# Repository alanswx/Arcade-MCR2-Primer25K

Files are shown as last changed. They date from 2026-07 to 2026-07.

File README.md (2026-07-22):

# Bally Midway MCR2 Arcade Core for Gowin Tang FPGAs

Standalone port of the Bally Midway MCR-2 arcade hardware (Tron, Domino
Man, Satan's Hollow, Wacko, Kozmik Kroozr, Two Tigers) for Sipeed Tang
FPGA boards — no MiSTer/HPS required. The flagship target is the **Tang
Console 60K**: all six games in one bitstream, selected at runtime from an
on-screen menu, with ROMs loaded from a microSD card.

| Board | Status |
|---|---|
| **Tang Console 60K** (GW5AT-60) | All six games + OSD menu; 720p HDMI with audio (DDR3 framebuffer); analog RGB at 31/15 kHz for real cabinets; USB gamepad; SD ROM loading |
| Tang Primer 25K (GW5A-25) | Domino Man over HDMI (single game per build, BSRAM-limited) |
| Tang Console 138K (GW5AST-138) | Stale — needs the 60K backport |

New here? Read [handoff_v4_60k_multicore.md](handoff_v4_60k_multicore.md)
for the current platform state and family runway.

Deeper docs: build gotchas and architecture notes in [CLAUDE.md](CLAUDE.md),
open issues in [TODO.md](TODO.md), bench hookup in
[docs/bench_wiring.md](docs/bench_wiring.md), cabinet shield spec in
[docs/universal_mcr_shield_spec.md](docs/universal_mcr_shield_spec.md),
porting plan for the other MCR generations in
[docs/mcr_core_roadmap.md](docs/mcr_core_roadmap.md).

---

## 1. Generate the ROM hex tables

ROM zips (MAME sets) go in `roms/` — they are **not** in the repo. Then,
from the repo root:

```sh
python3 tools/merge_roms.py tron     # or domino / shollow / wacko / kroozr / twotiger
```

This writes the `rom_*.hex` tables the build bakes into BSRAM and sets the
board's `game_config.vh`. On the 60K the baked game only decides **what
boots with no SD card** — every game is reachable at runtime from the OSD.

## 2. Build

Headless (recommended; macOS paths shown — see CLAUDE.md for why the IDE
flow needs extra care):

```sh
GWLIB=/Applications/GowinIDE.app/Contents/Resources/Gowin_EDA/IDE/lib
GW=/Applications/GowinIDE.app/Contents/Resources/Gowin_EDA/IDE/bin/gw_sh
cd mcr2_console60k
DYLD_LIBRARY_PATH="$GWLIB" DYLD_FRAMEWORK_PATH="$GWLIB" "$GW" build.tcl
```

The bitstream lands at `mcr2_console60k/impl/pnr/mcr2_console60k.fs`.
Prebuilt images for all six games are kept in `bitstreams/`.

IDE builds work too (open `mcr2_console60k/mcr2_console60k.gprj`, Run All)
but several project settings must be exactly right — read the Gotchas
table in CLAUDE.md first; in particular **Place & Route → Place Option
must be 2** or HDMI silently dies.

## 3. Flash the board

With [openFPGALoader](https://github.com/trabucayre/openFPGALoader)
(`brew install openfpgaloader`), board connected over USB-C:

```sh
# quick test - loads SRAM, lost at power-off
openFPGALoader -b tangconsole bitstreams/console60k_tron.fs

# make it the POWER-ON default - writes the SPI flash
openFPGALoader -b tangconsole -f bitstreams/console60k_tron.fs
```

The `-f` form replaces whatever was in flash (e.g. NESTang) — reflash that
the same way if you want it back. The Gowin Programmer GUI works as well
(External Flash Mode → exFlash Erase, Program).

## 4. Make the SD card (all six games, switchable from the menu)

The ROM pack lives in **raw sectors starting at sector 2048** (1 MiB in) —
no filesystem involved, and it coexists with a normally-formatted card
(standard SD formatting starts the first partition at 4 MiB+; existing
files are untouched).

```sh
python3 tools/make_rompack.py                 # builds mcr_rompack.img from roms/
sudo python3 tools/write_rompack.py           # lists candidate cards
sudo python3 tools/write_rompack.py disk4     # writes + verifies (macOS)
```

`write_rompack.py` refuses to touch anything that is not a removable disk,
refuses cards whose partitions would overlap the pack, and verifies the
header after writing. On Linux/Windows use the `dd`/Win32DiskImager recipe
that `make_rompack.py` prints.

Put the card in the **console's** microSD slot. Every game you select in
the OSD is saved to the card (a reserved sector below the pack), and the
next power-on boots straight back into it - so a cabinet owner picks a
game once and it sticks. With no card (or a blank prefs sector) the
baked-in game boots.

## 5. Play

- **USB gamepad** in the left USB-A port: D-pad = joystick, A = Button 1,
  Start = Start 1, Select = Coin 1 (B/X/Y vary per game — see the input
  maps in `mcr2_console60k_top.sv`).
- **Select+Start opens the game-select menu** on every video output:
  Up/Down move, A loads the highlighted game from the SD card, B exits.
  The screen freezing (HDMI) or dropping sync (analog) for ~1 s after
  pressing A is the ROM reload, not a crash.
- Board keys: AA13 = reset, AB13 = Coin 1.
- HDMI is always live at 720p. Analog RGB comes out of the J10 header
  (31 kHz VGA, or jumper J10-37 to GND for native 15 kHz arcade timing) —
  wiring recipes in [docs/bench_wiring.md](docs/bench_wiring.md).
- A UART status beacon prints on the USB-C serial port (115200 8N1) for
  case-closed debugging — field decoding in docs/bench_wiring.md.

## 6. Cabinet integration

The goal is a drop-in board for real MCR cabinets: analog 15 kHz RGB,
original harness connectors, physical DIPs for game options. For anyone
building the PCB: the **frozen 40-pin header sheet is
[docs/shield_j10_pinout.md](docs/shield_j10_pinout.md)** — one header
carries video, audio and all controls (inputs via a 74HC165 chain that
covers every game, outputs via 74HC595). The consolidated electrical spec
is [docs/universal_mcr_shield_spec.md](docs/universal_mcr_shield_spec.md);
per-game harness pinouts are in
[docs/mcr_game_input_matrix.md](docs/mcr_game_input_matrix.md).

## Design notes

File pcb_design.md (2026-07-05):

# Universal MCR Daughterboard PCB Design Specification

This document details the physical layout, component placement, and schematic netlist for the **Universal Bally Midway MCR Cabinet Interface Shield** designed to host the **Tang Console 60K/138K**. It includes an ASCII floorplan and a **KiCad Python Script** to programmatically generate the board layout.

---

## 1. PCB Floorplan (ASCII Layout Sketch)

The PCB is designed as a roomy carrier shield (approx. **135mm x 95mm**) that sits directly underneath the Tang Console board, exposing the original cabinet connectors along the top and bottom edges.

KiCad Layout Render

```text
+-----------------------------------------------------------------------------------+
|  [J2: P1 Ctrl]     [J3: Coin/Start]      [Video Output]       [Power Input +12V]  |
|  (Molex 15-pin)      (Molex 5-pin)        (Molex 9-pin)         (Screw Terminal)  |
|                                                                                   |
|    +---------------------------------------------------------+   +------------+   |
|    |               Tang Console 60K/138K Socket              |   | 5V Buck    |   |
|    |               (Exposes 2x20 Pin Header 1)               |   | Regulator  |   |
|    +---------------------------------------------------------+   +------------+   |
|                                                                                   |
|  [Optocouplers]                                                  [Audio Amp]      |
|  (TLP281-4)                                                      (LM386 + Caps)   |
|                                                                                   |
|    +---------------------------------------------------------+   [Audio Out]      |
|    |               Tang Console 60K/138K Socket              |   (Screw Term)     |
|    |               (Exposes 2x20 Pin Header 2)               |                    |
|    +---------------------------------------------------------+                    |
|                                                                  [DAC Resistors]  |
|                                                                  (R2R Networks)   |
|  [J5: P2 / Trackball]                 [J4: Opt X / Spinner]                       |
|  (Molex 19-pin)                         (Molex 10-pin)                            |
|                                                                                   |
|                     [SW1: Game Sel]      [SW2: Options]                           |
|                     (8-Position DIP)     (8-Position DIP)                         |
+-----------------------------------------------------------------------------------+
```

---

## 2. Schematic Netlist Configuration

The daughterboard connects the Tang Console 2x20 headers directly to the cabinet connectors and onboard modules:

### Power Distribution Nets
*   `+12V_CAB` $\rightarrow$ Screw Terminal Pin 1 $\rightarrow$ Audio Amp VCC, Buck Regulator Input.
*   `GND` $\rightarrow$ Common ground across all connectors, switches, and regulators.
*   `+5V_REG` $\rightarrow$ Buck Regulator Output $\rightarrow$ Tang Console 5V input pins (Header 1).
*   `+3.3V_FPGA` $\rightarrow$ Tang Console 3.3V output pins (Header 2) $\rightarrow$ DIP Switch pull-ups, optocoupler output pull-ups.

### Video DAC Nets
*   `cab_r[2:0]` $\rightarrow$ R2R Resistor Network $\rightarrow$ `MCR_RED` $\rightarrow$ `Video-1`
*   `cab_g[2:0]` $\rightarrow$ R2R Resistor Network $\rightarrow$ `MCR_GREEN` $\rightarrow$ `Video-3`
*   `cab_b[2:0]` $\rightarrow$ R2R Resistor Network $\rightarrow$ `MCR_BLUE` $\rightarrow$ `Video-5`
*   `cab_hs` $\rightarrow$ NPN Transistor Buffer $\rightarrow$ `MCR_HSYNC` $\rightarrow$ `Video-8`
*   `cab_vs` $\rightarrow$ NPN Transistor Buffer $\rightarrow$ `MCR_VSYNC` $\rightarrow$ `Video-9`
*   `Video GND` $\rightarrow$ Connected directly to `GND` $\rightarrow$ `Video-2, Video-4, Video-6`

---

## 3. KiCad PCB Python Generation Script

To prevent code desynchronization, the Python generator script is maintained separately at [`tools/generate_pcb.py`](file:///Users/alans/Documents/development/Arcade-MCR2-TangFPGA/tools/generate_pcb.py).

### How to Run the Generator:
To programmatically generate the layout or apply changes to coordinates, execute the script from your terminal using KiCad's bundled Python interpreter:

```bash
# Run the script to generate or update 'mcr_shield.kicad_pcb'
/Applications/KiCad/KiCad.app/Contents/Frameworks/Python.framework/Versions/3.9/bin/python3 tools/generate_pcb.py
```

After running the script, the updated board database is saved directly to [`mcr_shield.kicad_pcb`](file:///Users/alans/Documents/development/Arcade-MCR2-TangFPGA/mcr_shield.kicad_pcb). You can open this file in KiCad PCB Editor to view and route the traces.

---

## 4. Power Supply & Level-Shifting Specification

Arcade cabinets are electrically noisy environments. Proper power isolation and input level-shifting are critical to ensure that the delicate FPGA logic is not damaged and does not suffer from glitches.

### A. Power Supplies Required
Original MCR cabinets deliver:
1.  **+5V DC (Logic):** Used to power TTL ICs on the original boards.
2.  **+12V DC (Audio):** Used to run the audio power amplifiers.
3.  **-5V DC (Bias):** Used only by legacy dynamic RAMs (4116 DRAM). 
    *   *Our core runs 100% on-chip static BRAM, so **we do not need the -5V rail at all**.*

**How we power the FPGA:**
*   We route the cabinet's **+12V DC rail** to an onboard **step-down Buck Regulator module** (e.g. LM2596 or similar buck converter) on our shield. The regulator outputs a rock-solid, filtered **+5.0V DC** (1.5A rating) which is routed directly to the Tang Console's 5V input pin.
*   This isolates the FPGA from noise on the cabinet's main +5V logic lines and prevents brownouts when solenoids or coin door lights trigger.

### B. Input Level-Shifting (Cabinet Controls)
*   **The Hazard:** Standard arcade cabinet switches can pick up high-voltage static shocks (ESD) or line noise from the CRT monitor. Since the Gowin FPGA GPIOs are **strictly 3.3V tolerant**, connecting long wire loops directly to the pins will eventually destroy the FPGA.
*   **The Solution (Optocouplers):** We place **TLP281-4 (or EL817-4) quad optocouplers** on all cabinet input lines (joysticks, buttons, coins).
    *   The cabinet loop runs at +5V/12V through the optocoupler's input LED.
    *   When a switch is closed, it triggers the internal LED.
    *   The output photo-transistor bridges the FPGA GPIO directly to `GND` (pulled up to `+3.3V` internally).
    *   This provides **100% electrical isolation** between the cabinet and the FPGA.

### C. Output Level-Shifting (Video Sync)
*   **Sync Signals:** Arcade CRT monitors expect **5V TTL composite sync** signals. The FPGA outputs 3.3V. While some monitors may work, it is best practice to place a buffer IC (like a **74LVC244** or **74HCT244**) powered by +5V to step up the 3.3V HSync, VSync, and CSync signals to solid 5V TTL levels before routing them to the video connector.
*   **RGB Colors:** The R2R resistor network naturally performs the level-shifting from 3.3V digital logic to the analog 0.7V peak-to-peak expected by the CRT monitor. **No active buffer or level shifter is needed for RGB signals.**

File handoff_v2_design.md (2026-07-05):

# MCR2 Port V2 Handoff & PCB Design Specification

This document details the architectural path to upgrade the core to **Version 2 (SDRAM support)** and outlines the electrical/physical requirements to design a custom **Universal Bally Midway MCR Cabinet Interface Shield (Option A)** that plugs into the Tang Primer 25K Dock.

---

## 1. SDRAM Integration & Core Changes (V2)

In Version 1, the playfield background tile ROMs were disabled to free up Block RAM (BSRAM) blocks for the active RAM caches and line buffers. In Version 2, we will add the external SDRAM controller to store all ROM assets, freeing up internal BSRAM and enabling playfield graphics and cabinet artwork overlays.

```mermaid
graph TD
    Flash[SPI Flash / SD Card] -->|Boot Loader| SDRAM_Ctrl[SDRAM Controller]
    SDRAM_Ctrl <--> SDRAM[External SDRAM Module]
    Z80_Main[Z80 CPU Main] -->|Instruction Fetch| SDRAM_Ctrl
    Z80_Snd[Z80 CPU Sound] -->|Instruction Fetch| SDRAM_Ctrl
    Gfx_Gen[Graphics Generator] -->|Tile Read| SDRAM_Ctrl
```

### Key Changes Required in RTL
1. **Porting the SDRAM Controller:**
   * Copy the SDRAM controller from the Nestang project ([sdram.sv](file:///Users/alans/Documents/development/TangPrimer-25K-example/nestang_primer-25K/src/rtl/sdram.sv)). The Primer 25K SDRAM module is a standard SDR-SDRAM (typically 64Mbit or 128Mbit with a 16-bit wide data bus).
2. **Boot ROM Loader:**
   * Implement a boot loader state machine in the top wrapper (`mcr2_primer25k_top.sv`). 
   * On reset, this loader reads the game ROM binaries from the SPI Flash (at a offset like `0x100000`) or from a MicroSD card via SPI, and streams them into the SDRAM.
   * Once loading is done, the Z80 reset line is released and the game runs.
3. **Memory Bus Arbitration:**
   * Since the main CPU, sound CPU, sprite generator, and background generator all need to read from SDRAM, you must implement a simple round-robin arbiter inside the controller. The controller runs at **100MHz+**, giving enough bandwidth to multiplex requests from all four subsystems.
4. **Restoring Graphics in `mcr2.vhd`:**
   * Re-enable the instantiations of `bg_graphics_1` and `bg_graphics_2` and change their generic memory type to point to SDRAM read requests instead of internal `dpram` instances.

---

## 2. Universal MCR Cabinet Interface Shield PCB Design

Rather than translating signals to a modern standard like JAMMA, the shield can expose the **original Bally Midway MCR header connectors (J2, J3, J4, J5, and Video)**. 

This creates a **direct drop-in replacement** for the original bulky Bally Midway CPU board. You can unplug the original board from the cabinet, and plug the Tang Primer 25K + Dock + Shield assembly directly into the cabinet's original wire harness.

### Why No DIP Switches Are Needed:
As documented in the `Ultimate MCR Master Pinout Matrix`, the physical connectors and pinout routing are standard across all MCR-1, MCR-2, and MCR-3 games. 
* A physical pin like **J2-1** is routed to standard player controls in all cabinets, but its function changes depending on the game (e.g. Up in *Tron*, Left in *Satan's Hollow*, Machine Gun in *Spy Hunter*).
* Because all J2/J3/J4/J5 pins are routed to static, dedicated FPGA GPIO inputs, **no physical DIP switches or rewiring is needed on the PCB**. The mapping of inputs to gameplay functions is handled **entirely in the SystemVerilog wrapper** of each specific game core!

```
                    +------------------------------------+
                    |        Tang Primer 25K Dock        |
                    +---[PMOD 1]------------[40-Pin]-----+
                              |                |
                       Parallel GPIOs     Parallel GPIOs
                              |                |
                    +------------------------------------+
                    |       Universal MCR Shield PCB     |
                    +--[J2]----[J3]----[J4]----[J5]--[V]-+
```

### A. Power Delivery
The original MCR cabinet harness provides **+12V** (for audio amps) and **+5V** (for logic).
* Place a **5V step-down buck converter** on the shield to feed clean +5V into the Dock's power inputs.
* Route the +12V rail directly to the onboard audio amplifier.

### B. Input Protection & Level Shifting
Arcade cabinet buttons are connected to long wire harnesses that act as antennas for ESD and electromagnetic noise.
* Use **opto-isolators** (e.g., TLP281-4) or logic buffers (e.g., 74LVC244) to isolate cabinet inputs from the FPGA.
* Use external 4.7kΩ pull-up resistors to 5V on the cabinet side of the buffers to keep inputs stable.

```
 Cabinet Switch (GND) ---> [ 4.7k Pull-up to 5V ] ---> [ Optocoupler / Buffer ] ---> FPGA Pin (3.3V)
```

### C. Analog Video DAC (RGB + Sync)
Midway MCR games output video at a 15kHz horizontal sync rate. The daughterboard must convert the 3-bit digital color lines (`cab_r/g/b`) to standard analog $1\text{V}_{\text{p-p}}$ video.
* **Resistor Ladder DAC (R2R):** Use standard 1% resistors to build an R2R ladder DAC for the red, green, and blue outputs.
* **Sync Buffers:** Convert the digital Sync outputs (`cab_hs` and `cab_vs` or `cab_csync`) from 3.3V to 5V TTL levels using a simple NPN transistor driver (like the BC847) before sending them to the original MCR Video connector.

```
 cab_r[2] (MSB) ---> [ 510 Ohm ] ---+
                                    |---> Analog Red (75 Ohm load on monitor)
 cab_r[1]       ---> [  1k Ohm  ] ---+
 cab_r[0] (LSB) ---> [  2k Ohm  ] ---+
```

### D. Audio Circuit
* Route the `audio_l` and `audio_r` pins through a dual-stage RC low-pass filter (cutoff frequency around 15kHz) to smooth the digital PWM into analog audio.
* Feed the analog audio into an audio amplifier chip (e.g., **LM386** or **TDA2003**) powered by the +12V rail, and connect the output to the mono speaker terminals.

---

## 3. Recommended Pinout Mapping (Dock to MCR Connectors)

Below is the pin mapping showing how the FPGA's expansion ports should route to the standard MCR J2, J3, J4, and J5 headers.

### J2 Connector (Player 1 Controls)
| Pin | Standard MCR Function | Dock Pin |
| :--- | :--- | :--- |
| **J2-1** | P1 Up / P1 Left / Weapon 1 | PMOD 1.4 (L5) |
| **J2-2** | P1 Down / P1 Right / Weapon 2 | PMOD 1.10 (K5) |
| **J2-3** | P1 Left / Utility Button | PMOD 1.3 (K11) |
| **J2-4** | P1 Right / Utility Button | PMOD 1.9 (L11) |
| **J2-5** | P1 Button 1 (Fire / Serve / Kick) | PMOD 1.2 (E11) |
| **J2-6** | P1 Button 2 (Shield / Catch / Deflect) | PMOD 1.1 (A11) |
| **J2-13**| Ground | PMOD 1.5 (GND) |

### J3 Connector (System & Coins)
| Pin | Standard MCR Function | Dock Pin |
| :--- | :--- | :--- |
| **J3-1** | Coin 1 | PMOD 1.9 (L11) *shared/dual-mapped* |
| **J3-2** | Coin 2 | PMOD 1.8 (E10) |
| **J3-3** | Start 1 | PMOD 1.10 (K5) *shared/dual-mapped* |
| **J3-4** | Start 2 | PMOD 1.7 (A10) |
| **J3-5** | Tilt Switch | PMOD 1.7 (A10) *shared/dual-mapped* |

### J4 Connector (Opt X / Spinner / Steering Dial)
These pins handle the 8-bit parallel dial/spinner outputs (like Tron's spinner wheel or Spy Hunter's steering):
| Pin | Standard MCR Function | Dock Pin |
| :--- | :--- | :--- |
| **J4-1** | Data Bit 0 (Opt X) | 40-Pin 5 (H4) |
| **J4-2** | Data Bit 1 (Opt X) | 40-Pin 6 (G4) |
| **J4-3** | Data Bit 2 (Opt X) | 40-Pin 7 (J2) |
| **J4-4** | Data Bit 3 (Opt X) | 40-Pin 8 (J8) |
| **J4-5** | Data Bit 4 (Opt X) | 40-Pin 9 (J1) |
| **J4-6** | Data Bit 5 (Opt X) | 40-Pin 10 (D1) |
| **J4-7** | Data Bit 6 (Opt X) | 40-Pin 11 (L9) |
| **J4-9** | Data Bit 7 (Opt X) | 40-Pin 12 (K8) |
| **J4-10**| Ground | 40-Pin 2 (GND) |

### J5 Connector (Opt Y / Trackball / Player 2 Controls)
| Pin | Standard MCR Function | Dock Pin |
| :--- | :--- | :--- |
| **J5-1** to **J5-6** | Player 2 Mux / Trackball Y (D0 - D5) | 40-Pin 13 to 18 |
| **J5-15** | P2 Up / Trackball Y D6 | 40-Pin 19 |
| **J5-16** | P2 Down / Trackball Y D7 | 40-Pin 20 |
| **J5-17** | P2 Left | 40-Pin 21 |
| **J5-18** | P2 Right | 40-Pin 22 |
| **J5-19** | P2 Button 1 | 40-Pin 23 |

### Video Connector (MCR Standard)
| Pin | MCR Video Function | Dock / DAC Signal |
| :--- | :--- | :--- |
| **Video-1** | Red | Analog Red (from DAC on K2, K1, L1) |
| **Video-2** | Video GND | Video Ground |
| **Video-3** | Green | Analog Green (from DAC on L2, K4, J4) |
| **Video-4** | Video GND | Video Ground |
| **Video-5** | Blue | Analog Blue (from DAC on G1, G2, E1) |
| **Video-6** | Video GND | Video Ground |
| **Video-8** | H-Sync (-) | Sync Buffer (from F1 / A1) |
| **Video-9** | V-Sync (-) | Sync Buffer (from F2) |

---

## 4. Pinout Mapping for Tang Console 60K & 138K (2x20 Header Shield)

Because the **Tang Console 60K & 138K** cores fit entirely inside the FPGA's internal BRAM, you have **92 free GPIO pins** on the board's two 2x20-pin expansion headers. This allows for a completely parallel shield design with zero multiplexing or serial converters.

Below is the pin mapping between the original Bally Midway MCR harness and the 2x20 GPIO Header pins as defined in `mcr2_console60k.cst` and `mcr2_console138k.cst`:

### Cabinet Controls (J2 & J3)
| MCR Pin | Signal | 2x20 Header Pin Name | FPGA Pin |
| :--- | :--- | :--- | :--- |
| **J2-1** | P1 Up / Left | `btn_left` | A10 |
| **J2-2** | P1 Down / Right | `btn_right` | A11 |
| **J2-3** | P1 Left / Utility | `btn_fire` | B10 |
| **J2-4** | P1 Right / Utility | `btn_shield` | B11 |
| **J2-5** | P1 Button 1 (Fire) | `btn_start` | C10 |
| **J2-6** | P1 Button 2 (Shield) | `btn_coin` | C11 |
| **J3-1** | Coin 1 | `btn_service` | D10 |
| **J3-3** | Start 1 | `btn_tilt` | D11 |

### Cabinet Video (RGBS) & Audio Outputs
| MCR Pin | Signal | 2x20 Header Pin Name | FPGA Pin |
| :--- | :--- | :--- | :--- |
| **Video-1** | Analog Red | `cab_r[0]` (LSB) | F10 |
| | | `cab_r[1]` | F11 |
| | | `cab_r[2]` (MSB) | G10 |
| **Video-3** | Analog Green | `cab_g[0]` (LSB) | H10 |
| | | `cab_g[1]` | H11 |
| | | `cab_g[2]` (MSB) | J10 |
| **Video-5** | Analog Blue | `cab_b[0]` (LSB) | K10 |
| | | `cab_b[1]` | K11 |
| | | `cab_b[2]` (MSB) | L10 |
| **Video-8** | H-Sync (-) | `cab_hs` | M10 |
| **Video-9** | V-Sync (-) | `cab_vs` | M11 |
| | CSync (-) | `cab_csync` | N10 |
| | Audio Left PWM | `audio_l` | P10 |
| | Audio Right PWM | `audio_r` | P11 |

### Hardware Configuration DIP Switches (Game & Settings Selector)
These pins map the two 8-position DIP switch blocks on the custom shield to the FPGA:

| DIP Block | Switch | Signal | 2x20 Header Pin Name | FPGA Pin |
| :--- | :--- | :--- | :--- | :--- |
| **Block 1 (Game Selector)** | SW1.1 | Game Selector Bit 0 | `game_sel[0]` | R10 |
| | SW1.2 | Game Selector Bit 1 | `game_sel[1]` | R11 |
| | SW1.3 | Game Selector Bit 2 | `game_sel[2]` | T10 |
| | SW1.4 | Game Selector Bit 3 | `game_sel[3]` | T11 |
| | SW1.5 | Game Selector Bit 4 | `game_sel[4]` | U10 |
| | SW1.6 | Config Mode Bit 0 | `game_sel[5]` | U11 |
| | SW1.7 | Config Mode Bit 1 | `game_sel[6]` | V10 |
| | SW1.8 | Config Mode Bit 2 | `game_sel[7]` | V11 |
| **Block 2 (Game Options)** | SW2.1 | original DIP 1 (Coinage) | `game_opt[0]` | W10 |
| | SW2.2 | original DIP 2 | `game_opt[1]` | W11 |
| | SW2.3 | original DIP 3 (Difficulty) | `game_opt[2]` | Y10 |
| | SW2.4 | original DIP 4 | `game_opt[3]` | Y11 |
| | SW2.5 | original DIP 5 (Lives) | `game_opt[4]` | AA10 |
| | SW2.6 | original DIP 6 | `game_opt[5]` | AA11 |
| | SW2.7 | original DIP 7 (Demo Sound) | `game_opt[6]` | AB10 |
| | SW2.8 | original DIP 8 (Test Mode) | `game_opt[7]` | AB11 |

*Note: You can easily update these constraints in your target project's `.cst` file to match whatever layout you choose for your custom KiCad or Altium PCB Shield.*

---

## 5. DIP-Switch ROM Selection & Game Lists (Multi-Game Cabinet)

Instead of compiling an on-screen game loader, we can place a hardware **DIP Switch Block** on our custom Shield PCB to select which game boots from the MicroSD card. At power-on, the bootloader reads the states of these switches and writes the corresponding ROM assets into BRAM/DRAM, creating an authentic, menu-free arcade experience.

### A. Bally Midway MCR Game Lists

The Bally Midway MCR family is split into five hardware categories:

1. **MCR-1 (3 Games):**
   * *Kick / Kick-Man*
   * *Solar Fox*
2. **MCR-2 (6 Games):**
   * *Satan's Hollow*
   * *Tron*
   * *Kozmik Krooz'r*
   * *Wacko*
   * *Domino Man*
   * *Two Tigers*
3. **MCR-3 (4 Games):**
   * *Tapper*
   * *Discs of Tron*
   * *Journey*
   * *Timber*
4. **MCR-Scroll (3 Games):**
   * *Spy Hunter*
   * *Crater Raider*
   * *Turbo Tag*
5. **MCR-Monoboard (6 Games):**
   * *Demolition Derby*
   * *Rampage*
   * *Sarge*
   * *Power Drive*
   * *Max RPM*
   * *Star Guards*

*   **Total Unified Library:** **22 Games**

---

### B. Bit Requirements for DIP Switch Selection

To select a game from these lists, we need the following number of binary inputs:

*   **MCR-2 Only Multi-Game:** **3 Bits** ($2^3 = 8$ configurations, covers all 6 MCR-2 titles).
*   **MCR-3 Only Multi-Game:** **2 Bits** ($2^2 = 4$ configurations, covers all 4 MCR-3 titles).
*   **Fully Unified MCR Cabinet:** **5 Bits** ($2^5 = 32$ configurations, covers all 22 MCR games in the library).

### C. Recommended Hardware Design

We recommend placing an **8-position DIP Switch Block** on the custom Shield PCB. 
*   **Switch 1–5:** Game Selector (5 bits, representing binary values `0` to `31` for the 22 games).
*   **Switch 6–8:** System Config (e.g. Free Play force, Test Mode force, Cabinet CRT aspect/doubler bypass).

```text
               +5V / +3.3V
                 |
               [ 10k Pull-up Array ]
                 |
  FPGA GPIOs ----+-------+-------+-------+
                 |       |       |       |
               [SW1]   [SW2]   [SW3]   [SW4]  (DIP Switch Block)
                 |       |       |       |
                GND     GND     GND     GND
```
*   **Pins needed:** Since the **Tang Console 60K/138K** has 92 free GPIOs, allocating **8 dedicated pins** directly to these switches is trivial and leaves the board with massive IO capacity.

---

## 6. Physical Game Options DIP Switches (Coinage, Difficulty, Lives)

On the original arcade CPU boards, a physical 8-position DIP switch block allowed operators to set game difficulty, coinage, lives, and test modes. 

*   **Virtual OSD (MiSTer):** In emulation setups, these settings are virtualized and adjusted via the On-Screen Display (OSD) menu, writing to virtual registers (`input_3`/`input_4`).
*   **Physical Shield (Tang Console):** For an authentic cabinet integration, we place a second physical **8-position DIP Switch Block** on the custom Shield PCB. The FPGA routes these switches directly to the core's input registers, allowing you to configure the cabinet settings by flipping hardware switches inside the coin door.

### Unified Pin Budget Math (Tang Console 60K/138K)
Because the Tang Console offers **92 free GPIO pins**, we can route every single arcade subsystem in parallel without any multiplexing:

1.  **Cabinet Controls (J2 & J3):** 8 pins
2.  **Spinner / Steering (J4 - Opt X):** 8 pins
3.  **Player 2 / Trackball (J5 - Opt Y):** 13 pins
4.  **Cabinet Video (RGBS + CSync):** 12 pins
5.  **PWM Audio Outputs:** 2 pins
6.  **ROM Game Selector DIP Switches:** 8 pins (5 for games, 3 for system configuration)
7.  **Original Game Option DIP Switches:** 8 pins (Difficulty, Coinage, Lives)

*   **Total Pins Required:** **59 pins**
*   **Pins Remaining Free:** **33 pins** (Leaves massive expansion capacity on the 92-pin headers)

---

## 7. Multi-Game Implementation: Unified Core vs. Gowin Multi-boot

To support the 22 games in the Bally Midway library, we have two hardware implementation architectures available:

### Option A: The Unified "Super-Core"
We compile a single, parameterizable FPGA bitstream containing the shared Z80 CPUs and a multiplexed video/audio engine. 
*   **Resource Footprint:** Takes approximately **18,000 to 20,000 LUTs** (fits comfortably in 33% of the GW5A-LV60's capacity).
*   **How it works:** The bootloader reads the game selector DIP switches at startup, loads the corresponding ROM assets from the SD card into BRAM/DRAM, and dynamically toggles the video scanlines, palette depth, and sound engine routing (AY-3-8910 vs. Cheap Squeak Deluxe) to match that game.

### Option B: Gowin Multi-Boot (Dynamic Hardware Reconfiguration)
Instead of writing a complex unified Verilog core, we leverage the Gowin FPGA's built-in **Multi-boot (IPREPROGRAM)** feature:
*   **How it works:**
    1.  We compile separate, optimized dedicated bitstreams for each generation: `mcr1.fs`, `mcr2.fs`, `mcr3.fs`, `mcr_scroll.fs`, and `mcr_mono.fs`. These are written to different sectors of the SPI Flash or saved as files on the MicroSD card.
    2.  The FPGA is programmed to load a tiny, lightweight **Bootloader Core** (occupying < 1,000 LUTs) on power-up.
    3.  The bootloader reads the Game Selector DIP switches, selects the target bitstream, and triggers a hardware **reprogram command** inside the FPGA.
    4.  Within **50 milliseconds**, the FPGA physically morphs/reprograms itself to become a dedicated MCR-1, MCR-2, MCR-3, Scroll, or Monoboard chip and boots the game.
*   **Benefit:** This is the most robust and professional approach. It keeps compile times fast and lets us develop and optimize each core independently without logic bloat.

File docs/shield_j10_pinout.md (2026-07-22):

# Shield ↔ Tang Console 60K: the J10 40-pin header (rev A freeze)

**This is the authoritative pin sheet for the shield PCB.** It supersedes
the draft net plan in `universal_mcr_shield_spec.md` §4b (which spread
video onto the PMOD sockets); the shield now connects to **J10 only** —
video, audio and all controls on one 40-pin header, both PMOD sockets left
free. Electrical details (input-conditioning pads, DAC, buck) stay in the
spec §3; the cabinet-side connectors, pitches and chip wiring are in
**`docs/shield_wiring.md`**.

Ground rules:

- **Interface style (settled): the cabinet harness plugs into the shield.**
  The shield presents the original MCR mating connectors; the operator plugs
  the existing harness in and selects the game in the OSD — the FPGA maps
  every pin to its in-game function, so nothing is rewired. This is NOT a
  mechanical board-swap. **Rev A targets the SSIO-family connectors** (most
  games); MCR3Mono is a later variant. Full rationale + the connector
  target in `universal_mcr_shield_spec.md` §0.
- **Every J10 signal is 3.3 V LVCMOS (banks 6/7/8). Nothing is 5 V
  tolerant.** Cabinet-side 5 V never reaches a header pin: inputs land on
  the shield's **74AHC165s** (5.5 V-tolerant inputs — §2), never on the
  FPGA directly; sync/video leave through buffers/ladders.
- Pins marked **live** are driven by the bitstreams shipping today —
  video/audio works on the board the day it is soldered, with no gateware
  change. Pins marked **reserved** are allocated here and safe to route
  now; the expander RTL that drives them is a small, planned change
  (`TODO.md`). Until then they are high-Z from the FPGA.
- J10 is the 2×20, 2.54 mm header **nearest the PMOD sockets** (the other
  2×20, J9, is the SDRAM slot — the shield must leave it unobstructed).
  Odd/even pins face each other; anchor orientation electrically at
  **pin 11 = +5 V / pin 12 = GND**. Header is net-for-net identical on
  dock rev A (32001A) and rev C (32001C); ball map from the rev C SOM
  sheets (spec §4a/§6.2).

## 1. The 40 pins

| Pin | Ball | Net | Dir (FPGA) | Status | Function |
|---:|---|---|---|---|---|
| 1 | R19 | `VID_R0` | out | live | red bit 0 (= copy of bit 3; DAC may ignore) |
| 2 | P19 | `VID_R1` | out | live | red bit 1 → 2 kΩ |
| 3 | U21 | `VID_R2` | out | live | red bit 2 → 1 kΩ |
| 4 | T21 | `VID_R3` | out | live | red bit 3 (MSB) → 510 Ω |
| 5 | R17 | `VID_B0` | out | live | blue bit 0 (copy of bit 3) |
| 6 | P16 | `VID_B1` | out | live | blue bit 1 → 2 kΩ |
| 7 | T18 | `VID_B2` | out | live | blue bit 2 → 1 kΩ |
| 8 | R18 | `VID_B3` | out | live | blue bit 3 (MSB) → 510 Ω |
| 9 | W17 | `SPARE0` | — | spare | |
| 10 | V17 | `SPARE1` | — | spare | CSI_B config pin — needs the `-use_sspi_as_gpio` build option (already set) |
| 11 | — | **+5 V** | — | power | rail **out of** the dock; light loads only; do NOT back-feed (spec §6.1) |
| 12 | — | **GND** | — | power | star ground for the shield |
| 13 | W22 | `VID_G0` | out | live | green bit 0 (copy of bit 3) |
| 14 | W21 | `VID_G1` | out | live | green bit 1 → 2 kΩ |
| 15 | P17 | `VID_G2` | out | live | green bit 2 → 1 kΩ |
| 16 | N17 | `VID_G3` | out | live | green bit 3 (MSB) → 510 Ω |
| 17 | N14 | `VID_HS` | out | live | HSync, negative; carries **CSYNC** when strap pin 39 = GND |
| 18 | N13 | `VID_VS` | out | live | VSync, negative |
| 19 | V20 | `SPARE2` | — | spare | GCLK-capable |
| 20 | U20 | `SPARE3` | — | spare | GCLK-capable |
| 21 | Y22 | `LED_CALIB` | out | live | status LED: DDR3 trained (steady on = good) |
| 22 | Y21 | `LED_PIX` | out | live | status LED: pixel-clock heartbeat ~1 Hz |
| 23 | AB22 | `LED_27M` | out | live | status LED: 27 MHz heartbeat ~0.8 Hz |
| 24 | AB21 | `LED_DDR_RST` | out | live | status LED: DDR reset (steady OFF = good) |
| 25 | AA21 | `IN_CLK` | out | reserved | 74HC165 chain shift clock (≤2 MHz) |
| 26 | AA20 | `IN_LOAD_N` | out | reserved | 74HC165 SH/LD̄ — low pulse snapshots all inputs atomically |
| 27 | AB20 | `IN_DATA` | in | reserved | serial data from U7.QH (CSO_B config pin — option already set) |
| 28 | AA19 | `OUT_CLK` | out | reserved | 74HC595 chain shift clock (RDWR_B config pin — option already set) |
| 29 | AA18 | `SPARE4` | — | spare | EXIO0: 0 Ω-linked to DM0 net on the dock — verify before use |
| 30 | AB18 | `SPARE5` | — | spare | EXIO1: 0 Ω-linked to DM1 — same caveat |
| 31 | Y19 | `OUT_DATA` | out | reserved | serial data to U8.SER |
| 32 | Y18 | `OUT_LATCH` | out | reserved | 74HC595 RCLK — output register update |
| 33 | T20 | `SERVICE_N` | in | reserved | cabinet service button, direct (opens the OSD); shield pull-up to 3V3 |
| 34 | N15 | `OUT_EN_N` | out | reserved | 74HC595 OE̅. **Shield MUST pull up to 3V3** so meters/lamps stay off until the RTL drives it low |
| 35 | U18 | `AUD_PWM_L` | out | live | PWM audio left → RC filter → amp (spec §3) |
| 36 | U17 | `AUD_PWM_R` | out | live | PWM audio right (mono cabinets: use L only) |
| 37 | R16 | `MODE15_N` | in | live | **strap: GND = native 15 kHz** (cabinet), open = 31 kHz. Internal pull-up; solder-jumper on shield, closed by default |
| 38 | P15 | `SPARE6` | — | spare | |
| 39 | R14 | `SYNC_CSYNC_N` | in | live | strap: GND = composite sync on `VID_HS`; open = separate H/V (**default — real MCR monitors take separate H/V on Video-8/9**) |
| 40 | P14 | `SYNC_VSOFF_N` | in | live | strap: GND = hold VS inactive (single-sync RGBS); open = normal |

Sanity check for layout review: 20 live signals + 3 straps + 8 reserved +
7 spare + 2 power = 40 exactly; every ball above matches spec §4a's
schematic-verified table, and every **live** pin matches what the current
bitstreams already drive (`bench_wiring.md`).

## 2. Power domains and level shifting (read this first)

**All logic on the shield runs at 3.3 V — the 74HC165s, the 74HC595s,
everything that touches a J10 pin. There are no level-shifter ICs
anywhere.** The board has exactly three voltage domains, and every
crossing between them is done by a part that is there for another reason
anyway:

| Domain | What lives in it | Crossing to/from |
|---|---|---|
| **3.3 V logic** (shield LDO from the buck's 5 V — J10 has no 3V3 pin) | shift registers, pull-ups, everything wired to J10 | is the FPGA's native level: direct connection |
| **5 V / cabinet harness** | switch loops (pulled to 5 V via 4.7 kΩ, switched to cabinet GND), monitor sync inputs | **inputs: the 74AHC165s themselves.** AHC inputs are rated to 5.5 V *independent of VCC*, so a 3.3 V-powered '165 legally takes the 5 V harness levels straight in — the shift register IS the level shifter. Each line gets a passive conditioning pad (below), nothing active. **sync out:** 74HCT244 powered at 5 V (its TTL thresholds accept 3.3 V swings — that is why HCT here) or a BC847 stage. **RGB out:** passive R2R ladder, no logic. |
| **12 V loads** | coin meters, lamps | ULN2803 Darlington array (3.3 V logic input is sufficient drive; built-in flyback diodes) |

Part-selection rules that follow:
- Input chain: **74AHC165** (TI SN74AHC165 / Nexperia 74AHC165) at
  VCC = 3.3 V. The load-bearing datasheet line is *"recommended input
  voltage up to 5.5 V regardless of VCC"* — verify it in the exact
  vendor/package chosen at order time. Thresholds at 3.3 V: VIH ≈ 2.3 V
  (5 V idle line: fine), VIL ≈ 1.0 V (closed switch: fine).
- **Plain 74HC165 will NOT work here** (inputs limited to VCC + 0.5 V —
  5 V in on a 3.3 V part is out of spec); 74HCT/74LS are 5 V-supply
  parts. The output '595 sees only 3.3 V signals, so 74HC595 or
  74AHC595 both work.
- The one deliberate HCT part is the 5 V sync buffer, chosen *because*
  of its TTL thresholds. The chain runs at 2 MHz — decades below any of
  these parts' limits.

**Why no optocouplers?** The earlier spec draft used TLP281-4s "for
isolation", but the shield's buck is non-isolated — cabinet ground and
logic ground are already common through the power path, so the optos
never provided galvanic isolation, only over-voltage protection. The
conditioning pad below provides that protection passively. (If a truly
isolated build is ever wanted, it needs an isolated supply first; the
opto variant is preserved in the spec's git history.)

## 3. Input chain — every switch in the cabinet on 3 pins

Seven 74HC165s daisy-chained, read through 3 header pins. `IN_LOAD_N`
snapshots **all 56 bits in the same instant**, which is what makes the
8-bit parallel spinner/trackball buses safe to serialize — no tearing, by
construction. A full scan at 2 MHz takes ~30 µs; the games poll their
inputs once per frame (16.7 ms), so the chain is ~500× faster than
anything the software can observe.

### 3a. Chain control lines ↔ J10 (bussed to all seven '165s)

| Signal | 74HC165 pin(s) | J10 pin | FPGA ball | Direction |
|---|---|---|---|---|
| `IN_CLK` | pin 2 (CP) on U1…U7 | 25 | AA21 | FPGA → chain |
| `IN_LOAD_N` | pin 1 (PL̄) on U1…U7 | 26 | AA20 | FPGA → chain |
| `IN_DATA` | pin 9 (QH) of **U7 only** | 27 | AB20 | chain → FPGA |
| cascade | U1.9 → U2.10, U2.9 → U3.10, … U6.9 → U7.10 | — | — | on-shield |
| tie-offs | pin 15 (CE̅) → GND, pin 10 (SER) of **U1** → GND, pin 7 (Q̄H) n/c, pin 16 → 3V3, pin 8 → GND | — | — | all devices |

Serial arrival order (RTL contract, not a PCB concern): after the load
pulse, bits arrive **U7 first, input H first** — U7.H, U7.G … U7.A, U6.H
… down to U1.A last.

### 3b. '165 inputs ↔ conditioning ↔ MCR harness, device by device

> **This section is the MCR-2 wiring example, and the J-labels below use the
> normalized *cabinet-function* numbering** (J2=P1, J3=coins, J4=Opt X,
> J5=Opt Y) from the master matrix — **not** the physical board connectors.
> The real connectors, their **pitch** (only J1 power is .156"; J2–J6 are
> .100" MTA) and the actual board numbering (J4=IP0+IP1, J5=IP2, J6=IP4) are
> in **`docs/shield_wiring.md`** — use that for footprints. For a board meant
> to run the whole family (3-player Rampage, the mono/scroll connector
> remapping), allocate the chain by SSIO input port — see §6(a). The
> electrical pad and control lines below are unchanged either way.

'165 input pins: A=11, B=12, C=13, D=14, E=3, F=4, G=5, H=6. Each
harness line gets the same passive pad — this is the whole input stage:

    harness pin ──┬── 4.7 kΩ pull-up to +5 V (shield rail)
                  └── 1 kΩ series ──┬── 74AHC165 input
                                    ├── 10 nF to GND (RC ≈ 10 µs — the
                                    │   same line filtering the SSIO had)
                                    └── BAT54S clamp to +5 V / GND
                                        (survives a 12 V miswire: the
                                        fault drops across the 1 kΩ)

Idle = 5 V = high, pressed = low — the same polarity the original SSIO
saw, read by a 3.3 V part with 5.5 V-tolerant inputs. All eight bits of a
dial bus share identical pads, so RC skew between bits is nil and the
atomic '165 load strobe samples a coherent word.

**U1 — player 1 + coins**

| '165 input | pin | MCR harness | Function |
|---|---|---|---|
| A | 11 | J2-1 | P1 Up |
| B | 12 | J2-2 | P1 Down |
| C | 13 | J2-3 | P1 Left |
| D | 14 | J2-4 | P1 Right |
| E | 3 | J2-5 | P1 Button 1 |
| F | 4 | J2-6 | P1 Button 2 |
| G | 5 | J3-1 | Coin 1 |
| H | 6 | J3-2 | Coin 2 |

**U2 — system + P2 switches**

| '165 input | pin | MCR harness | Function |
|---|---|---|---|
| A | 11 | J3-3 | Start 1 |
| B | 12 | J3-4 | Start 2 |
| C | 13 | J3-5 | Tilt |
| D | 14 | J5-17 | P2 Left |
| E | 3 | J5-18 | P2 Right |
| F | 4 | J5-19 | P2 Button 1 (Tron cocktail fire — the FPGA also ORs this with SW1-8, spec §7a; no special wiring) |
| G | 5 | spare pad | tie the '165 input high via its pull-up |
| H | 6 | spare pad | " |

**U3 — Opt X: the 8-bit dial/spinner/trackball-X bus**

| '165 input | pin | MCR harness | Function |
|---|---|---|---|
| A | 11 | J4-1 | Opt X D0 |
| B | 12 | J4-2 | Opt X D1 |
| C | 13 | J4-3 | Opt X D2 |
| D | 14 | J4-4 | Opt X D3 |
| E | 3 | J4-5 | Opt X D4 |
| F | 4 | J4-6 | Opt X D5 |
| G | 5 | J4-7 | Opt X D6 |
| H | 6 | J4-9 | Opt X D7 (J4-8 is the connector key, J4-10 is GND) |

Used by: Tron aim dial, Kick spinner, Kroozr dial, Wacko trackball X,
DoT rotary, Spy Hunter steering (roadmap).

**U4 — Opt Y / P2 stick**

| '165 input | pin | MCR harness | Function |
|---|---|---|---|
| A | 11 | J5-1 | Opt Y D0 |
| B | 12 | J5-2 | Opt Y D1 |
| C | 13 | J5-3 | Opt Y D2 |
| D | 14 | J5-4 | Opt Y D3 |
| E | 3 | J5-5 | Opt Y D4 |
| F | 4 | J5-6 | Opt Y D5 |
| G | 5 | J5-15 | Opt Y D6 / P2 Up |
| H | 6 | J5-16 | Opt Y D7 / P2 Down |

Used by: Wacko trackball Y; P2 stick for Tapper/Timber (roadmap) and
cocktail play.

**U5 — J6 / SSIO IP4 aux port** (J6 pin IDs provisional — the matrix PDF
has no J6 sheet, cross-check a cabinet manual before crimping, `TODO.md`)

| '165 input | pin | MCR harness | Function |
|---|---|---|---|
| A…H | 11,12,13,14,3,4,5,6 | J6-1…J6-8 | IP4 D0…D7: Kroozr stick Y (**needed even upright**), Two Tigers P2 dial, Wacko cocktail aim, DoT aux (roadmap) |

**U6 / U7 — the DIP banks** (on-shield switches: no conditioning pads
needed, and their pull-ups go to 3V3, not 5 V — mixed levels are fine on
5.5 V-tolerant inputs)

| Device | '165 input A…H | Connects to | Function |
|---|---|---|---|
| U6 | pins 11,12,13,14,3,4,5,6 | SW1 positions 1…8, switch→GND, 4.7 kΩ pull-up to 3V3 | game option DIPs = the core's IP3 verbatim (spec §7a); closed = 0 |
| U7 | pins 11,12,13,14,3,4,5,6 | SW2 positions 1…8, same wiring | system DIPs: menu enable, video mode, … (spec §7a) |

## 4. Output chain — meters and lamps (2× 74HC595 = 16 bits)

**Populate two 74HC595s (U8, U9) from the start.** The original single '595
was sized for MCR-2 (2 coin meters + 2 start lamps); vendoring the MCR-3
family showed 8 bits is short: the **MCR3Mono board drives two SSIO output
ports, `output_5` and `output_6` (16 bits)**, and Spy Hunter adds a lamp
panel (`show_lamps`). Two '595s cover it on the same 4 pins (they daisy-
chain, `U8.QH' → U9.SER`); add a third later at zero pin cost. Outputs feed
ULN2803s (cabinet 12 V loads, flyback diodes in the ULN):

| Device.bit | Typical load | Notes |
|---|---|---|
| U8.QA/QB | Coin meter 1 / 2 | all games |
| U8.QC/QD | Start 1 / 2 lamp | |
| U8.QE–QH | player-3 start lamp, game lamps | Rampage is **3-player** |
| U9.QA–QH | `output_6` / Spy Hunter lamp panel | mono + scroll games |

The FPGA maps SSIO `output_4/5/6` (per game) onto these bits; wire the
cabinet's real loads to whichever bits a given game drives.

`OUT_EN_N` (pin 34) **must have a pull-up on the shield**: it holds every
output off from power-on until the gateware takes control — no coin-meter
clicks or lamp flashes during the ~1 s of FPGA configuration.

## 5. Video, audio, straps (live today)

- **DAC:** 3-bit R2R per gun — MSB 510 Ω, 1 kΩ, 2 kΩ (bench-proven values,
  `bench_wiring.md`) summed into the monitor's 75 Ω ≈ 1 Vp-p. Bit 0 of
  each gun is just an MSB copy for 4-bit Pmods — leave it unconnected or
  pad for a future 4th resistor.
- **Sync:** `VID_HS`/`VID_VS` are 3.3 V, negative-going. Buffer to 5 V TTL
  for the cabinet (BC847 stage or 74HCT244 at 5 V, spec §3). Real MCR
  monitors want **separate H and V** (Video conn pins 8/9) — leave the
  pin-39/40 straps open; they exist for OSSC/RetroTink-style RGBS gear.
- **15 kHz:** close the pin-37 solder jumper for a cabinet build. Open =
  31 kHz for bench VGA monitors. HDMI works in both modes regardless.
- **Audio:** PWM out; RC low-pass (~15 kHz corner) → LM386 on the 12 V
  rail → speaker (spec §3). Mono cabinets use `AUD_PWM_L`.
- **Status LEDs (pins 21–24):** route to 4 small LEDs via 1 kΩ. They are
  the case-closed diagnostics: calib steady + pix/27M blinking + ddr_rst
  off = video pipeline healthy.

## 6. Coverage across the WHOLE MCR family (reviewed after vendoring)

The header, pin budget, AHC-direct input stage and (now-16-bit) output
chain all hold up for every MCR family. But vendoring MCR-3/Scroll/Mono
surfaced three things the original MCR-2-era allocation missed — none break
the header, all are allocation/labeling fixes:

**(a) Allocate the input chain by SSIO input PORT, not by MCR-2 function.**
The cores read five bytes `input_0..input_4` (IP0–IP4) and each game maps
its own controls into them. Crucially, **different boards route the same IP
port to different cabinet connectors** — the SSIO board puts IP0/IP1 on J4,
IP2 on J5, IP4 on J6; the MCR3Mono board puts IP0/IP1 on J2, IP2 on J3,
IP4 on J4 (verified in MAME `mcr3.cpp`). So a universal shield should give
each IP port its **own '165 with a clean 8 bits**, wired from whatever
control that cabinet uses, and let the FPGA do the per-game mapping:

| '165 | Byte | Wire from the cabinet's… |
|---|---|---|
| U1 | IP0 | coins, starts, tilt, service, P1 button(s) |
| U2 | IP1 | P1 stick **or** the 8-bit dial/spinner (dial games) |
| U3 | IP2 | P2 stick / trackball-Y / gas pedal (per game) |
| U4 | IP4 | aux: **P3 stick (Rampage)**, P2 dial, Kroozr stick-Y, DoT aux |
| U6/U7 | IP3 | SW1 (game DIPs) / SW2 (system DIPs) |

This is simpler than the old 7-device hybrid (which split P1 across U1 and
coins, and left P2 one bit short) and it covers everything below. The §3b
tables above are the **MCR-2 wiring example**; re-label the screw terminals
by IP port for a universal build.

**(b) 3-player and multi-analog games are real.** Concretely:

| Game(s) | The demand | Covered by |
|---|---|---|
| Domino/Tron/Shollow/Wacko/Kroozr/2Tigers (MCR-2) | 1–2 players, dials, cocktail | U1–U4 (shipping) |
| Kick / Solar Fox (MCR-1) | spinner / stick | U2 |
| Tapper, Timber (MCR-3) | 2 players, 2-way sticks + buttons | U1–U3 |
| **Rampage (Mono)** | **3 players** (3× 8-way + 2 buttons) | IP1/IP2/IP4 = U2/U3/U4 |
| **Spy Hunter (Scroll)** | steering **+** gas (2 analog axes, muxed by an SSIO output bit) + 5 buttons + gear | both on the IP2 byte, alternated by `output_4`; buttons on IP0/IP1; lamps on the '595 chain |
| **Max RPM (Mono)** | **2 wheels + 2 pedals** (4 axes, muxed) | the IP1 byte, alternated by output bits |

The analog axes arrive as **8-bit digital** on their IP byte (the original
MCR control PCB does the pot→ADC conversion; the game time-multiplexes
several axes onto one byte using an SSIO *output* select bit). So the
shield's digital '165 reads them fine **from a cabinet that has that
control PCB**. A bare-potentiometer hookup would need an ADC the shield
does not provide — worth a silkscreen note, but out of scope for a
harness-in build.

**(c) J9 SDRAM is now mandatory, not optional.** Three of the five families
(all of MCR-3/Scroll/Mono) require the Tang SDRAM module in J9 for the
128–256 KB real-time sprite ROM. "Leave J9 clear" (§ ground rules) is a
hard requirement for a board meant to run the whole family, not just
future-proofing.

Bottom line: **the guide still makes sense — the 40-pin header, the
electrical design, and the chain architecture all scale to the full
family.** The updates are: allocate the input chain by IP port (above),
populate 2× '595 (§4), and treat J9 as reserved-mandatory.

## 7. Bring-up order for the board

1. Populate video DAC + sync buffer + audio + straps + LEDs only. Flash
   any current `bitstreams/console60k_*.fs` → full game on the cabinet
   monitor (15 kHz strap closed), sound, LEDs. No new gateware needed.
2. Populate the input-conditioning pads + '165/'595 chains once the
   expander RTL lands (tracked in TODO.md; pins are frozen here, so no
   board spin).
3. USB pad and HDMI work throughout as the reference path.

## 8. Change control

- This table is the contract: `mcr2_console60k.cst`, the expander RTL, and
  `tools/generate_pcb.py` must follow it. If a pin must move, change THIS
  file first, in the same commit.
- Current CST already matches every **live** pin (they are today's bench
  assignments, deliberately). The **reserved** pins appear in the CST only
  when the expander RTL lands.

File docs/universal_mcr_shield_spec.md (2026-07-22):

# Universal MCR Shield — Consolidated Specification

Single source of truth for the cabinet-interface shield that lets a Tang
Console 60K/138K drop into any original Bally Midway MCR-1/2/3 cabinet as a
CPU-board replacement. Consolidates and supersedes the electrical/pinout
content spread across `handoff_v2_design.md` (§2–3, written for the Primer
25K dock) and `pcb_design.md` (floorplan/KiCad, still authoritative for
layout). Game-function reference: `docs/mcr_game_input_matrix.md`.

## 0. Product decisions (2026-07, settled)

- **Interface style: the cabinet harness plugs into the shield** (settled
  2026-07-22). The shield presents the original MCR cabinet connectors as
  headers; the operator plugs the existing harness in and picks the game in
  the OSD — no rewiring, because the FPGA maps every pin to its in-game
  function per the selected game (the '165 chain delivers raw bits; the core
  interprets them). This is explicitly **NOT** a mechanical board-swap
  (the shield does not plug into the cabinet's original PCB-edge socket in
  place of the game board — that would mean replicating each board's edge
  connector and is out of scope). Consequences for the PCB:
  - Route the actual MCR **mating connectors** in the right positions so an
    original harness seats pin-for-pin.
  - **Rev A targets the SSIO-family connectors** (MCR-1/2 + the SSIO MCR-3
    games: Tapper, Timber, Journey, Discs of Tron, Spy Hunter, Crater) —
    the large majority, and the set documented in the master pinout matrix.
  - **MCR3Mono (Rampage, Sarge, Max RPM, Power Drive, Star Guards) is a
    later variant**: those games are absent from the master pinout matrix
    and the mono board routes IP ports to different connectors (IP0/IP1→J2,
    IP2→J3, IP4→J4, 3 players) — verify against the mono board schematic
    before adding its connectors.
  - Special controls (dials/spinners/wheels/pedals) arrive as **8-bit
    digital** on the Opt X/Opt Y connectors; the shield reads them straight
    from a cabinet that still has its MCR control PCB. A bare-pot hookup
    would need an ADC the shield does not provide (silkscreen note).
- **Dual-use, not cabinet-only.** Keep the HDMI path alongside the analog
  cabinet output: it is the primary debug surface, and retrofit-LCD cabinets
  are a real installed base. Consequence: the DDR3 framebuffer stays, so
  **DDR3 is committed to video** and cannot also serve as the ROM store.
- **ROM storage split (as nand2mario/gbatang does on this exact board):**
  DDR3 → framebuffer; **SDRAM module in the J9 slot → game ROMs** for sets
  too big for BRAM; SD card → ROM files and firmware.
- **Configuration by DIP switches, read through a 74HC165 chain** (3 pins
  for 16 switches). Parallel DIPs do not fit: the shield needs 44 of the 54
  I/O available on J10+PMODs, and spending J9 on switches would forfeit the
  SDRAM slot. See §7.
- **Cabinet default is menu-off**: power on straight into the DIP-selected
  game, no OSD reachable by a customer.

## 1. Design principles

1. **Expose the original MCR connectors** so the cabinet harness plugs
   straight in — no JAMMA adaptation. The real board connectors, their
   pin counts and **pitch** (J1 power = .156" MTA; J2 video, J3 audio,
   J4/J5/J6 inputs = .100" MTA) and per-pin functions are in
   **`docs/shield_wiring.md`** / **`docs/MCR Series Pinouts.html`**. (The
   matrix doc uses a normalized *cabinet-function* J-numbering; the
   physical connectors use the real board numbering — see shield_wiring §1.)
2. **No game-specific wiring.** Connector wiring is identical across all
   MCR games; every game-specific *interpretation* lives in the FPGA top.
   One shield serves every core. (DIP switches select which game/core runs
   — they do not rewire anything.)
3. **Serial cabinet I/O — no opto isolation (revised 2026-07).** Cabinet
   inputs run into 74AHC165 shift registers (3 FPGA pins), outputs via a
   74HC595 chain (4 pins); see `shield_wiring.md`. The 74AHC165's 5.5 V-
   tolerant inputs take the 5 V harness directly, so there is no separate
   level shifter. The earlier plan (parallel, opto-isolated) was dropped:
   the shield's buck is non-isolated, so the optos never bought isolation,
   and parallel I/O would forfeit the J9 SDRAM slot (§2).

## 2. FPGA signal budget

**Revised 2026-07-21: the shield connects to J10 ONLY** — one 40-pin
header for video, audio and all controls; both PMOD sockets stay free.
The definitive pin table is **`shield_j10_pinout.md`**; the budget that
makes it fit:

| Group | J10 pins | Direction | Interface |
|---|---:|---|---|
| Video RGB (4:4:4 driven, 3:3:3 significant) | 12 | out | R2R DAC → 1 Vp-p |
| Video sync HS/VS | 2 | out | NPN/74HCT buffer → 5V TTL |
| Audio PWM L/R | 2 | out | RC filter → LM386 |
| Status LEDs | 4 | out | direct |
| Mode/sync straps | 3 | in | solder jumpers |
| **ALL cabinet inputs + both DIP banks** (J2, J3, J4, J5, J6/IP4, SW1, SW2 = 56 bits) | **3** | in | 7× 74AHC165 chain (5 V-tolerant inputs) |
| **All outputs** (coin meters, lamps — mono drives output_5+output_6 = 16 bits) | 4 | out | 2× 74HC595 chain + ULN2803 |
| Service button | 1 | in | direct (opens the OSD) |
| Spares | 7 | — | |
| Power (+5 V out, GND) | 2 | | |
| **Total** | **40** | | |

Serializing the inputs is what makes "every game on one header" possible:
30+ harness lines plus the 8-bit IP4/J6 port plus 16 DIPs would need ~60
parallel pins, forfeiting either video or the J9 SDRAM slot (i.e. the big
MCR-3 titles). The '165 parallel-load strobe snapshots all 56 bits
atomically, so the 8-bit spinner/trackball buses cannot tear, and a full
scan (~30 µs) is ~500× faster than the games' own once-per-frame input
polling. HDMI, USB, SD and DDR3 cost zero shield pins (SOM/dock balls).

## 3. Electrical interface (consolidated)

- **Power:** cabinet +12 V → onboard buck (LM2596/MP1584EN, ≥1.5 A) → 5 V to
  the Console's 5 V input. Do not use the cabinet's +5 V rail (noise/brownout)
  or −5 V rail (not needed — no 4116 DRAMs).
- **Inputs (revised 2026-07-21 — no optos):** harness lines go directly
  into the shield's **74AHC165** shift registers, powered at 3.3 V — AHC
  inputs are rated to 5.5 V independent of VCC, so the '165 itself does
  the 5 V → 3.3 V translation. Per line: 4.7 kΩ pull-up to +5 V, 1 kΩ
  series, 10 nF to GND, BAT54S clamp to +5 V/GND (a 12 V miswire drops
  across the series R). Full pad + rationale in `shield_j10_pinout.md`
  §2/§3b. The earlier TLP281-4 opto plan claimed galvanic isolation the
  non-isolated buck never actually allowed (grounds are common through
  the power path); the pads keep the fault protection at a fraction of
  the parts. Plain 74HC165 is NOT a substitute (inputs limited to
  VCC + 0.5 V).
- **Video RGB:** R2R ladder per gun (510 Ω / 1 kΩ / 2 kΩ for bits 2/1/0)
  into the monitor's 75 Ω load ≈ 1 Vp-p. No active buffer needed.
- **Video sync:** 3.3 V FPGA → BC847 NPN stage (or 74HCT244 powered at 5 V)
  → 5 V TTL negative-going HS/VS on Video-8/9. G07/K4600-style monitors at
  15 kHz; the core must be in `tv15Khz_mode=1` for a real MCR cabinet
  monitor.
- **Audio:** PWM → 2-stage RC low-pass (~15 kHz) → LM386 (12 V rail) → mono
  speaker terminals.

## 4. Dock connector plan (from schematic `Tang_Mega_60K_Console_32001C`, rev 1.3)

The dock's two 2×20 headers are **J9 ("SDRAM0 CONN", near PCIe)** and
**J10 ("SDRAM1 CONN", near the PMODs)** — each carries a full 38-signal
SDRAM-pinout GPIO bus. Architecture decision:

- **J9 — reserved for the Tang SDRAM module** (future frame buffer / ROM
  store; nand2mario cores use these exact pins, `cs_n = F21` on this rev).
- **J10 + PMOD0 + PMOD1 — the shield** (38 + 16 = 54 IOs for ~44 nets).
- USB-A ports remain the controller path; HDMI remains for modern displays.

### 4a. J10 header ↔ FPGA ball map (verified: sheets 4, 6, 8 of rev C PDF)

| J10 pin | Net | Ball | J10 pin | Net | Ball |
|---|---|---|---|---|---|
| 1 | D0 | R19 | 2 | D1 | P19 |
| 3 | D2 | U21 | 4 | D3 | T21 |
| 5 | D4 | R17 | 6 | D5 | P16 |
| 7 | D6 | T18 | 8 | D7 | R18 |
| 9 | D15 | W17 | 10 | D14 | V17 |
| 11 | **+5V** | — | 12 | **GND** | — |
| 13 | D13 | W22 | 14 | D12 | W21 |
| 15 | D11 | P17 | 16 | D10 | N17 |
| 17 | D9 | N14 | 18 | D8 | N13 |
| 19 | A12 | V20 | 20 | CLK | U20 |
| 21 | A9 | Y22 | 22 | A11 | Y21 |
| 23 | A7 | AB22 | 24 | A8 | AB21 |
| 25 | A5 | AA21 | 26 | A6 | AA20 |
| 27 | WE | AB20 | 28 | A4 | AA19 |
| 29 | EXIO0 (=DM0 via 0Ω) | AA18 | 30 | EXIO1 (=DM1 via 0Ω) | AB18 |
| 31 | CAS | Y19 | 32 | RAS | Y18 |
| 33 | CS | T20 | 34 | BA0 | N15 |
| 35 | BA1 | U18 | 36 | A10 | U17 |
| 37 | A0 | R16 | 38 | A1 | P15 |
| 39 | A2 | R14 | 40 | A3 | P14 |

Caveats: **V17 = CSI_B, AB20 = CSO_B/DOUT, AA19 = RDWR_B** are config
dual-purpose pins — synthesis needs the matching `-use_sspi_as_gpio`-family
options (the 25K build.tcl shows the pattern). U20/V20 are GCLK-capable
(bonus, not required). All J10 banks (6/7/8) are 3.3 V.

### 4b. Cabinet pin → J10/PMOD assignment — SUPERSEDED

> **This section is superseded by `shield_j10_pinout.md`** (2026-07-21),
> which puts everything on J10 via input/output shift-register chains and
> keeps the PMODs free. It is retained only as the record of the earlier
> parallel-input plan; do not route from it.

Inputs (all opto-isolated, active low, internal pull-ups):

| Cabinet pin | Function | J10 pin | Ball |
|---|---|---|---|
| J4-1..7,9 | Opt X D0–D7 (dial bus) | 1,2,3,4,5,6,7,8 | R19,P19,U21,T21,R17,P16,T18,R18 |
| J5-1..6 | Opt Y D0–D5 | 18,17,16,15,14,13 | N13,N14,N17,P17,W21,W22 |
| J5-15 | Opt Y D6 / P2 Up | 10 | V17 |
| J5-16 | Opt Y D7 / P2 Down | 9 | W17 |
| J5-17 | P2 Left | 36 | U17 |
| J5-18 | P2 Right | 22 | Y21 |
| J5-19 | P2 Button 1 | 19 | V20 |
| J2-1..6 | P1 Up,Down,Left,Right,B1,B2 | 37,38,39,40,28,25 | R16,P15,R14,P14,AA19,AA21 |
| J3-1..5 | Coin1,Coin2,Start1,Start2,Tilt | 26,23,24,21,34 | AA20,AB22,AB21,Y22,N15 |
| reserved (outputs: coin meters / lamps / J6) | — | 20,27,31,32,33,35,29,30 | U20,AB20,Y19,Y18,T20,U18,AA18,AB18 |

Video/audio on the PMODs (shield covers both sockets):

| Signal | PMOD | Ball |
|---|---|---|
| VID_R[2:0] (R2R) | PMOD0 | V18, V19, G21 |
| VID_G[2:0] (R2R) | PMOD0 | G22, F18, E18 |
| VID_B[2:1] (R2R) | PMOD0 | C22, B22 |
| VID_B[0] (R2R) | PMOD1 | W19 |
| VID_HS / VS / CSYNC (5V TTL buf) | PMOD1 | W20, F19, F20 |
| AUD_PWM_L / R | PMOD1 | E22, D22 |
| spare | PMOD1 | E21, D21 |

**Note:** the current `mcr2_console60k.cst` desk-test assignments (buttons
on PMOD1, provisional cab video) intentionally differ; re-pin to this table
when shield rev A is finalized — cabinet inputs then arrive via the J10
74AHC165 chain and the USB pad, so PMOD desk buttons retire.

+12 V from the cabinet enters the shield at a screw terminal → buck → 5 V.

## 5. RTL requirements per game core

- `tv15Khz_mode = 1` for cabinet use (native 15 kHz RGBS); HDMI path stays
  active concurrently for bring-up.
- Input mapping from nets above into `input_0..input_4` per game, bit
  positions verified against MAME (`mcr.cpp`) — see examples in
  `mcr_game_input_matrix.md`.
- Spinner/trackball (J4/J5 8-bit buses) feed the core's `spinner.sv` /
  analog paths — only needed for dial games (Tron, Kick, Kozmik, Wacko,
  DoT, Spy Hunter).

## 6. Open items

(Also tracked in the repo-root `TODO.md`, alongside the gateware gaps.)

1. **5 V delivery route** — shield buck → console. Preferred: into the
   dock's USB-C power input (goes through the dock's OR-ing/OVP, sheet 3).
   J10 pin 11 exposes a +5 V rail, but whether back-feeding it powers the
   SOM cleanly (it sits behind the OR-ing/OVP/bead chain) is unverified —
   do not use it as an input until traced.
2. **Board revision** — ✅ checked: J10's header pinout is net-for-net
   identical in rev A (32001A, 1.22) and rev C (32001C, 1.3); only the
   footprint differs (TH vs SMD 2×20). Ball map in §4a is from rev C's SOM
   sheets; if a board is identified as rev A, spot-check sheets 4/6 (the
   only known dock-level reroute is SDRAM0_CS: F19 on the old NEO dock →
   F21 now — J9 side, doesn't affect the shield).
3. **J6 / SSIO IP4** and **lamp/coin-meter outputs** — ✅ resolved by the
   chain architecture in `shield_j10_pinout.md`: IP4/J6 is '165 device U5
   (8 bits, zero extra pins) and outputs are a 74HC595+ULN2803 chain,
   extensible per game with no pin cost. J6's *cabinet-side* connector
   wiring still wants a manual cross-check before the harness is crimped.
4. **Board outline/mounting** — `pcb_design.md` + `tools/generate_pcb.py`
   own the physical layout; sync them to §4b (they currently assume generic
   2×20 headers, and J9 must be left clear for the SDRAM module).
5. **138K variant** — same dock; header nets are dock-level, but the
   net→ball map on sheets 4–6 is SOM-specific. Re-extract from the 138K
   SOM schematic before targeting it.

---

## 7. Configuration & game selection (DIP switches)

Two 8-position DIP banks, matching the SW1/SW2 placement already in
`pcb_design.md`. **Revised 2026-07-20:** game *selection* moves to the OSD
(see 7c/7d); the physical DIPs are for what operators have always used DIPs
for — the game's own option switches.

### 7a. Switch map

| Bank | Positions | Function |
|---|---|---|
| SW1 | 1–8 | **GAME DIPS — wired verbatim as the core's IP3 byte** (the original board's B3 bank). Meanings are per game, exactly as the 1982 operator manuals document them: coinage, music, difficulty, cabinet type, coin meters… Ship a printed reference card per game, as operators always had. |
| SW2 | 1 | Menu enable (see 7c) |
| SW2 | 2 | Video: 15 kHz cabinet CRT / 31 kHz |
| SW2 | 3 | 15 kHz sync format: separate H/V (default, = MCR cabinet) / composite |
| SW2 | 4 | Free play (where the game's own DIPs lack it) |
| SW2 | 5 | Service / test |
| SW2 | 6–8 | Reserved |

SW1 = IP3 removes the per-game hardcoded `input_3` constants from the top —
the operator sets the real switches. Two caveats survive from the analysis
below: the cocktail bit lives at a different IP3 position per game (that is
now simply the operator's problem to set per the game's card, as it was in
1982), and **IP3 is not purely DIPs for every game** — Tron's bit 7 is the
cocktail player's fire button. The original hardware wired that harness
line in parallel with DIP position 8 on the same active-low input, and the
manual said "leave SW1-8 OFF". We replicate it exactly: the FPGA ORs the
switch bit with the harness line, no per-game masking — same behaviour,
same operator convention, including the same failure mode if the switch is
left on.

**Cocktail pin impact:** unchanged — cocktail P2 controls for Tron/Domino
arrive on SSIO IP2 = J5 1-8, already allocated in §4b. The outstanding item
is **IP4 / J6**, which §4b does not pin: it carries Wacko's cocktail
joystick, Two Tigers' P2 dial, and Kroozr's analogue-stick Y axis (the last
needed even upright). Allocate from the 8 reserved pins once J6's cabinet
wiring is established.

### 7b. Reading them (74AHC165)

The two DIP banks are simply devices **U6 (SW1) and U7 (SW2) on the
unified input chain** defined in `shield_j10_pinout.md` §3 (IN_CLK /
IN_LOAD_N / IN_DATA on J10 pins 25/26/27) — the same chain that carries
every harness input, so the DIPs cost zero additional pins. Switch to GND
with pull-ups to +3V3; a closed switch reads 0. Because the chain is
scanned continuously, DIP changes could be live — but the cores latch IP3
meaningfully only at boot, so keep the **silkscreen "power-cycle after
changing DIPs"** next to the banks.

### 7c. OSD (game selection & system settings)

Game selection is on-screen, opened with the **cabinet's existing service
button** (present in every MCR harness) or the bench board key. Selection
and system prefs persist to a reserved SD sector; the chosen game reloads
via the existing rom_loader path, no reflash.

**The OSD must be visible on BOTH video outputs.** It composites into the
core's native RGB stream *before* the analog/HDMI split (clk_sys domain, on
the native raster), so the cabinet CRT — the only display in a cabinet —
shows it identically to HDMI. Consequences the implementation must honour:
- **per-game rotation**: vertical games (Tron, Satan's Hollow, Kick…) run
  on physically rotated monitors, so OSD text must render ROT90 for them;
- works on the **15 kHz raster** (240-line fields), not just 31 kHz;
- native resolution and the game palette's 3:3:3 colour — which is
  authentic-looking, not a limitation.

Menu semantics:
- **Menu off (SW2-1, cabinet default):** customers cannot reach the OSD;
  the service button still opens it (operator path, as MCR test switches
  always worked).
- **Menu on:** OSD reachable from the pad (bench/home use).

### 7d. Multiboot layout

Per-core bitstream payload is **2.5 MB** (`impl/pnr/*.bin`; the 20 MB `.fs`
is ASCII, not the flash footprint), so all three family cores fit in <8 MB.
A small selector image boots first, reads the prefs sector from SD (last
selected family/game), and reconfigures to that image's flash address.
`-multi_boot 1` is already set in `build.tcl`. No switches involved.

### 7e. Fallback behaviour (required for shipping)

If the selected family/game has no ROMs available (missing SD card, missing
file, bad checksum): **do not sit on a black screen.** Flash a status code
on an LED and fall back to the menu (or to a built-in test pattern when the
menu is disabled), so a field failure is diagnosable without a laptop.

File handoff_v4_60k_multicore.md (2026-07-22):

# MCR Port V4 Handoff — Tang Console 60K multi-core arcade platform

**Most current handoff.** Supersedes `handoff_v3_video_and_domino.md` (the
Tang Primer 25K HDMI bring-up + Domino POC — now historical; every "path
forward" it listed is done). This describes the 60K as it stands: a
multi-game MCR arcade platform with a clear runway to the whole MCR family.

Detail lives in the docs this file points at; this is the map.

---

## 1. What works today (Tang Console 60K)

- **Six MCR-2 games in one bitstream** — Domino Man, Tron, Satan's Hollow,
  Wacko, Kozmik Kroozr, Two Tigers — selected at runtime from an on-screen
  menu. Verified on hardware: HDMI, analog video, USB pad, SD game
  switching, and boot-into-last-game all work.
- **720p HDMI with audio** from a DDR3-backed framebuffer (nand2mario/
  gbatang), fully decoupled from core timing (no shimmer, no genlock).
- **Analog RGB** on the J10 header at native 31 kHz and 15 kHz (real
  cabinet timing), strap-selectable sync format.
- **USB HID gamepad** on USB-A port 1, with a cold-boot recovery fix so it
  enumerates from a flash boot (not just a JTAG load).
- **SD ROM loader + preferences**: games load from a raw-sector pack on a
  microSD card; the selected game persists to a reserved sector, so a
  cabinet boots straight back into the owner's last choice.
- **On-screen menu (`src/rtl/osd.sv`)** composited in the core raster
  domain, so it shows identically on HDMI and analog, rotated for the
  vertical games. Parameterized per family (game count, names, rotation).

Everything here is on `main`. Prebuilt flashable images are in
`bitstreams/` (`console60k_<game>.fs`).

## 2. How to drive it

Full build / flash / SD-card / play instructions are in **`README.md`**
(§1–5). The short version:

```sh
python3 tools/merge_roms.py tron            # generate ROM hex for a game
cd mcr2_console60k && gw_sh build.tcl        # headless build (see CLAUDE.md)
openFPGALoader -b tangconsole -f bitstreams/console60k_tron.fs   # flash to boot
python3 tools/make_rompack.py                # build the SD pack (all MCR-2 games)
sudo python3 tools/write_rompack.py diskN    # write it to a card (guarded)
```

On the pad: **Select+Start opens the game menu**; Up/Down move, A loads, B
exits. Bench wiring (analog video, straps, LEDs, beacon) is in
**`docs/bench_wiring.md`**.

## 3. Architecture notes (the load-bearing decisions)

These are the things that cost real debugging; the full "do not regress"
list is in **`CLAUDE.md`**. Highlights:

- **PLL VCO must stay 700–1400 MHz** — the original rolling-screen bug.
- **HDMI is one clock chain** (27 MHz → PLL → 371.25 → CLKDIV÷5 → 74.25),
  NESTang-style; gbatang's cross-PLL serializer clocking produced
  synced-but-dead TMDS here.
- **Declare-before-use, always** — Gowin turns use-before-declaration into
  a silent 1-bit wire (post-build check greps for "Undeclared symbol").
- **IDE Place Option must be 2** or DDR3 never trains → black HDMI.
- The video pipeline splits *after* the OSD composite, so the menu (and any
  future overlay) is on every output for free.

## 4. The MCR family runway

The plan and per-phase design live in **`docs/mcr_core_roadmap.md`**,
grounded in the five MiSTer MCR cores vendored under `refs/` (gitignored).
Status at this handoff:

| Family | Games | Status |
|---|---|---|
| **MCR-2** | the six above | **Shipping on hardware** |
| **MCR-1** | Kick, Kickman, Solar Fox | **Builds** (`mcr1_console60k/`, `console60k_mcr1_*.fs`); no new HW; not yet hardware-tested |
| **SDRAM foundation** | — | **Memtest built** (`console60k_sdram_memtest.fs`); verifies the J9 module before any core rides it. Gate for all MCR-3 |
| **MCR-3** | Tapper, Timber, Journey, DoT | **Core vendored + adapted** (`src/rtl/mcr3.vhd`); board integration fully designed, gated on the SDRAM memtest passing |
| **MCR3Scroll** | Spy Hunter, Crater, Turbo Tag | **Core vendored + adapted** (`src/rtl/mcr3scroll.vhd`); FX68K sound stack verified portable; board gated on SDRAM |
| **MCR3Mono** | Rampage, Sarge, Max RPM, … | **Core vendored + adapted** (`src/rtl/mcr3mono.vhd`); TCS (6809) + Sounds Good (FX68K) verified portable; board gated on SDRAM |

Key realities the roadmap captures:
- MCR-1 needs **no new hardware** (small ROMs, all BRAM) — the cheap win.
- Every MCR-3 family needs the **Tang SDRAM module in J9** for the 128 KB
  real-time sprite ROM (won't fit BRAM). That's why the SDRAM memtest
  comes first — verify the memory in isolation, then build cores on it.
- **Journey's tape samples go in DDR3** (the framebuffer's), not the sprite
  SDRAM. **Discs of Tron** ships without speech (Squawk & Talk was never
  implemented upstream).

## 5. Hardware verification status (what's proven vs pending)

| Item | Status |
|---|---|
| 60K HDMI 720p + audio | ✅ on hardware |
| Analog 31/15 kHz | ✅ on hardware |
| USB pad + cold-boot fix | ✅ on hardware |
| SD loader + boot-into-last-game | ✅ on hardware |
| OSD menu (all 6 MCR-2 games) | ✅ on hardware |
| MCR-1 (Kick/Solar Fox) | ⏳ builds, flash + play pending |
| SDRAM module (J9) | ⏳ memtest built, module in hand, test scheduled |
| MCR-3 board | ⛔ blocked on the SDRAM memtest |

Per-game control caveats (derived, not yet play-tuned): Kick spinner
sensitivity; Tron aim direction (MAME PORT_REVERSE); Kroozr/Wacko/Two
Tigers analogue feel; the cap_delay left-edge value. All in `TODO.md`.

## 6. Shield / cabinet integration

The PCB is being built. The authoritative sheet is
**`docs/shield_j10_pinout.md`** — one 40-pin J10 header carries video,
audio and *all* controls: cabinet inputs and both DIP banks ride a
7×74HC165 chain (3 pins), outputs a 74HC595+ULN2803 chain (4 pins). The
input stage is **74AHC165 at 3.3 V taking the 5 V harness directly** (no
level-shifter ICs, no optos — the buck is non-isolated, so the optos never
bought isolation anyway). Electrical spec and per-game harness maps:
`docs/universal_mcr_shield_spec.md`, `docs/mcr_game_input_matrix.md`.

The shield's "live" pins are exactly what today's bitstreams drive, so the
board does video/audio the day it's soldered; the control-chain pins are
reserved and wait on the expander RTL (a small, planned module — `TODO.md`).

**Interface style (settled 2026-07-22): the cabinet harness plugs into the
shield** — the shield presents the original MCR connectors, the operator
plugs the existing harness in and picks the game in the OSD, and the FPGA
maps every pin per game (no rewiring). Not a mechanical board-swap. Rev A
targets the SSIO-family connectors (most games); MCR3Mono is a later
variant (spec §0).

## 7. Immediate next steps

1. **Flash the SDRAM memtest** with the module in J9; watch the J10 LEDs
   (PASS/DONE/FAIL/heartbeat). DONE+PASS unblocks all of MCR-3. If reads
   fail, swap the ODDR D0/D1 phase in `src/rtl/sdram_gw.sv` and rebuild.
2. **Then build the MCR-3 board** (Tapper first) per the settled design in
   the roadmap — vendored core + proven memory make it mechanical.
3. **Play-test MCR-1** (flash `console60k_mcr1_kick.fs`) whenever
   convenient; it needs no SDRAM.
4. Continue the family: MCR3Scroll and MCR3Mono (they add FX68K / 6809
   sound boards on top of the same SDRAM foundation).

## 8. Doc map

- `README.md` — build / flash / SD / play, front to back.
- `CLAUDE.md` — build gotchas + the "do not regress" constraints.
- `TODO.md` — every open item, consolidated.
- `docs/mcr_core_roadmap.md` — the MCR family porting plan (Phases A–E).
- `docs/shield_j10_pinout.md` — the frozen 40-pin shield header.
- `docs/shield_wiring.md` — MCR connector footprints + chip wiring + ADC.
- `docs/universal_mcr_shield_spec.md` — shield electrical spec.
- `docs/mcr_game_input_matrix.md` — per-game harness + SSIO bit maps.
- `docs/bench_wiring.md` — what the current bitstream drives on J10.
- `handoff_v3_video_and_domino.md` — the 25K HDMI/Domino bring-up (historical).
- `handoff_v2_design.md` — original SDRAM/V2 plan + shield electrical spec.

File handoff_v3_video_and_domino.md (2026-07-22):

# MCR Port V3 Handoff — HDMI Video Bring-up & Domino Man POC

> **Historical.** This documents the Tang Primer 25K HDMI bring-up and the
> Domino Man proof-of-concept. Every "path forward" it lists (SDRAM
> framebuffer, USB, bigger boards) is now done on the 60K. For the current
> state see **`handoff_v4_60k_multicore.md`**.

Status as of this session. Covers the working Tang Primer 25K build, the video
pipeline and its known limits, the Domino Man proof-of-concept (background tiles
enabled), the MCR ROM-fit analysis, and the recommended paths forward.

---

## 1. Current state (Tang Primer 25K)

- **Domino Man (MCR2) runs with full background + sprites over HDMI.** Renders
  correctly; boots to attract mode. Fits **56/56 BSRAM**, timing met
  (setup +0.48 ns, hold +0.27 ns).
- Bitstream: `mcr2_primer25k/impl/pnr/mcr2_primer25k.fs`.
- Two video outputs are generated simultaneously: **HDMI** (TMDS) and the core's
  native **analog RGBS** (`cab_*` pins, currently unused but wired).
- Known residual: slight **shimmer** on HDMI (see §4). Left-edge overlap is fixed.

### The original problem (solved)
The screen was "rolling." Root cause was **not** the video logic — it was a
broken PLL: the GW5A VCO was set to 1500 MHz, outside the valid 700–1400 MHz
window, so every derived clock was wrong (core ran at ~75 MHz and failed timing;
refresh was a non-standard ~60.6 Hz). Fixing the PLL fixed the rolling.

---

## 2. Clock configuration (the critical fix)

`src/rtl/gowin_pll_mcr2.v` — VCO **must** stay in 700–1400 MHz.

| Param | Value | Result |
|---|---|---|
| FCLKIN | 50 MHz | input |
| IDIV_SEL / FBDIV_SEL | 1 / 1 | — |
| MDIV_SEL | **20** | VCO = 50·1·20/1 = **1000 MHz** (valid) |
| ODIV0_SEL | **8** | `clk_p5` = 1000/8 = **125 MHz** |
| ODIV1_SEL | **25** | `clk_sys` = 1000/25 = **40 MHz** (core) |

`clk_pixel` = `clk_p5` / 5 = **25 MHz** via `CLKDIV DIV_MODE="5"`.
`clk_p5` (125 MHz) is the 5× TMDS bit clock feeding the OSER10 serializers.

**SDC (`mcr2_primer25k/src/mcr2_primer25k.sdc`):** the CLKDIV output and the core
clock must be declared explicitly (the tool's auto "default_gen_clk" names are
not queryable at parse time), and the core↔pixel line-buffer crossing is marked
asynchronous — otherwise you get false setup violations. Do not remove these.

---

## 3. HDMI video pipeline (`mcr2_primer25k_top.sv`)

The MCR core (31 kHz mode, `tv15Khz_mode=0`) natively emits **634×525 @ 20 MHz,
512×480 active, negative H/V sync, 31.5 kHz / 60.09 Hz**. We conform that to a
standard **640×480@~60 (VGA/DMT)** HDMI mode and center the game:

- **Sync generator:** 640 active + 16 FP + 96 sync + 41 BP = **793 H total**
  (see below), 525 V total, negative H/V sync, DE gated.
- **Centering:** 512-wide game in 640 active → 64 px left margin (margins black).
- **Clock-domain crossing:** a **2-line ping-pong buffer** (`line_buffer`,
  1024×9, 1 BSRAM block). Core writes at `clk_sys`; HDMI reads at `clk_pixel`.
  Read selects the buffer not currently being written (`read_buffer_idx`).

Three tuning fixes are layered on top, each addressing a specific artifact:

1. **`H_TOTAL = 793`** (not the standard 800). The core emits one line per
   634 core-pixels @ 20 MHz; 634·(25/20) = 792.5, so 793 output pixels @ 25 MHz
   makes the output line rate track the core to within 0.06% (vs 0.94% at 800).
   This nearly stops mid-line buffer switches → **big reduction in shimmer/tear.**
2. **Vertical genlock.** The output vertical counter restarts at each core frame
   (falling edge of core `vblank`), so the ~0.5 Hz frame-rate mismatch can't
   accumulate into a slow vertical roll. H is never disturbed (HSync stays clean).
   Bypassed in test-pattern mode (S2).
3. **`CAP_DELAY = 13`** — the core's RGB output lags its `hcnt` by a fixed
   pipeline delay (tile fetch → gfx ROM → palette → output regs). Indexing the
   buffer by raw `hcnt` captured the *previous* line's tail into the first ~13
   entries → a garbled strip on the left edge. The write index is shifted back by
   `CAP_DELAY` and capture runs a few pixels into hblank to keep the drained
   pixels. **Tunable:** sliver on the left → increase; sliver on the right →
   decrease.

**Diagnostics:** S2 button (pin H10) toggles a free-running 640×480 color-bar
test pattern (standalone, not genlocked) — good for confirming the monitor locks
independent of the core.

---

## 4. Known limitation: residual HDMI shimmer

The 2-line ping-pong buffer bridges two clocks that are *close* but not locked.
The three fixes above make it good, not perfect — expect a faint seam to drift
through roughly once per frame on detailed content.

**This cannot be fully fixed on the 25K over HDMI.** The clean solutions are:
- **Don't buffer at all** → analog VGA out (see §6, recommended easy win), or
- **Full-frame buffer** (the NESTang approach) → needs memory the 25K lacks.

For reference, NESTang's `nes2hdmi.sv` keeps the entire NES frame (256×240×6bit
≈ 46 KB) in dual-port BRAM and scans HDMI out of the *completed* frame — zero
tearing. Our MCR2 frame (512×480) is ~180 KB as palette-index / ~270 KB as RGB;
the GW5A-25 has ~126 KB BRAM total and we're at 56/56, so a full-frame buffer
does not fit here. It fits trivially on the 60K/138K.

---

## 5. Domino Man POC — how it was done

Domino Man was chosen because its **32 KB CPU ROM** (vs Satan's Hollow's 48 KB)
frees exactly the 8 BSRAM blocks the background tile ROMs need.

| ROM | Size | BSRAM blocks |
|---|---|---|
| CPU | 32 KB | 16 |
| Sound | 16 KB | 8 |
| BG plane 1 (gfx1_1) | 8 KB | 4 |
| BG plane 2 (gfx1_2) | 8 KB | 4 |
| Sprites (gfx2) | 32 KB | 16 |
| + core RAMs / line buffer | — | ~8 |
| **Total** | | **56 / 56** |

Changes made:
1. **`tools/merge_roms.py`** — refactored to a shared `build()` with a game
   selector. Run `python3 tools/merge_roms.py domino` (default) or `... shollow`
   from the **repo root**. Writes `rom_*.hex` into both `mcr2_primer25k/src/` and
   `src/rtl/`.
2. **`src/rtl/mcr2.vhd`** (~line 766) — re-enabled the two `bg_graphics` tile
   ROMs (8 KB each, addressed by `bg_code_line`, `INIT_FILE` = `rom_gfx1_1.hex` /
   `rom_gfx1_2.hex`), mirroring the existing `sprite_graphics` instantiation.
   Note: the `dpram` in ROM mode only reads on port A; the download port is inert
   (the Primer build loads via `INIT_FILE`, not the `dl_*` download bus).

**Not yet done for Domino Man:** input map still reflects Satan's Hollow
(`mcr2_primer25k_top.sv`, `input_0`/`input_1`). Boots to attract and shows
graphics, but in-game controls/DIPs need remapping for correct play.

---

## 6. Recommended paths forward

### A. VGA PMOD (analog) — cleanest image on the 25K, least effort
The core's native video is already wired to analog RGBS (`cab_r/g/b`, `cab_hs`,
`cab_vs`, `cab_csync`) in the CST. A VGA PMOD (resistor-DAC on RGB + HS/VS) driven
from these pins outputs the core's **native timing directly** — no buffer, no
clock crossing → **no shimmer/tearing/seam.** Analog monitors lock to whatever
H/V you send, so they're far more forgiving than HDMI.
- **31 kHz** (current `tv15Khz_mode=0`): works on a standard VGA monitor.
- **15 kHz** (`tv15Khz_mode=1`): authentic arcade signal — needs an arcade/
  multisync CRT or a scan converter (OSSC/RetroTink); a normal VGA LCD won't sync.
- Uses only ~11–14 pins (one PMOD header), leaving the other header for controls.
- **TODO when the PMOD arrives:** remap `cab_*` in the CST to the PMOD's pinout;
  optionally add an S-button toggle for 15/31 kHz.

### B. USB game controller
FPGA has no built-in USB host. Easiest route: soft **USB-HID host core**
(nand2mario `usb_hid_host`, built for Tang) on two GPIO wired to the USB D+/D−,
decoding a **DInput/standard-HID** pad (avoid XInput/Xbox) into `input_0/1`.
Prerequisite: confirm the USB-A data lines land on **FPGA pins** (not the debug
MCU). The **Tang Console 60K** is believed to have this wired already; confirm
D+/D− routing from the schematic. Minimal added hardware on the 25K: USB-A
breakout + 2×15 kΩ pull-downs + 5 V to VBUS.

### C. SDRAM framebuffer — the "do it right" HDMI path
The received SDRAM board enables a NESTang-style full-frame buffer (clean HDMI)
and can also hold ROMs (freeing BRAM). **Caveat (confirmed concern):** SDRAM eats
~30–40 pins, squeezing control inputs on the 25K's ~60 usable GPIO. Best deferred
to the **60K/138K**, where SDRAM/DDR is onboard on **dedicated pins** (costs zero
GPIO). See `handoff_v2_design.md` for the SDRAM controller + boot-loader plan.

### D. Bigger boards (60K/138K) — the target build
Far more BRAM + onboard DDR. Do it the NESTang way: full 512×480 frame buffer →
720p output (no shimmer/tear/seam), USB controllers, all games fit (including the
big MCR3 titles). The console ports exist (`mcr2_console60k`, `mcr2_console138k`)
but currently only replicate the primer's pin set (no USB/SDRAM wired yet).

---

## 7. MCR ROM-fit analysis (25K, ~48 blocks for ROM after RAM overhead)

| Game | Family | Total ROM | Fit w/ background? | Core work |
|---|---|---:|:--:|---|
| Kick | MCR1 | 80 KB | ✅ (headroom) | new core (shares video + SSIO) |
| Solar Fox | MCR1 | 80 KB | ✅ (headroom) | new core (shares video + SSIO) |
| **Domino Man** | MCR2 | 96 KB | ✅ (exact 56/56) | **none — running now** |
| Satan's Hollow | MCR2 | 108 KB | ❌ (bg cut) | none |
| Tron | MCR2 | 108 KB | ❌ | none |
| Discs of Tron | MCR3 | 152 KB | ❌ | new core |
| Crater Raider | MCR2 | 220 KB | ❌❌ | none |
| Tapper | MCR3 | 232 KB | ❌❌ (128 KB sprites) | new core |
| Demolition Derby | MCR3 | 224 KB | ❌❌ | new core + dual-CPU |
| Rampage | MCR3 | 480 KB | ❌❌❌ | new core |

Takeaways: **MCR1 (Kick/Solar Fox) is the smallest family** and the natural next
small port. **MCR3 is the wrong direction** for the 25K (bigger, some dual-CPU) —
save for the big boards.

---

## 8. Build & flash

Headless build on macOS (GowinIDE bundles Tcl; the CLI needs the dylib +
framework paths set, and `$ORIGIN` doesn't resolve on macOS):

```sh
GWLIB=/Applications/GowinIDE.app/Contents/Resources/Gowin_EDA/IDE/lib
GW=/Applications/GowinIDE.app/Contents/Resources/Gowin_EDA/IDE/bin/gw_sh
cd mcr2_primer25k
DYLD_LIBRARY_PATH="$GWLIB" DYLD_FRAMEWORK_PATH="$GWLIB" "$GW" build.tcl
```

To switch games: `python3 tools/merge_roms.py <domino|shollow>` from the repo
root, then rebuild. Bitstream lands at `mcr2_primer25k/impl/pnr/mcr2_primer25k.fs`.

Sanity checks after a build:
- No `PA1019` (VCO range) warning in the log.
- `BSRAM ... | 56/56` in `impl/pnr/mcr2_primer25k.rpt.txt` (must not exceed 56).
- Positive SETUP/HOLD slack in `impl/pnr/mcr2_primer25k.timing_paths`.

---

## 9. Key files & tuning knobs

| File | Purpose |
|---|---|
| `mcr2_primer25k/src/mcr2_primer25k_top.sv` | top: clocks, line-buffer scaler, sync gen, inputs |
| `src/rtl/gowin_pll_mcr2.v` | PLL (VCO/dividers) |
| `src/rtl/mcr2.vhd` | MCR2 core (bg ROMs re-enabled ~L766) |
| `mcr2_primer25k/src/mcr2_primer25k.sdc` | generated-clock + async-group constraints |
| `mcr2_primer25k/src/mcr2_primer25k.cst` | pin map (incl. unused `cab_*` analog RGBS) |
| `tools/merge_roms.py` | build `rom_*.hex` per game |
| `mcr2_primer25k/build.tcl` | Gowin build script |

**Tuning knobs in `mcr2_primer25k_top.sv`:**
- `H_TOTAL` (793) — output line rate vs core line rate (shimmer).
- `CAP_DELAY` (13) — left/right-edge pixel alignment.
- Genlock uses core `vblank`; test pattern on S2 (`reset2`).

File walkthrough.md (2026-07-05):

# Walkthrough of Bally Midway MCR2 Multi-Board FPGA Port

This port converts the Cyclone V (MiSTer) Bally Midway MCR2 arcade core into a standalone, hardcoded core running on Gowin Aurora GW5A FPGAs. We support the **Tang Primer 25K**, **Tang Console 60K**, and **Tang Console 138K** boards concurrently.

---

## 1. Accomplished Work

*   **Repository Reorganization:** Restructured the repository by extracting all platform-independent assets to a global `src/` directory. All boards now share the exact same VHDL/SystemVerilog core files, audio generators, HDMI serializers, and ROM hex tables, preventing any code duplication.
*   **Tang Console 60K & 138K Ports:** Created dedicated board directories (`mcr2_console60k/` and `mcr2_console138k/`) with compile-ready project configurations, pin constraint files, timing constraint files, and top-level SV wrappers.
*   **On-Chip BRAM Optimization (60K/138K):** Configured both the 60K and 138K cores to run in **100% On-Chip BRAM mode**. Since the 60K chip has 320KB of internal block RAM and the 138K has 765KB, the entire core (119.5KB of CPU/sound/graphics ROMs + working memory) fits completely on-chip with zero latency, zero wait states, and no external memory controllers needed.

---

## 2. Directory Structure

The repository is structured as a shared codebase with independent board projects:

*   **`src/` (Shared platform-independent code):**
    *   `src/rtl/`: Core VHDL/SystemVerilog files (`mcr2.vhd`, Z80 CPUs, timers, RAM wrappers).
    *   `src/audio/`: Shared Delta-Sigma audio DAC.
    *   `src/dvi_tx/`: Shared HDMI serialization logic.
    *   `src/roms/`: Initialized Satan's Hollow ROM hex tables.
*   **`mcr2_primer25k/`:** Gowin project and constraints for the Tang Primer 25K.
*   **`mcr2_console60k/`:** Gowin project and constraints for the Tang Console 60K.
*   **`mcr2_console138k/`:** Gowin project and constraints for the Tang Console 138K.

---

## 3. How to Compile the Ports

1.  Open the **Gowin IDE** (Yunyuan) on your PC.
2.  Choose **Open Project** and navigate to your target board's project file:
    *   For Tang Primer 25K: [mcr2_primer25k.gprj](file:///Users/alans/Documents/development/Arcade-MCR2-Primer25K/mcr2_primer25k/mcr2_primer25k.gprj)
    *   For Tang Console 60K: [mcr2_console60k.gprj](file:///Users/alans/Documents/development/Arcade-MCR2-Primer25K/mcr2_console60k/mcr2_console60k.gprj)
    *   For Tang Console 138K: [mcr2_console138k.gprj](file:///Users/alans/Documents/development/Arcade-MCR2-Primer25K/mcr2_console138k/mcr2_console138k.gprj)
3.  Click **Process** $\rightarrow$ **Run All** in the IDE to run synthesis, placement, and routing.
4.  The generated `.fs` bitstream file will be created in the `impl/` directory of the selected project folder. Write this to your FPGA using the **Gowin Programmer**.

*Note: The constraint files (`.cst`) for the Console 60K/138K ports map clocks and HDMI signals to standard pins, and leave cabinet controls/video signals as placeholder headers. Edit the `.cst` files to match your custom Shield PCB layout when finalized.*

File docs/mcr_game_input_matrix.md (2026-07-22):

# MCR Game Input Matrix (machine-readable)

Transcribed from `docs/MCR_Master_Pinouts.pdf` ("Ultimate MCR Master Pinout
Matrix"). This is the source of truth for **what each cabinet input does per
game** (the function map). Only the in-game meaning changes across MCR-1/2/3;
all game-specific mapping is done in the FPGA top, never on the shield PCB.

> **For the PHYSICAL connectors** — real board numbering, pin counts, and
> pitch (only J1 power is .156"; J2 video / J3 audio / J4–J6 inputs are
> .100" MTA) — use **`docs/MCR Series Pinouts.html`** and
> **`docs/shield_wiring.md`**. The `J2/J3/J4/J5` labels in the tables below
> are the PDF's **normalized cabinet-function** scheme, which is NOT the
> physical connector numbering (see the "Connector-numbering caution" near
> the end). E.g. the PDF's "J2 = P1 controls / J3 = coins" are physically on
> the SSIO board's **J4** (IP0+IP1).

Legend: `-` = N/C for that game. "No J5" (MCR-1 and most MCR-2 cabinets have
no J5 harness) is also shown as `-`.

Games: SF=Solar Fox (MCR-1), KK=Kick/Kickman (MCR-1), TR=Tron (MCR-2),
SH=Satan's Hollow (MCR-2), KZ=Kozmik Krooz'r (MCR-2), WA=Wacko (MCR-2),
DM=Domino Man (MCR-2), TA=Tapper (MCR-3), JO=Journey (MCR-3), TI=Timber
(MCR-3), DT=Discs of Tron (MCR-3), SY=Spy Hunter (MCR-3), CR=Crater Raider
(MCR-3).

## J2 — Player 1 controls

| Pin | Std function | SF | KK | TR | SH | KZ | WA | DM | TA | JO | TI | DT | SY | CR |
|---|---|---|---|---|---|---|---|---|---|---|---|---|---|---|
| J2-1 | P1 Up | P1 Up | - | P1 Up | **P1 Left** | - | P1 Up | P1 Up | P1 Up | P1 Up | P1 Up | P1 Up | Machine Gun | - |
| J2-2 | P1 Down | P1 Down | - | P1 Down | **P1 Right** | - | P1 Down | P1 Down | P1 Down | P1 Down | P1 Down | P1 Down | Missiles | - |
| J2-3 | P1 Left | P1 Left | - | P1 Left | - | - | P1 Left | P1 Left | P1 Left | P1 Left | P1 Left | P1 Left | Oil Slick | P1 Left |
| J2-4 | P1 Right | P1 Right | - | P1 Right | - | - | P1 Right | P1 Right | P1 Right | P1 Right | P1 Right | P1 Right | Smoke Screen | P1 Right |
| J2-5 | P1 Button 1 | Fire/Turbo | Kick | Fire (Trigger) | Fire (Trigger) | Fire | - | Place/Strike | Pour/Serve | Fire | - | Fire (Trigger) | Weapons Van | Fire |
| J2-6 | P1 Button 2 | - | Catch | - | Shield | - | - | - | - | - | - | Deflect | - | Shield |
| J2-13 | Ground | GND | GND | GND | GND | GND | GND | GND | GND | GND | GND | GND | GND | GND |

## J3 — System & coins (identical across all games)

| Pin | Function | Notes |
|---|---|---|
| J3-1 | Coin 1 | all games |
| J3-2 | Coin 2 | all games |
| J3-3 | Start 1 | all games |
| J3-4 | Start 2 | all games except Spy Hunter (N/C — 1-player game) |
| J3-5 | Tilt | all games |

## J4 — Opt X / 8-bit parallel dial data

Wiring is identical for every game: J4-1..J4-7 = data bits 0–6, J4-8 = key,
J4-9 = data bit 7, J4-10 = ground. Per-game meaning of the 8-bit bus:

| Game | J4 bus meaning |
|---|---|
| Solar Fox, Satan's Hollow, Domino Man, Tapper, Journey, Timber, Crater Raider | Data Bit 0–7 (standard/unused bus) |
| Kick/Kickman | Spinner X (D0–D7) |
| Tron | Opt/Main spinner (D0–D7) |
| Kozmik Krooz'r | Spinner X (D0–D7) |
| Wacko | Trackball X-Axis (D0–D7) |
| Discs of Tron | Rotary aim (D0–D7) |
| Spy Hunter | Steering/Gas (D0–D7) |

## J5 — Opt Y / trackball / Player 2 controls

| Pin | Std function | WA | TA | TI | DT | others |
|---|---|---|---|---|---|---|
| J5-1..J5-6 | P2 Mux / Data Bit 0–5 (Opt Y) | Trackball Y (D0–D5) | - | - | - | - |
| J5-15 | P2 Up / Data Bit 6 | Trackball Y (D6) | P2 Up | P2 Up | Aim Up | - |
| J5-16 | P2 Down / Data Bit 7 | Trackball Y (D7) | P2 Down | P2 Down | Aim Down | - |
| J5-17 | P2 Left | - | P2 Left | P2 Left | - | - |
| J5-18 | P2 Right | - | P2 Right | P2 Right | - | - |
| J5-19 | P2 Button 1 | - | P2 Pour | - | - | - |

## Video connector (identical across all games)

| Pin | Function |
|---|---|
| Video-1 | Red |
| Video-2 | Video GND |
| Video-3 | Green |
| Video-4 | Video GND |
| Video-5 | Blue |
| Video-6 | Video GND |
| Video-7 | Key |
| Video-8 | H-Sync (−) |
| Video-9 | V-Sync (−) |

## From connector pins to SSIO input ports (FPGA-internal)

The connector matrix above is cabinet wiring. The mapping of those switches
into the SSIO's `input_0..input_4` byte ports is per-game and must be taken
from MAME (`src/mame/midway/mcr.cpp`, `INPUT_PORTS_START(<game>)`); the
matrix cannot tell you bit positions. Verified examples:

- **Domino Man** — IP0 = {test, service1, tilt, **Button1**, start2, start1,
  coin2, coin1}; IP1 = {4'unused, down, up, right, left} (4-way);
  IP3 DIP upright default = `0x3E` (0xFF selects cocktail!).
- **Satan's Hollow** — IP0 = {service, x, tilt, x, start2, start1, coin2,
  coin1}; IP1 = {P2 fire, P2 shield, P2 right, P2 left, fire, shield,
  right, left}.
- **Tron** — IP0 = standard {test, service1, tilt, TRIGGER, start2, start1,
  coin2, coin1}; IP1 = 8-bit absolute aim dial (PORT_REVERSE); IP2 = P1
  8-way joystick [3:0] (+P2 cocktail [7:4]); IP3 DIP upright default =
  `0x80` (bit7 is the cocktail trigger input, idle high); IP4 = cocktail
  dial.
- **Wacko** — IP1 = trackball X, IP2 = trackball Y (free-running counters);
  IP4 = 4-way aim joystick {bit3 up, bit2 down, bit1 left, bit0 right};
  IP0 standard but with no Button 1. The SSIO output port 4 bit 0 muxes
  IP1/IP2 to the *cocktail* player's trackball only, so upright play needs
  no mux support — which is why this runs without exposing SSIO outputs.
- **Kozmik Kroozr** — IP1 packs the cockpit spinner unusually: the SSIO
  custom read returns `((dial & 0x80) >> 1) | ((dial & 0x70) >> 4)`, i.e.
  **bit 6 = dial[7], bits 2:0 = dial[6:4], both ACTIVE HIGH**; bit 7 is
  Button 2 (active low) and bits 5:3 are cockpit sensors. IP2 = analogue
  stick X, IP4 = analogue stick Y, both `0x30..0x98` centred on `0x64`.
- **Two Tigers** — use the **Tron-conversion set (`twotigerc`)**: IP1 = P1
  dial, IP4 = P2 dial, IP2[3:0] = the four fire buttons, IP0 bit 4 =
  "Dogfight Start". The *dedicated* set (`twotiger`) also needs a video-RAM
  address remap at 0xE800 that this core does not implement.

### MCR-1 games (core src/rtl/mcr1.vhd, board mcr1_console60k)

Verified against the MiSTer Arcade-MCR1 top (which matches MAME mcr.cpp).
All inputs active low; input_3 = the game-option DIP byte.

- **Kick / Kickman** — IP0 = {service, x, x, **kick**(bit4), start2, start1,
  x, coin1}; IP1 = {4'unused, **spinner[3:0]**} (kicker angle, a 4-bit
  absolute value — driven from d-pad L/R through `spinner.sv`, low nibble).
  IP2/IP4 unused. Runs on a rotated monitor (ORIENTATION_SWAP_XY).
- **Solar Fox** — IP0 = {service, x, x, **fire_a**(bit4), **fire_b**(bit3),
  **fire_b**(bit2), x, coin1}; IP1 = {up,down,left,right, up,down,left,right}
  (the 4-way stick mirrored into both nibbles); IP2 = {7'x, **fire_a**(bit0)}.
  ROT90^FLIP_Y.

DIP note: input_3 is a 0xFF placeholder for both (all option switches off)
pending a MAME default cross-check on hardware.

Method for new games: `awk '/INPUT_PORTS_START\( <game> \)/,/INPUT_PORTS_END/'
mcr.cpp` and read the `PORT_BIT` masks. All inputs are active low.

## Where the DIP switches physically live (and connector-number decoding)

Verified against MAME 0.265 (`mcr.cpp` + `mcr3.cpp`): **every SSIO-based MCR
game — all of MCR-1, MCR-2, and MCR-3 — uses the identical input scheme.**
The DIPs never moved between hardware generations:

| SSIO port | Physical location (MAME/schematic comments) | Function |
|---|---|---|
| IP0 | SSIO connector **J4 pins 1–8** | coins, starts, button 1, tilt, service |
| IP1 | SSIO connector **J4 pins 10–13, 15–18** | dial/joystick/trackball-X (per game) |
| IP2 | SSIO connector **J5 pins 1–8** | joystick/trackball-Y/P2 (per game) |
| IP3 | **DIP bank at board location B3 — on the SSIO board, NOT a connector** | game options |
| IP4 | SSIO connector **J6 pins 1–8** | second dial / aux (per game) |

Answers to the obvious questions:

- **Did the DIPs move around per game/generation? No.** One bank, location
  B3 on the Super Sound I/O board, read as IP3, on every SSIO game from
  Kick (1981) through Discs of Tron (1983). Physically a 10-position bank;
  8 positions reach IP3 (Tron's manual: 9 unused, 10 = freeze).
- **Do the DIPs plug into a connector / get unplugged for a fire button or
  spinner? No.** The DIPs are switches mounted on the board; buttons and
  spinners arrive on the J4/J5/J6 harness connectors — electrically separate
  lines. Nothing is ever unplugged.
- **Then how does Tron put a cocktail fire button "in" IP3 bit 7?** The
  harness wire and DIP position 8 are two contacts on the *same* active-low
  input line, in parallel. The manual's convention: leave SW1-8 OFF
  (open) so the button can pull the line. Our shield replicates exactly
  this: the FPGA ORs the SW1 bit with the harness line — leave the switch
  off, the button works; leave it on, the input is held active, which is
  precisely what the original hardware would do too.
- **There is a SECOND DIP bank** most people never touch: 6 switches on the
  SSIO read by the *sound* Z80 at 0xF000 (MAME's `ssio:DIP` port). Every
  game we've extracted leaves it unused (0xFF); it is sound-board config,
  not game options. We model it as constant 0xFF.

**Connector-numbering caution — three schemes, don't mix them:**

1. **Normalized cabinet-function** (this file's top tables + the master
   PDF): J2 = P1 controls, J3 = coins, J4 = Opt X, J5 = Opt Y. A *logical*
   grouping, not physical connectors.
2. **Real SSIO/CPU board** (`MCR Series Pinouts.html`, and MAME's `ssio:IP*`
   comments): J1 = power (.156" MTA), J2 = video, J3 = audio, **J4 = IP0
   (pins 1-8) + IP1 (10-18)**, J5 = IP2, J6 = IP4 (all .100" MTA). **Use
   this for the shield's physical connectors and footprints.**
3. **Real MCR3Mono board** (MAME `mcr3.cpp`): IP0/IP1 = J2, IP2 = J3,
   IP4 = J4 — different again (mono is a later single board).

So e.g. the PDF's "J3 coin door" and "J2 P1 controls" are physically on the
SSIO board's **J4** (IP0+IP1). Treat the PDF's function names as truth and
its J-labels as logical only; for hardware, use scheme 2 (SSIO) — that is
what `docs/shield_wiring.md` builds the connector footprints from.

## Known gaps (not covered by the matrix PDF)

- **J6** — MAME lists `ssio:IP4` as "J6 1-8" (auxiliary inputs); the matrix
  has no J6 sheet. Unused by the games above.
- **Outputs** — coin meters / lamps driven by SSIO output ports are not in
  the matrix; original cabinets wire them via J3-area harness. Deferred.

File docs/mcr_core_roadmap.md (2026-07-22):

# MCR family porting plan (Tang Console 60K)

Rewritten 2026-07 after vendoring the five MiSTer MCR cores into `refs/`
(local reference checkouts, gitignored — nested git repos). This replaces
the earlier speculative roadmap: everything below is verified against the
actual sources.

## What the survey established

All five cores are the same dar/sorgelig lineage as our `mcr2.vhd` — one
core `.vhd` each, identical support files (T80, Z80CTC, `dpram`,
`gen_ram`, `cmos_ram`, `spinner.sv`), the **same `clock_40` input, the
same external CPU/sound ROM ports, and the same `dl_` download bus** our
SD loader already drives. The 60K platform (framebuffer/HDMI, analog
video, OSD, SD loader+prefs, USB, beacon, shield header) carries over
unchanged for every family.

| refs/ core | Games (from the MRAs) | Sound | ROM home on MiSTer |
|---|---|---|---|
| Arcade-MCR1 | Kick, Solar Fox | SSIO (same `mcr_sound_board.vhd` we ship) | **all BRAM** — no sdram.sv in the repo |
| Arcade-MCR3 | Tapper, Timber, Journey, Discs of Tron | SSIO + `wave_sound.sv` sample player (Journey tape music; **DoT speech absent upstream** — Squawk & Talk was never implemented) | CPU+sound+sprites in SDRAM, bg (32 KB) via `dl_` into BRAM |
| Arcade-MCR3Scroll | Spy Hunter, Crater Raider, Turbo Tag | SSIO + Cheap Squeak Deluxe (`cheap_squeak_deluxe.vhd`, FX68K) | SDRAM |
| Arcade-MCR3Mono | Rampage, Sarge, Max RPM, Power Drive, Star Guards, Demolition Derby (mono) | Turbo Cheap Squeak (`cpu09l` 6809) / Sounds Good (FX68K) — no SSIO | SDRAM |

Memory reality on the 60K (118 BSRAM blocks, ~78 free ≈ 156 KB for game
ROM after platform + core RAM):

- **MCR-1 fits BRAM trivially** (Kick ≈ 50 KB, Solar Fox ≈ 80 KB;
  `cpu_rom_addr` is only 15 bits). No new memory hardware.
- **Every MCR-3 family needs the SDRAM module** — sprite ROM alone is
  128 KB (Tapper) to 256 KB (Rampage); MiSTer's own `sdram.sv` multi-port
  arcade controller is in each refs/ repo, purpose-built for these cores.

## Phase A — MCR-1 core: Kick, Kickman, Solar Fox   [IN PROGRESS]

**Status 2026-07: the core builds.** `src/rtl/mcr1.vhd` vendored + patched
(hcnt_out/vcnt_out exposed; three gfx dprams given INIT_FILE and explicit
we_a/we_b tie-offs, since our SV dpram has no VHDL port defaults). New
`mcr1_console60k/` board project (MCR-2 top with the core swapped: 15-bit
CPU ROM + MCR-1 download map, 4-bit RGB truncated to the shared 3:3:3
pipeline, per-game input mux). merge_roms grew `family`-aware output and
kick/kickman/solarfox specs; osd.sv parameterized for the 2-game roster.
Kick: BSRAM 77/118, setup +0.585 ns. Bitstreams in `bitstreams/`
(console60k_mcr1_kick.fs, console60k_mcr1_solarfox.fs). **Not yet flashed
/ hardware-verified**; SD pack switching waits on pack-v2 (below), so for
now each MCR-1 game is a baked bitstream.

Remaining before Phase A is closed:
- Flash + verify Kick and Solar Fox on hardware (video, sound, controls).
  Kick's spinner sensitivity and both games' DIP default (input_3 = 0xFF
  placeholder) will likely need tuning; OSD text rotation direction on the
  rotated MCR-1 monitors is a guess.
- Pack format v2 so MCR-1 games load from SD like MCR-2 (see below).

Original work items (mostly done):

1. **Diff the shared support files first** (`refs/Arcade-MCR1_MiSTer/rtl/`
   vs our `src/rtl/`): ours carry local fixes (dpram INIT_FILE ROM mode,
   mcr2 bg download decode). Take `mcr1.vhd`; keep ours for everything
   shared.
2. Vendor `mcr1.vhd` → `src/rtl/`. Its download map differs from MCR-2
   (verified): sprites `0x10000-0x17FFF`, bg1 `0x18000-0x18FFF`, bg2
   `0x19000-0x19FFF`; CPU ROM is 32 KB max, sound 16 KB.
3. `merge_roms.py`: add `kick`, `kickman`, `solarfox` specs (zips already
   in `roms/`), writing the MCR-1 layout; `make_rompack.py` gains a
   **pack format v2**: per-slot family byte + name, so one card serves
   every family bitstream and the loader refuses cross-family slots.
4. New `mcr1_console60k/` project = copy of the 60K project with the core
   swapped and a 2-game input mux (Kick: spinner on IP1 via `spinner.sv`,
   1 button; Solar Fox: stick + 2 buttons — bit maps from MAME mcr.cpp,
   recorded in `mcr_game_input_matrix.md` as we did for MCR-2).
5. OSD: game names come from the pack header (already written there by
   `make_rompack.py`) instead of hardcoded strings — after that, no
   family ever touches menu RTL again. Prefs record gains the family
   byte (sector format has room).

Deliverable: `bitstreams/console60k_mcr1.fs` — boots Kick, OSD switches
between the three, prefs persist. **This phase is deliberately first: it
forces all the multi-family packaging decisions while the RTL risk is
near zero.**
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

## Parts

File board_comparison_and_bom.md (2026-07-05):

# FPGA Board Comparison & Custom Shield BOM

This document provides a cost and feature comparison of the various Sipeed Tang FPGA board options for building the Bally Midway MCR arcade core, followed by a Bill of Materials (BOM) estimate for the custom **Option A Shield** (Universal MCR Cabinet Interface).

---

## 1. FPGA Board & Hardware Setup Comparison

Here is a comparison of the primary hardware architectures we evaluated for running the MCR arcade core, including where the **iCEPi Zero** fits in.

| Specification / Option | Tang Primer 25K (V1 On-Chip) | Tang Primer 25K (V2 SDRAM) | iCEPi Zero (Lattice ECP5) | Tang Console 60K | Tang Console 138K |
| :--- | :--- | :--- | :--- | :--- | :--- |
| **FPGA Chip** | GW5A-LV25 | GW5A-LV25 | Lattice ECP5U-25F | GW5A-LV60 | GW5AST-LV138 |
| **Logic Cells (LUT)** | 23,040 | 23,040 | 24,000 | 60,000 | 138,240 |
| **On-Chip Block RAM** | 126 KB (56 blocks) | 126 KB (56 blocks) | 112 KB | ~320 KB (140+ blocks) | 765 KB (340 blocks) |
| **External Memory** | None | 64Mbit SDRAM Card | **32MB SDRAM** (Onboard) | **512MB DDR3** (On SOM) | **1GB DDR3** (On SOM) |
| **Free GPIO Pins** | **26** (40-Pin) + **8** (PMOD) | **8** (PMOD 1 only) | **28** (40-Pin Header) | **92** (76 GPIO + 16 PMOD) | **92** (76 GPIO + 16 PMOD) |
| **MCR Game Support** | Partial (No Playfield Gfx) | Full MCR-1/2/3 Games | Full MCR-1/2/3 Games | Full MCR-1/2/3 Games | Full MCR-1/2/3 Games |
| **Video & Audio Path** | On-board parallel | HDMI -> VGA/Audio Dongle | GPDI Port / Parallel | Onboard Native HDMI & DAC | Onboard Native HDMI & DAC |
| **Pin Congestion** | Low | High (Pmod sharing) | Low (SDRAM is onboard) | Zero | Zero |
| **Toolchain** | Gowin EDA | Gowin EDA | **Open Source** (yosys/nextpnr) | Gowin EDA | Gowin EDA |
| **Estimated Price (Kit)**| **~$25.00** | **~$35.00** (Kit + SDRAM) | **~$49.00** | **~$55.00** (SOM + Dock) | **~$99.00** (SOM + Dock) |
| **Extra Modules Needed** | PMOD HDMI ($5) | PMOD HDMI ($5) + Dongle ($5) | GPDI-to-HDMI Cable ($5) | None | None |
| **Total Hardware Cost**  | **~$30.00** | **~$45.00** | **~$54.00** | **~$55.00** | **~$99.00** |

### Recommendations:
* **Best Value / Easiest Integration: Tang Console 60K ($55)**
  Because the DDR3 memory is built directly into the System-on-Module (SOM), it does not block the carrier board's pins. With **92 free GPIO pins**, native HDMI, and onboard audio DACs, you do not need shift registers or HDMI converters. It has more than enough on-chip block RAM (320KB) to run any MCR game without memory limits.
* **Cheapest Entry Point: Tang Primer 25K V1 ($30)**
  Great for initial desk testing and cabinet control/audio wiring verification. However, playfield background graphics are disabled to fit the block RAM budget.

---

## 2. Custom Shield Bill of Materials (BOM) Estimate

Below is the estimated Bill of Materials to manufacture and assemble the custom **Option A Interface Shield** (Universal MCR Cabinet Interface).

### Option A.1: Parallel Shield (For Tang Primer 25K V1, or Tang Console 60K/138K)
This PCB is a passive shield that routes video, audio, and inputs in parallel. It is simple, highly reliable, and uses no active serial ICs.

| Item | Component Description | Designator | Qty | Unit Cost | Total Cost | Source Example |
| :--- | :--- | :--- | :--- | :--- | :--- | :--- |
| 1 | **Custom PCB (2-Layer)** | Board | 1 | $2.00 | $2.00 | JLCPCB / PCBWay (qty 5 minimum) |
| 2 | **opto-isolators (4-channel)** | U1, U2, U3 | 3 | $0.40 | $1.20 | TLP281-4 (SMD) |
| 3 | **LM386 Mono Audio Amp** | U4 | 1 | $0.35 | $0.35 | LM386 (DIP or SOIC) |
| 4 | **5V Step-Down Buck Regulator** | VR1 | 1 | $1.20 | $1.20 | LM2596 Module or MP1584EN |
| 5 | **R2R Resistor Arrays (10k/20k)** | RN1, RN2, RN3 | 3 | $0.20 | $0.60 | 9-pin SIP Resistor Network |
| 6 | **Discrete Resistors & Caps** | R1-R20, C1-C10 | 1 | $1.00 | $1.00 | 0805 SMD Resistors/Capacitors |
| 7 | **BC847 NPN Transistor** (Sync) | Q1, Q2 | 2 | $0.05 | $0.10 | BC847 (SOT-23) |
| 8 | **MCR Connector Headers** | J2, J3, J4, J5 | 4 | $0.50 | $2.00 | 2.54mm Pin Headers / Molex KK |
| 9 | **Female Pin Headers (to Dock)** | JP1, JP2 | 2 | $0.40 | $0.80 | 40-Pin and PMOD sockets |
| **Total**| | | | | **~$9.25** | *Excludes shipping (~$15 from China)* |

---

### Option A.2: Serial Shift-Register Shield (For Tang Primer 25K V2 + SDRAM)
If using the SDRAM card on the Tang Primer 25K, you must read the buttons serially due to pin starvation. This shield adds shift registers to read controls over 3 PMOD pins.

| Item | Component Description | Designator | Qty | Unit Cost | Total Cost | Source Example |
| :--- | :--- | :--- | :--- | :--- | :--- | :--- |
| 1 | **Custom PCB (2-Layer)** | Board | 1 | $2.00 | $2.00 | JLCPCB |
| 2 | **74HC165 8-bit Shift Register**| U1, U2 | 2 | $0.15 | $0.30 | 74HC165 (SOIC-16) |
| 3 | **opto-isolators (4-channel)** | U3, U4 | 2 | $0.40 | $0.80 | TLP281-4 |
| 4 | **5V Step-Down Buck Regulator** | VR1 | 1 | $1.20 | $1.20 | MP1584EN Buck Board |
| 5 | **Discrete Resistors & Caps** | R1-R20, C1-C10 | 1 | $1.00 | $1.00 | 0805 SMD |
| 6 | **MCR Connector Headers** | J2, J3, J4, J5 | 4 | $0.50 | $2.00 | 2.54mm Molex KK |
| 7 | **Female Pin Headers (to Dock)** | JP1 | 1 | $0.40 | $0.40 | 12-pin PMOD socket |
| **Total**| | | | | **~$7.70** | *Excludes shipping* |

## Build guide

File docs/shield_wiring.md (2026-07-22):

# MCR shield — connector footprints & chip wiring

Build companion to `shield_j10_pinout.md` (the FPGA-side header) and
`universal_mcr_shield_spec.md` (electrical spec). This is the **cabinet
side**: which physical connectors the harness plugs into, and how the
input/output/analog chips wire between those connectors and the J10 header.

Interface style is settled (spec §0): the **cabinet harness plugs into the
shield**; the FPGA maps every pin per game, so nothing is rewired. Rev A
targets the **SSIO-family connectors** (MCR-1/2 + SSIO MCR-3).

Pin functions below are from `docs/MCR_Master_Pinouts.pdf` (the master
matrix) — authoritative for what each pin does. Physical housing/pin-count
should be confirmed against a real MCR harness before ordering connectors.

---

## 1. Cabinet connectors (what the harness plugs into)

**Two pitches, and only one is ours.** MCR used both .156" and .100"/ribbon
connectors, but they served different jobs:

- **.100" (2.54 mm) / ribbon — board-to-board interconnect, NOT ours.** The
  original MCR boardset (CPU + video-gen + SSIO/sound) was stacked and
  interconnected with small-pitch ribbon/SIPP connectors (the MCR FAQ:
  "very early MCR games used SIPP-style sockets for the J1 and J2 connectors
  with solid core wire ribbon cables interconnecting the boards"). **The
  shield replaces the entire boardset, so those interconnects simply don't
  exist for us** — there are no separate boards to link.
- **.156" (3.96 mm) — the cabinet harness, which is what the shield
  presents.** Player controls, coins, video, power, audio: the connectors
  the cabinet's own wiring plugs into.

So for the shield, target the **.156" cabinet-harness connectors** below.
(Pitch on a couple of individual connectors — the video connector
especially — is worth confirming against a real harness or the specific
game's schematic before ordering; see the caveat after the table.)

Present these on the shield edge, keyed, in the standard MCR positions:

| Ref | Connector | Pins | Carries | Footprint (verify vs harness) |
|---|---|---:|---|---|
| **J2** | Player 1 controls | 13 | P1 stick + 2 buttons, GND | .156" 13-pin (1-row) header, key at the game's keyed pin |
| **J3** | Coin door / system | 5–6 | Coin1/2, Start1/2, Tilt | .156" 6-pin header |
| **J4** | Opt X (dial bus / analog) | 10 | 8-bit dial data **or** analog pots, key, GND | .156" 10-pin header; **also feeds the ADC — see §4** |
| **J5** | Opt Y / Player 2 | 19 | P2 controls, trackball-Y, P2 mux data | .156" 19-pin header |
| **Video** | RGB + sync | 9 | R, G, B (+ GNDs), HSync, VSync, key | .156" 9-pin header |
| **Audio** | speaker | 2 | speaker + / − | .156" 2-pin or screw terminal |
| **Power** | cabinet 12 V in | 2–3 | +12 V, GND (shield bucks to 5 V/3.3 V) | screw terminal or .156" |

Notes:
- **J1 / +5 V:** the shield generates its own 5 V/3.3 V from cabinet 12 V
  (spec §3). Do **not** take the cabinet's +5 V logic rail.
- **Key pins** (J4-8, Video-7) are the connector's mechanical key — leave
  the shield position blank/plugged to match.
- Grounds (J2-13, J4-10, Video-2/4/6) all tie to the shield star ground.
- **Pitch caveat — verify before ordering.** The controls/coin/power
  connectors are .156"; the **video connector's pitch (.156 vs .100) is the
  one to double-check** against the target game's harness, as it varied. The
  dial games' 8-bit Opt-X bus arrives on J4 as **parallel digital**, not
  raw quadrature — the cabinet's *Angle Encoder Board* converts the knob's
  quadrature to parallel position data before J4/J6 (MCR FAQ). So the '165
  reads it directly, **provided the cabinet still has its Angle Encoder
  Board**; a bare encoder would need quadrature decode in the FPGA
  (`spinner.sv`) instead.

Pin-by-pin functions (from the master matrix), abbreviated to the standard
MCR function — the FPGA re-interprets per game:

```
J2 (P1):   1 Up   2 Down  3 Left  4 Right  5 Btn1  6 Btn2            13 GND
J3 (sys):  1 Coin1  2 Coin2  3 Start1  4 Start2  5 Tilt
J4 (OptX): 1..7 = Data D0..D6   8 Key   9 = Data D7   10 GND
J5 (OptY): 1..6 = P2mux/D0..D5  15 D6/P2Up  16 D7/P2Dn  17 P2Left
           18 P2Right  19 P2Btn1
Video:     1 Red  2 GND  3 Green  4 GND  5 Blue  6 GND  7 Key
           8 HSync(-)  9 VSync(-)
```

---

## 2. Input chain — harness → 74AHC165 → FPGA

Every switch/data line goes: **cabinet pin → passive pad → 74AHC165
parallel input**. The FPGA clocks the chain out on 3 J10 pins
(`IN_CLK`/`IN_LOAD_N`/`IN_DATA`). Allocate **one '165 per SSIO input port**
(spec/pinout §6a) so 3-player and remapped-connector games all fit.

### 2a. The per-line conditioning pad (identical on every input)

```
   cabinet pin ──┬───[ 4.7kΩ ]─── +5V        (pull-up: idle = high)
                 │
                 └───[ 1kΩ ]──┬────────── 74AHC165 input (A..H)
                              │
                    10nF ═════╪═════ GND      (RC ~10µs debounce/filter)
                              │
                    BAT54S ───┤          (clamp to +5V / GND: a 12V
                     (dual)   │           miswire drops across the 1kΩ)
```

74AHC165 runs at **3.3 V**; its inputs are 5.5 V-tolerant, so they take the
5 V harness levels directly (spec §2). Idle = 5 V = logic 1; a closed
switch pulls to GND = logic 0 — the same polarity the SSIO saw.

### 2b. Chain topology (7 devices, 3 FPGA pins)

```mermaid
flowchart LR
    subgraph FPGA["Tang 60K (J10)"]
      CLK["IN_CLK (pin25)"]
      LD["IN_LOAD_N (pin26)"]
      DAT["IN_DATA (pin27)"]
    end
    U1["U1 74AHC165<br/>IP0: coins/start/tilt/svc/btn"] -->|QH→SER| U2["U2 74AHC165<br/>IP1: P1 stick / dial"]
    U2 -->|QH→SER| U3["U3 74AHC165<br/>IP2: P2 / trackball-Y / gas"]
    U3 -->|QH→SER| U4["U4 74AHC165<br/>IP4: aux / P3 stick"]
    U4 -->|QH→SER| U6["U6 74AHC165<br/>SW1 game DIPs (IP3)"]
    U6 -->|QH→SER| U7["U7 74AHC165<br/>SW2 system DIPs"]
    CLK -->|CP, bussed to all| U1
    LD -->|PL̄, bussed to all| U1
    U7 -->|QH| DAT
```

`IN_LOAD_N` low pulse snapshots **all** '165 inputs at the same instant, so
the 8-bit dial/trackball buses can't tear. Control lines (`CP`, `PL̄`) bus
to every device; only the last device's `QH` returns on `IN_DATA`.

Per-'165 pin map (all devices identical): `CP`=pin2, `PL̄`=pin1,
`QH`=pin9, `SER`(cascade in)=pin10, `CE̅`=pin15→GND, `VCC`=pin16→3V3,
`GND`=pin8. Parallel inputs A..H = pins 11,12,13,14,3,4,5,6.

### 2c. Which harness pins land on which '165

| '165 | SSIO byte | Wire these harness pins to A..H |
|---|---|---|
| U1 | IP0 | J3-1 Coin1, J3-2 Coin2, J3-3 Start1, J3-4 Start2, J3-5 Tilt, J2-5 Btn1, (service), (spare) |
| U2 | IP1 | J2-1 Up, J2-2 Dn, J2-3 Lf, J2-4 Rt, J2-6 Btn2 **— or —** J4-1..7,9 (the 8-bit Opt X dial, dial games) |
| U3 | IP2 | J5-17 P2Lf, J5-18 P2Rt, J5-19 P2Btn1, J5-15 P2Up, J5-16 P2Dn **— or —** J5-1..6,15,16 (Opt Y bus) |
| U4 | IP4 | J6 aux / **P3 stick+buttons (Rampage)** / P2 dial |
| U6/U7 | IP3 | on-shield SW1 / SW2 DIP banks (no harness) |

The "**— or —**" rows are the same '165 serving a stick **or** a dial,
depending on the cabinet's control — the FPGA reads the byte and maps it per
game. A given cabinet wires one or the other into U2/U3.

---

## 3. Output chain — FPGA → 74HC595 → ULN2803 → loads

Two '595s (16 bits) on 4 J10 pins (`OUT_CLK`/`OUT_DATA`/`OUT_LATCH`/
`OUT_EN_N`), then a ULN2803 per '595 for the 12 V coin meters/lamps.

```mermaid
flowchart LR
    subgraph FPGA["Tang 60K (J10)"]
      OCK["OUT_CLK (pin28)"]
      OD["OUT_DATA (pin31)"]
      OL["OUT_LATCH (pin32)"]
      OE["OUT_EN_N (pin34)"]
    end
    OD --> U8["U8 74HC595"]
    U8 -->|QH'→SER| U9["U9 74HC595"]
    OCK -->|SRCLK, bussed| U8
    OL -->|RCLK, bussed| U8
    OE -->|OE̅, bussed + pull-up| U8
    U8 --> UA["ULN2803"] --> L1["Coin meters, Start lamps, P3 lamp"]
    U9 --> UB["ULN2803"] --> L2["output_6 / Spy Hunter lamp panel"]
```

- `OUT_EN_N` **must have a 10 kΩ pull-up to 3V3 on the shield** so all
  outputs stay off through FPGA configuration (no coin-meter clicks).
- ULN2803 has built-in flyback diodes — fine for inductive coin meters.
- Loads run off cabinet 12 V; the ULN sinks to GND.

Per-'595: `SER`=pin14, `SRCLK`=pin11, `RCLK`=pin12, `OE̅`=pin13,
`QH'`(cascade)=pin9, `QA..QH`=pins15,1..7, `VCC`=16→3V3, `GND`=8.

---

## 4. Analog controls — the ADC (Spy Hunter & Max RPM only)

**Which games need it:** exactly two, both later-phase:

| Game | Family | Pots | MAME device |
|---|---|---|---|
| **Spy Hunter** | MCR3Scroll | steering + gas (2, muxed) | on-board ADC0848/0844 |
| **Max RPM** | MCR3Mono | 2 wheels + 2 pedals (4) | ADC0844 |

**Every other MCR control is digital** — buttons/sticks are switches, and
the dials/spinners/trackballs (Tron, Kick, Kroozr, Wacko, Two Tigers, Discs
of Tron) are **optical encoders**, which the FPGA decodes with the existing
`spinner.sv` quadrature logic. No ADC for any of those.

Why an ADC is needed here and nowhere else: on the real hardware the
steering/gas **potentiometers' analog wiper voltage came into the game
board and was digitized by an on-board ADC0844** (MAME instantiates it in
the machine config, e.g. `ADC0844(config, m_maxrpm_adc)` with the pots on
its channels). Our shield replaces that board, so it must carry the ADC to
read the pots. The pot wires arrive on the **Opt X (J4) / Opt Y (J5)**
lines — the same physical pins a dial game would drive digitally.

### 4a. Put it on the board with a switch — yes, and here's how

Because a cabinet is *one* game, and the analog pins overlap the digital
Opt X/Opt Y pins, route those lines to **either** the '165 (digital) **or**
the ADC (analog), selected per cabinet:

```mermaid
flowchart LR
    J4["J4 / J5 data lines<br/>(dial data OR pot wiper)"]
    JMP{"MODE jumper<br/>per channel"}
    P165["→ 74AHC165 pad<br/>(digital dial games)"]
    ADC["ADC (SPI)<br/>pots → 8-bit"]
    J4 --> JMP
    JMP -->|DIGITAL| P165
    JMP -->|ANALOG| ADC
    ADC -->|SPI: SCLK/MOSI/MISO/CS on<br/>3 spare J10 pins + 1| FPGA["Tang 60K"]
    P165 --> FPGA
```

Recommended parts and wiring:
- **ADC: a modern SPI ADC — ADS7830 (8-ch, I²C) or MCP3208 (8-ch, SPI),
  populate-optional.** (You *can* use a real ADC0844 to match, but a modern
  SPI/I²C part is far easier to talk to from the FPGA and needs no special
  timing.) 8 channels covers Max RPM's 4 and Spy Hunter's 2 with room.
- **Analog reference / conditioning:** each pot wiper → RC (series ~1 kΩ,
  100 nF to GND) → ADC channel; pot ends to the shield's clean 5 V and GND.
- **MODE jumpers:** a small 2-pin jumper (or a 2-pole DIP) per analog
  channel selects that harness line to the '165 pad or the ADC input. Set
  once at install ("this cabinet is Spy Hunter → Opt X = ANALOG").
- **FPGA side:** the ADC's SPI/I²C lands on **spare J10 pins** (9, 19, 20,
  29/30, 38 are free) — no impact on the input/output chains. The core reads
  the ADC channels and feeds the digitized value into the analog input port;
  the running game_id tells it whether to use the ADC or the '165 byte.

### 4b. FPGA-driven mode switch (recommended — no jumper)

The manual jumper works, but the FPGA can drive the digital/analog switch
itself, which keeps the "select the game, nothing else" promise for the
analog cabinets too. It's actually cleaner **and reuses hardware already on
the shield**:

```mermaid
flowchart LR
    GID["core game_id<br/>(from OSD)"] --> MB["MODE bit<br/>= analog for<br/>Spy Hunter / Max RPM"]
    MB -->|rides a spare<br/>74HC595 output bit| SW["74HC4053 analog switch<br/>(per analog channel)"]
    J["J4/J5 analog-capable pin"] --> SW
    SW -->|MODE=digital| PAD["4.7k pull-up + '165 pad"]
    SW -->|MODE=analog| ADCIN["ADC channel (clean)"]
```

How it works, step by step:

1. **The FPGA already knows the running game** (`game_id` from the OSD). It
   derives one **MODE** bit — high only for Spy Hunter / Max RPM. MODE is
   static per game (set when the game loads, never changes mid-play).
2. **MODE rides a spare bit of the existing 74HC595 output chain** — no new
   J10 pin. The '595s are already on the board for lamps/meters; one unused
   output bit becomes the mode line.
3. That bit drives a **74HC4053-class analog switch** on each analog-capable
   channel (≈4: Max RPM's worst case). In **digital** mode the pin routes to
   its normal pull-up + '165 pad; in **analog** mode the switch **lifts the
   pull-up** and routes the pin straight to the ADC channel. Lifting the
   pull-up is the whole point — a 4.7 kΩ pull-up to 5 V would offset a pot's
   reading, so it must be out of circuit for analog.
4. In analog mode the '165 still *sees* that pin and clocks in some
   arbitrary 0/1 — **harmless, the FPGA ignores those bits for that game.**

**Bonus you get for free:** the *channel* muxing (steering vs gas; which of
Max RPM's four axes) was **already game-driven on the original hardware** —
the game wrote the ADC0844's channel select and RD/WR strobes through its
SSIO output ports (`mcr3.cpp`: Max RPM latches the mux on `output`, Spy
Hunter toggles the ADC via an output bit). Our core reproduces those output
ports, so if you wire the core's `output_4/5/6` to the ADC's channel-select/
strobe lines, the game sequences the ADC exactly as it did in 1984 — no
extra logic. The only *new* thing is the per-cabinet digital-vs-analog pin
routing (MODE), because a universal shield serves both a dial cabinet and a
pot cabinet on the same pins, whereas the original Spy Hunter board was
always analog.

**Recommendation:** design for the FPGA-driven switch (MODE on a '595 bit +
74HC4053s), and keep a **manual override jumper in parallel** as a
populate-option fallback — cheap insurance while the analog path is
unproven. Cost over the jumper-only build: ~one 74HC4053 (maybe two) and a
few traces; payoff: the analog cabinets are as plug-and-play as the rest.

**One detail to lock down at Phase D:** exactly which harness pins carry the
Spy Hunter / Max RPM pot wipers (the master matrix normalizes them onto the
"Opt X D0–D7" label, but 2 pots ≠ 8 data bits, so the physical wiper pins
need confirming against those games' schematics). Finalize the analog
channel count and pin map when the first analog core (Spy Hunter) is brought
up — until then, route the ADC + switch footprints for the worst case (4
channels) and leave them unpopulated.

---

## 5. Video DAC & sync buffer (live today)

- **RGB:** 3-bit R2R per gun into Video-1/3/5 — MSB 510 Ω, then 1 kΩ, 2 kΩ,
  summed into the monitor's 75 Ω ≈ 1 Vp-p (bench-proven, `bench_wiring.md`).
  Drive from J10 `VID_R/G/B` (§ pinout). Video-2/4/6 = GND.
- **Sync:** J10 `VID_HS`/`VID_VS` (3.3 V, negative) → 74HCT244 at 5 V (TTL
  thresholds accept 3.3 V in) → Video-8/9. Real MCR monitors take separate
  H/V; the pin-39/40 straps offer csync for OSSC/RetroTink gear.
- **15 kHz:** close the J10 pin-37 solder jumper for cabinet timing.

---

## 6. Power

Cabinet **+12 V → screw terminal → buck (5 V, ≥1.5 A) → LDO (3.3 V)**.
5 V feeds the AHC/HC logic rails and the input pull-ups; 3.3 V is the logic
VCC and the FPGA level. Audio amp (LM386) runs off the 12 V rail. Do not
back-feed the cabinet 5 V (spec §6.1).

---

## 7. BOM summary (control interface)

| Qty | Part | Role |
|---:|---|---|
| 7 | 74AHC165 | input chain (5 V-tolerant, 3.3 V VCC) |
| 2 | 74HC595 | output chain |
| 2 | ULN2803 | 12 V coin-meter / lamp drivers |
| 1 | 74HCT244 | 5 V sync buffer |
| 1 | ADS7830 / MCP3208 (opt.) | analog pots (Spy Hunter / Max RPM) |
| 1–2 | 74HC4053 (opt.) | FPGA-driven digital/analog mode switch (§4b); MODE rides a spare '595 bit |
| — | manual MODE jumper (opt., fallback) | override the FPGA switch per cabinet |
| — | R2R resistors (9), sync caps, BAT54S clamps, pull-ups | passives |
| 1 | buck + LDO | 12 V → 5 V → 3.3 V |
| — | .156" MCR connectors (J2/J3/J4/J5/Video/Audio) | harness interface |

Everything except the ADC block is required for every cabinet; the ADC
block is populate-if-analog.

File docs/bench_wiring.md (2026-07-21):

# Bench wiring — Tang Console 60K (current bitstream)

What the **bitstreams in `bitstreams/` actually drive today**. Generated from
`mcr2_console60k/src/mcr2_console60k.cst`; if you change the CST, update this.

> **Do not wire from `universal_mcr_shield_spec.md` §4b.** That is the future
> shield's cabinet-connector plan and deliberately differs from these
> desk-test assignments. §4a of that doc is still the authority for which
> FPGA ball a J10 pin reaches; this page is which *signal* is on it now.

## Finding pin 1 on J10

J10 is the 2×20 header **nearest the PMOD sockets** (the other one, J9, is
the SDRAM slot — leave it alone). Odd pins are one row, even the other, so
pins 1/2 face each other, 3/4, and so on.

**Anchor electrically, don't count from the end:** with the board powered,
find the pair reading **+5 V and GND** — that is pins **11 and 12**, the
sixth pair. Count from there. Pin 12 is your ground for everything below.

## Current J10 map

| J10 pin | Signal | Notes |
|---:|---|---|
| 1, 2, 3, 4 | `vga_r[0..3]` | red, LSB→MSB |
| 5, 6, 7, 8 | `vga_b[0..3]` | blue, LSB→MSB |
| 11 | **+5 V** | supply *out*; do not back-feed (see TODO) |
| 12 | **GND** | reference for everything |
| 13, 14, 15, 16 | `vga_g[0..3]` | green, LSB→MSB |
| 17 | `vga_hs` | HSync — carries **CSYNC** in 15 kHz mode |
| 18 | `vga_vs` | VSync |
| 21 | `debug_o[0]` | DDR3 calibration done — steady 3.3 V = trained |
| 22 | `debug_o[1]` | pixel-clock heartbeat — should bounce ~1 Hz |
| 23 | `debug_o[2]` | 27 MHz reference heartbeat — bounces ~0.8 Hz |
| 24 | `debug_o[3]` | DDR reset — steady LOW when healthy |
| 35 | `audio_l` | PWM, needs an RC filter before an amp |
| 36 | `audio_r` | PWM |
| 37 | `mode15_n` | **open = 31 kHz**, jumper to GND = 15 kHz |
| 39 | sync format | 15 kHz: open = separate H/V (default), GND = composite sync on HS |
| 40 | VSync enable | 15 kHz: open = VS driven, GND = VS held inactive |

Everything else on J10 is unassigned in the current bitstream.

## Analogue video, option A — DE-15 breakout + 9 resistors

Cheapest and least ambiguous: a screw-terminal VGA breakout, no active
parts, and it doubles as a prototype of the shield's video DAC.

Use only the **top three bits** of each colour (`[3:1]`) — bit 0 is just an
MSB copy for the 4-bit Pmod, so leave `vga_*[0]` unconnected.

| VGA pin | From J10 pins (MSB→LSB) | Through |
|---|---|---|
| 1 (Red) | 4, 3, 2 | 510 Ω, 1 kΩ, 2 kΩ — join at the terminal |
| 2 (Green) | 16, 15, 14 | 510 Ω, 1 kΩ, 2 kΩ |
| 3 (Blue) | 8, 7, 6 | 510 Ω, 1 kΩ, 2 kΩ |
| 13 (HSync) | 17 | direct (or ~100 Ω) |
| 14 (VSync) | 18 | direct |
| 5,6,7,8,10 (GND) | 12 | direct |

560 Ω / 1.1 k / 2.2 k are fine substitutes.

## Analogue video, option B — Digilent PmodVGA

**The Rev C PmodVGA is not passive.** It has two SN74ALVC245 buffers that
must be powered or it outputs nothing:

- **Feed VCC 3.3 V** (J1 pin 6 or 12, and J2 pin 6 or 12).
- **Never 5 V** — the ALVC245's absolute maximum supply is ~4.6 V, so J10
  pin 11 would risk damaging the module. Take 3.3 V from a PMOD socket's
  3V3 pin.

Jumper recipe (J10 → Pmod):

| J10 | PmodVGA |
|---|---|
| 1,2,3,4 | J1 pins 1,2,3,4 (R0–R3) |
| 5,6,7,8 | J1 pins 7,8,9,10 (B0–B3) |
| 13,14,15,16 | J2 pins 1,2,3,4 (G0–G3) |
| 17 | J2 pin 7 (HS) |
| 18 | J2 pin 8 (VS) |
| 12 | J1 pin 5 and J2 pin 5 (GND) |
| 3V3 from a PMOD socket | J1 pin 6 and J2 pin 6 (VCC) |

**Plugging the Pmod straight into the two PMOD sockets is not currently
supported.** Sipeed's socket pin order is not Digilent's, and the two straps
that used to resolve that mapping (J10-39/40) were repurposed for the 15 kHz
sync format, which turned out to matter more. The jumper recipe above works
regardless of socket orientation.

## 15 kHz vs 31 kHz

- **J10-37 open** → 31 kHz progressive, works on any VGA monitor.
- **J10-37 to GND** → native 15 kHz arcade timing (15.77 kHz; displays
  usually report it as "16 kHz", which is correct). Needs an arcade CRT,
  multisync, or an OSSC/RetroTink — an ordinary VGA LCD will not sync, which
  is expected rather than a fault.

### 15 kHz sync format (J10-39 / J10-40)

Displays disagree about what a 15 kHz source should look like, so the format
is strap-selectable rather than baked in:

| J10-39 | J10-40 | Output at 15 kHz |
|---|---|---|
| open | open | **separate H and V sync — default**, and what a real MCR cabinet uses (Video pins 8 and 9) |
| GND | open | composite sync on HS (RGBS) — for an OSSC/RetroTink or SOG-wired monitor |
| GND | GND | composite sync on HS, VS inactive — single-sync RGBS |
| open | GND | separate H sync, VS inactive |

31 kHz always uses separate H/V regardless of these straps.

**If a display drops a whole colour channel at 15 kHz** (green vanishing is
the classic symptom — greys turn magenta, olive turns purple, red and blue
stay correct), it has mis-detected the sync format, not lost a wire: the
FPGA drives all three channels through identical logic and cannot lose one
on its own. Composite sync used to be the default here and provoked exactly
that on a 15 kHz-capable LCD. **Displays latch their format detection**, so
switching format while the signal is live often will *not* re-trigger it —
disturb sync or power-cycle the display between attempts, or the test looks
like it failed when it did not.

HDMI keeps working in both modes (the framebuffer captures whatever the core
emits), so you always have a reference picture.

## No wiring needed

- **HDMI** — onboard connector.
- **USB gamepad** — left USB-A port. **Select+Start opens the game-select
  OSD** (Up/Down move, A loads from the SD pack, B exits). The screen
  freezing (HDMI) or dropping sync (VGA) for ~1 s after pressing A is the
  reload, not a crash.
- **MicroSD** (ROM loading) — onboard slot.
- **Status beacon** — USB-C serial, 115200 8N1: `FB c_ r_ x____ q__ d__ L__`
  (DDR calib, DDR reset, pixel-clock counter, 27 MHz counter,
  d = game_id[2:0] in the high 3 bits + capture delay in the low 5,
  loader state).

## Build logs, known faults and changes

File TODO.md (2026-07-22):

# TODO / open issues

Single list of known gaps. Detail lives in the linked docs; this is the
index so nothing hides in a §6 somewhere. Roughly ordered by "blocks the
next real milestone" within each section.

---

## Cocktail mode — unaddressed across every game

**Everything currently assumes an upright cabinet.** This is not one switch;
it touches four separate things, and each game does it differently:

1. **Cabinet DIP is hardcoded upright.** `input_3` is a constant per game in
   `mcr2_console60k_top.sv` (Domino `0x3E` — note `0xFF` would select
   *cocktail*; Tron `0x80`). Nothing lets an operator choose. SW2-3 in the
   shield spec is reserved for this but unimplemented.
2. **Player-2 inputs are tied off.** Cocktail play needs the second player's
   controls, which live in different ports per game and are currently
   constants: Tron's cocktail joystick (IP2 upper nibble), Satan's Hollow
   (IP1 upper nibble), Two Tigers' P2 dial (IP4, tied to 0), Wacko's
   `IP1.ALT`/`IP2.ALT` trackball.
3. **Wacko's trackball mux is not implemented.** SSIO output port 4 bit 0
   selects P1 vs cocktail-P2 trackball. `mcr_sound_board.vhd` *does* expose
   `output_4`, but `mcr2.vhd` never brings it out to the entity — so this
   needs a (small) core port addition before cocktail Wacko can work. Upright
   play is unaffected, which is why it works today.
4. **Screen flip is unverified.** Cocktail cabinets rotate the image 180° for
   player 2. Need to establish whether the core implements flip at all, how
   it is triggered, and how it interacts with the DDR3 framebuffer capture
   (which samples the core's raster directly).

Also needed for real two-player use: a **second USB pad** on port 2
(usb2_dp M15 / usb2_dn M16 — pins verified, unused).

### How the cabinet setting actually reaches the core (two layers)

`input_3` **is** the original board's DIP bank (the switches at B3), read by
the SSIO as input port 3 — an internal core signal, not a pin. Our shield
replaces that board, so the FPGA has to supply those bits:

    SW2-3 (switch on the shield)
      -> 74HC165 chain -> 3 FPGA pins     (switch reaches the FPGA)
      -> per-game bit placement
      -> input_3 bit N -> core SSIO       (FPGA reaches the core)

So the cocktail switch both runs through the 165 *and* lands in `input_3`;
they are different layers. Neither costs additional pins.

**The bit position is different per game** (verified against MAME):

| Game | Cabinet bit in IP3 |
|---|---|
| Tron, Satan's Hollow | bit 1 (0x02) |
| Domino Man, Wacko, Kozmik Kroozr | bit 6 (0x40) |
| Two Tigers (conversion set) | none — IP3 unused entirely |

**`input_3` is not purely DIP switches.** Tron puts the *cocktail player's
fire button* on IP3 bit 7 (`PORT_BIT(0x80, ..., IPT_BUTTON1) PORT_COCKTAIL`),
so that port mixes config switches with a live cabinet input. Open question:
the master pinout matrix lists Tron as having **no J5**, so where a cocktail
Tron's P2 fire button arrives on the harness is undocumented — needs a
cocktail cabinet manual or real hardware. (J5-19 "P2 Button 1" is pinned and
is the obvious candidate, but that is a guess.)

**Other pin impact:** cocktail P2 controls for Tron/Domino arrive on SSIO
IP2 = J5 1-8, and IP4 / J6 is covered too — every harness input rides the
shield's 74HC165 chain (`docs/shield_j10_pinout.md`), so no per-line pin
budget exists anymore. See the Shield PCB section.

---

## Hardware bring-up (untested on the board)

- ~~SD ROM loader has never run on hardware~~ **RESOLVED 2026-07-21**: pack
  written to the card with `tools/write_rompack.py` (lands in the gap
  before the card's partition, filesystem untouched) and games load from
  the OSD on hardware. The reject-foreign-card path was proven earlier
  (beacon `L09`).
- ~~HDMI black screen~~ **RESOLVED 2026-07-20** after a long hunt. HDMI now
  works: 720p from the DDR3 framebuffer, game + border verified on hardware.
  Root causes, in the order found (each invisible to the error log):
  1. video reset gated on ROM loading (fixed: video resets from power-on only)
  2. IDE `Place_Option 0` vs build.tcl's 2 (DDR3 never trained on IDE builds)
  3. **gbatang's cross-PLL serializer clocking** — pixel clock from the DDR3
     controller, serial clock from a second PLL; OSER10 phase left to routing
     luck. Restructured to NESTang's single chain (27→PLL→371.25→CLKDIV/5)
     with a shadow-raster + async-FIFO bridge into the scanout domain.
  4. **Verilog use-before-declaration** — Gowin makes an implicit 1-bit wire
     with only a warning; the encoder's rgb input was one floating bit and
     the pixel FIFO was swept. Post-build check #4 in CLAUDE.md now guards
     this ("Undeclared symbol" grep must be empty).
  Diagnostic assets that earned their keep, kept in the repo: the UART
  beacon, `diag/hdmi_selftest` (dvi_tx 640x480), `diag/fb_selftest`
  (framebuffer alone), `diag/nes_video_selftest` (NESTang clocking, the
  decisive one). Verified only in simulation
  against a card model (`make -C sim`). The card image is built but not yet
  burned. Beacon `L` low nibble = {sd_ready, sd_err, done, error}; high nibble low 2 bits = USB device type (3 = gamepad).
- **Left-edge pixel overlap.** Root cause is the core's ~13-pixel RGB-vs-hcnt
  pipeline lag. HDMI compensates in the capture window; the analog path did
  not compensate at all until 2026-07 (the previous line's tail leaked into
  the first ~13 visible pixels). Both paths now share the live-tunable
  `cap_delay` — Select + D-pad Right/Left, value in the beacon as `d<hex>`.
  **Still to do: confirm on hardware and hardcode the winning value as
  `CAP_DELAY_DEFAULT`.** One step is <2 screen pixels on HDMI, so it takes
  10–15 taps to see there; it should be far more obvious on analog.
- **Analog framing on a desk LCD is imperfect and expected.** The core emits
  634 pixels/line at 20 MHz; an LCD locks to it (31.55 kHz ≈ VGA's 31.47 kHz)
  but then samples ~800 pixels at 25.175 MHz across our line, stretching
  ~1.26× and mis-positioning active video. Use the monitor's Auto Adjust.
  A real 15 kHz arcade monitor has no sampling window and does not care, so
  this does not affect cabinet use — and fixing it for LCDs would mean
  putting a line buffer/scaler back into the analog path, which is exactly
  what keeps that path shimmer-free. Not worth it.
- **PmodVGA in the PMOD sockets is unproven.** Four strap combinations on
  J10-39/40 resolve row/socket orientation; also note the module is *not*
  passive — its SN74ALVC245 buffers need **3.3 V on VCC** (never 5 V).
  The J10 jumper route (or a DE-15 breakout + 9 resistors) avoids the
  ambiguity entirely.
- ~~Green channel lost at 15 kHz on a 15 kHz-capable LCD~~ **RESOLVED
  2026-07**: the display had mis-detected the sync format. 15 kHz now
  defaults to **separate H and V sync** (also what a real MCR cabinet wants,
  Video pins 8/9); composite sync remains available on the J10-39 strap.
  Two lessons worth keeping: a mis-detected sync format can look exactly
  like a dead colour channel, and **displays latch their format detection**
  — switching format on a live signal may not re-trigger it, which made an
  earlier four-way test look like a total failure when one combination
  actually worked.
- **New games' controls are derived, not played.** Trackball/analogue-stick
  sensitivity on a d-pad is guesswork — Kroozr's stick ramp rate especially.
  Tron's aim direction may need reversing (MAME marks the dial PORT_REVERSE).
- **Two Tigers has +0.08 ns setup slack** — met, but the tightest of the six.
  Suspect timing first if that game alone misbehaves.

---

## Multi-game / product

- **OSD game-select menu is IMPLEMENTED (60K)** — `src/rtl/osd.sv`, drawn in
  the core raster domain so it shows on HDMI + VGA 31 kHz + 15 kHz alike.
  Select+Start opens; Up/Down, A = load slot from SD pack, B = exit. All six
  input maps are now compiled in and muxed at runtime by `game_id`;
  `game_config.vh` only picks the baked-in boot game. **Working on
  hardware 2026-07-21** (menu, SD reload, game switching; navigation
  debounce fixed by frame-rate button sampling). Remaining OSD work:
  - **ROT90 direction unverified**: menu on Tron/Shollow is drawn rotated
    for a cabinet monitor; if it reads mirrored/upside-down, swap the
    mapping noted in `osd.sv` (u/v remap line).
  - **"LOADING..." is never visible**: the core raster stops while the core
    is reset during a reload, so the screen freezes (HDMI) / drops sync
    (VGA) for ~1 s instead. Fix would be keeping the video counters running
    through reset in `mcr2.vhd` (touchy — it's shared with the 25K).
  - **Opening the menu inserts a coin** (Select doubles as Coin1 before the
    Start half of the combo lands). Harmless; goes away when the shield's
    dedicated service button opens the menu instead.
  - **Stale CMOS RAM across switches**: each game boots on the previous
    game's CMOS contents; MCR games checksum it and factory-reset, so this
    should self-heal — verify per game, else clear cmos_ram on reload.
  - ~~No prefs persistence~~ **DONE 2026-07-21**: selections are written
    to SD sector 2047 (CMD24) and win over the baked default at power-on;
    sim-verified round trip (`make -C sim`). Untested on hardware.
  - **Two Tigers' Dogfight Start moved to D-pad Up** (was Select+Start,
    which is now the menu combo).
- **No multiboot selector** for switching MCR family cores (2.5 MB per core,
  so all three fit well under 8 MB of flash).
- **Fallback behaviour is minimal.** Loader failure falls back to the baked
  ROMs and the OSD shows "LOAD FAILED"; the shield spec still wants a status
  LED so a field failure is diagnosable without a display.

## Shield PCB

- **Cabinet-side wiring is documented**: `docs/shield_wiring.md` (connector
  footprints, 74AHC165/74HC595 chain diagrams, sync buffer/DAC, BOM). The
  analog/ADC question is settled: **only Spy Hunter and Max RPM need an
  ADC** (potentiometer steering/pedals; every other control is digital or
  an optical encoder the FPGA decodes). Plan is a populate-optional SPI ADC
  (ADS7830/MCP3208) with a per-channel MODE jumper routing Opt X/Opt Y to
  the '165 (digital) or the ADC (analog), set per cabinet. FPGA reads the
  ADC over spare J10 pins.

- **5 V delivery route unverified** — J10 pin 11 exposes +5 V but sits behind
  the dock's OR-ing/OVP chain; do not back-feed it until traced. USB-C is the
  known-good path.
- **Header pinout is FROZEN (2026-07-21): `docs/shield_j10_pinout.md`.**
  Everything on J10 only — video/audio/straps/LEDs on the pins today's
  bitstreams already drive, ALL cabinet inputs + both DIP banks on a
  7×74AHC165 chain (3 pins; 3.3 V parts, 5 V-tolerant inputs), outputs on a 74HC595+ULN2803 chain (4 pins),
  service button direct. This resolved the old J6/IP4 gap (chain device
  U5) and the lamp/coin-meter question ('595 chain, extensible free).
  Remaining on it:
  - **Expander-chain RTL does not exist yet** — a small module scanning
    the '165s into the input mux (ORed with the USB pad), driving the
    '595s, and a SERVICE_N → OSD-open hook. J10 pins 25-34 are reserved
    and high-Z until then; the shield works for video/audio/straps/LEDs
    with current bitstreams on day one.
  - J6's *cabinet-side* connector wiring wants a manual cross-check
    before crimping harnesses (the matrix PDF has no J6 sheet).
- **`tools/generate_pcb.py` is not synced** to `shield_j10_pinout.md`, and
  still assumes generic 2×20 headers; J9 must stay clear for the SDRAM
  module.
- **138K variant**: header nets are dock-level but the net→ball map is
  SOM-specific; re-extract before targeting it.

## Cores / ports

- **See `docs/mcr_core_roadmap.md`** for the phased plan. All ROMs in `roms/`.
- **MCR3Mono core (Rampage/Sarge/Max RPM/Power Drive/Star Guards) —
  Phase E, core ready, board gated on SDRAM.** `src/rtl/mcr3mono.vhd`
  vendored + adapted (dprams + hcnt_out). Both sound boards verified
  Gowin-clean: Turbo Cheap Squeak (6809 `cpu09l`) and Sounds Good (FX68K).
  Heaviest ROM set (256 KB sprites + 256 KB Sounds Good ROM, both SDRAM;
  64 KB bg baked). Sarge first (TCS, sprites-only SDRAM). Once TCS is
  vendored, demoderb (4-player Demolition Derby) drops into the existing
  MCR-2 core for free. Design in the roadmap.
- **MCR3Scroll core (Spy Hunter/Crater/Turbo Tag) — Phase D, core ready,
  board gated on SDRAM.** `src/rtl/mcr3scroll.vhd` vendored + adapted
  (dprams + hcnt_out). The Cheap Squeak Deluxe / FX68K / pia6821 /
  steering_control sound stack is verified Gowin-clean and listed for
  vendoring at board-build time. Crater Raider first (SSIO-only, no FX68K);
  Spy Hunter adds CSD + steering + lamps. Design in the roadmap.
- **MCR-3 core (Tapper/Timber/Journey/DoT) — Phase C, core ready, board
  gated on SDRAM.** `src/rtl/mcr3.vhd` vendored + platform-adapted (builds
  once wired). Board integration is fully designed in
  `docs/mcr_core_roadmap.md` (memory split: CPU/sound/bg baked BRAM,
  sprites->SDRAM, Journey tape->DDR3; the exact MiSTer sprite interleave;
  40/100 MHz CDC; SD->SDRAM sprite loader). Do the board build AFTER the
  Phase B memtest passes on hardware - Tapper/Timber first (plain SSIO
  sound). Journey needs a DDR3 wave port; DoT ships without speech.
- **SDRAM memtest — Phase B started, not yet on hardware.** Standalone
  test of the Tang SDRAM module (J9) using the exact controller MCR-3 will
  use (`src/rtl/sdram_gw.sv`, Gowin-adapted from MiSTer MCR-3). Flash
  `bitstreams/console60k_sdram_memtest.fs` with the module plugged in:
  J10 LED debug_o[0]=PASS, [1]=DONE, [2]=FAIL, [3]=heartbeat; UART beacon
  shows progress then c1/c0. FSM Verilator-validated. If reads fail, first
  suspect the SDRAM_CLK phase (swap D0/D1 on the ODDR in sdram_gw.sv).
  This gates all MCR-3/Scroll/Mono cores.
- **MCR-1 (Kick/Kickman/Solar Fox) — Phase A builds, not yet on hardware.**
  `src/rtl/mcr1.vhd` + `mcr1_console60k/`; bitstreams
  `bitstreams/console60k_mcr1_{kick,solarfox}.fs` (BSRAM 77/118, setup
  +0.585 ns, checks clean). To verify on hardware:
  `openFPGALoader -b tangconsole -f bitstreams/console60k_mcr1_kick.fs`.
  Open items: hardware bring-up (video/sound/controls); Kick spinner
  sensitivity + DIP defaults (input_3 = 0xFF placeholder) need tuning; OSD
  text rotation direction on the rotated MCR-1 monitors is a guess; SD pack
  switching for MCR-1 needs pack-format-v2 (make_rompack currently MCR-2
  only). One maintenance debt: the MCR-1 top is a copy of the MCR-2 top -
  a future refactor to a unified family-ifdef top would remove the
  duplicated video/USB/SD/OSD infrastructure (deferred to protect the
  working MCR-2 build during its own hardware validation).
- **Tang Primer 25K project is stale**: still the line-buffer video path and
  a Satan's Hollow input map. Fine as-is, but it no longer matches the 60K.
- **Tang Console 138K project is stale**: pre-framebuffer architecture.

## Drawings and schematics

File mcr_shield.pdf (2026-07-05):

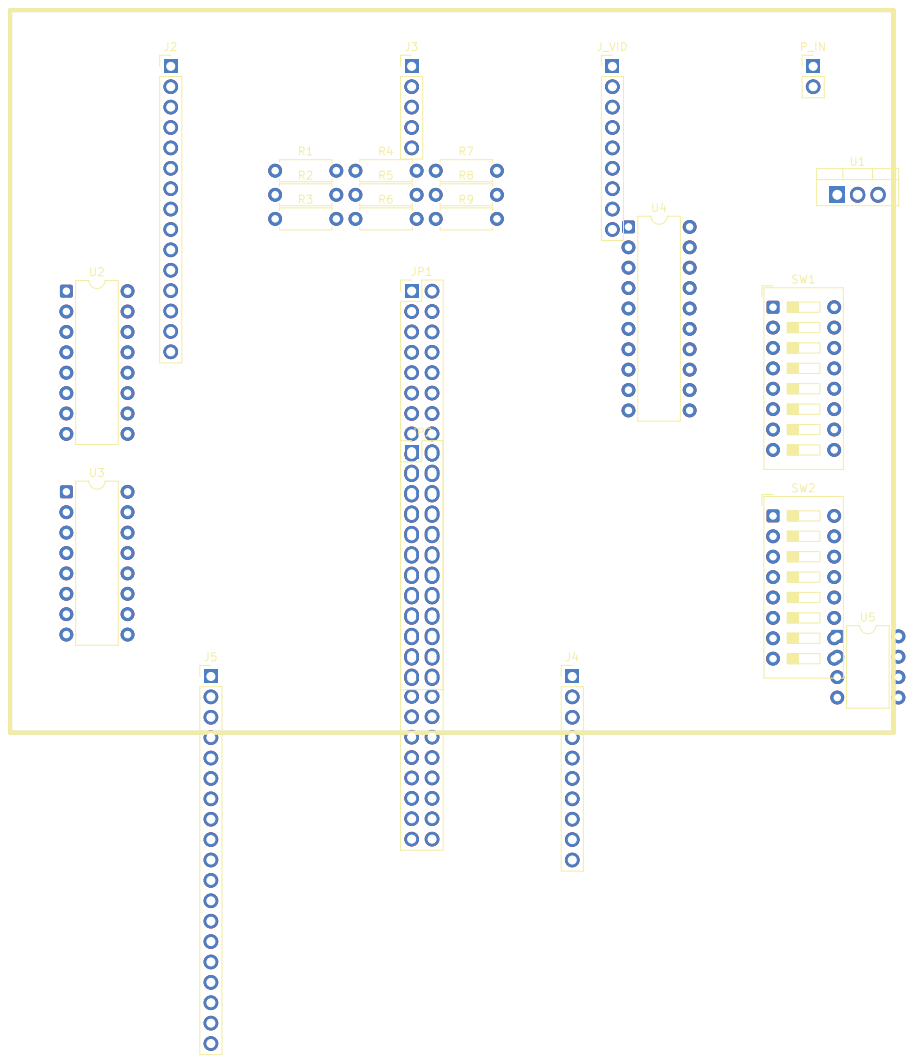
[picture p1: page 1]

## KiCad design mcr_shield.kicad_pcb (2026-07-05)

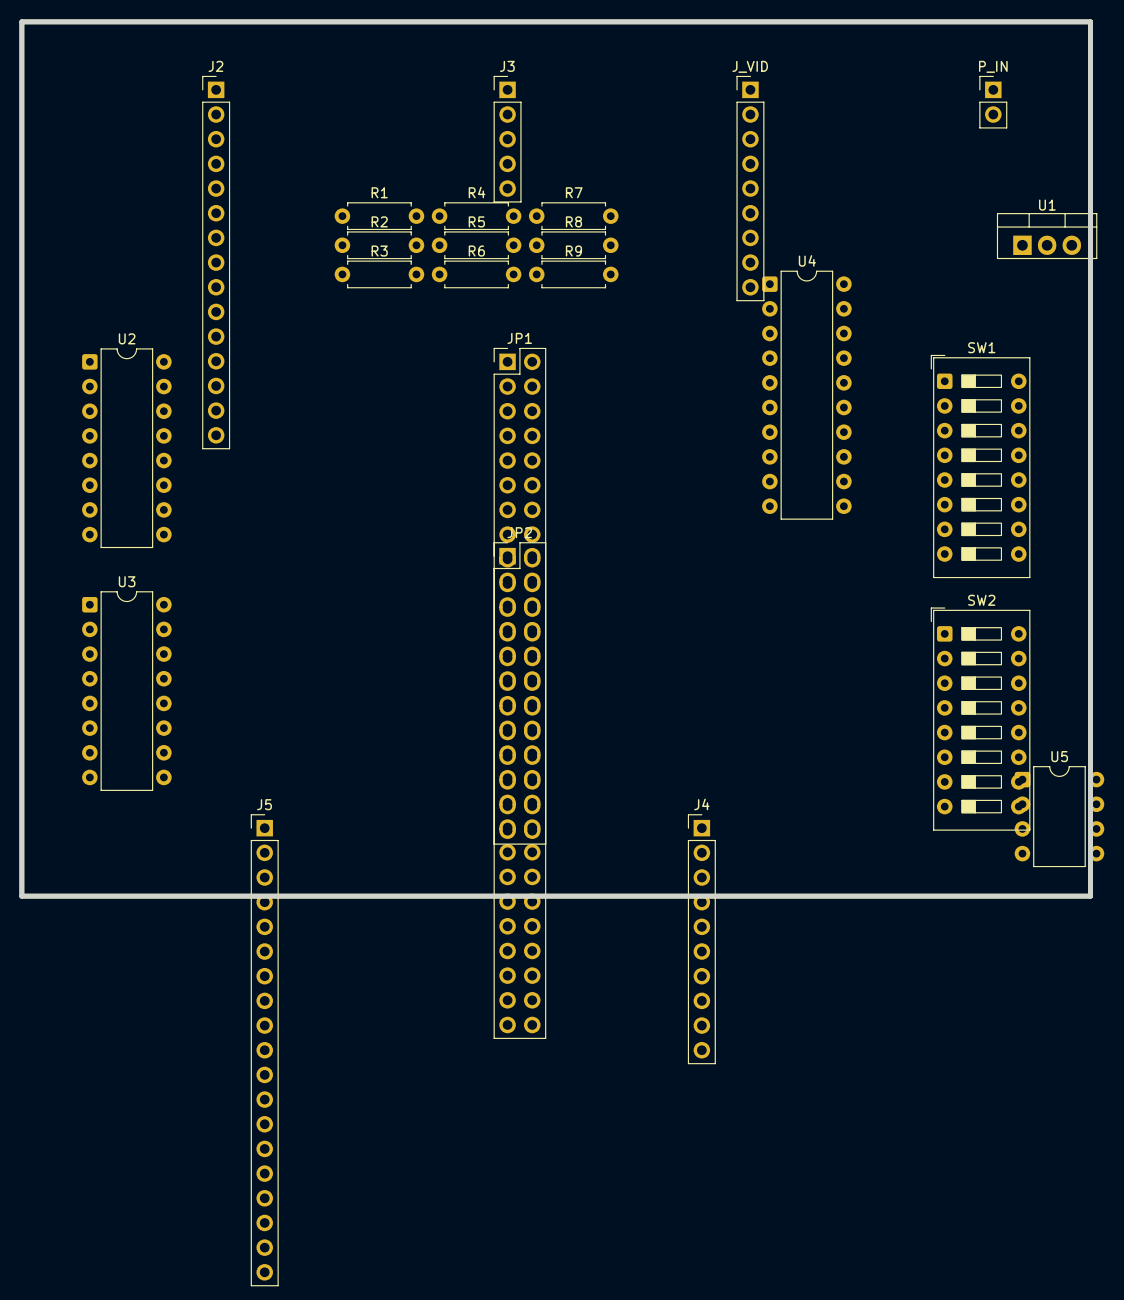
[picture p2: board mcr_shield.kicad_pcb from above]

Board: 2 copper layers, 110.0 x 90.0 mm, 24 parts (0 on the bottom side), 43 nets, no tracks yet.

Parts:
J2: MCR_P1_Controls; PinHeader_1x15_P2.54mm_Vertical
J3: MCR_System_Coin; PinHeader_1x05_P2.54mm_Vertical
J4: MCR_Opt_X_Dial; PinHeader_1x10_P2.54mm_Vertical
J5: MCR_P2_Controls; PinHeader_1x19_P2.54mm_Vertical
JP1: Tang_2x20_H1; PinHeader_2x20_P2.54mm_Vertical
JP2: Tang_2x20_H2; PinHeader_2x20_P2.54mm_Vertical
J_VID: MCR_Video_Out; PinHeader_1x09_P2.54mm_Vertical
P_IN: Power_+12V_GND; PinHeader_1x02_P2.54mm_Vertical
R1: 3.9k_Red_LSB; R_Axial_DIN0207_L6.3mm_D2.5mm_P7.62mm_Horizontal
R2: 2.0k_Red_Mid; R_Axial_DIN0207_L6.3mm_D2.5mm_P7.62mm_Horizontal
R3: 1.0k_Red_MSB; R_Axial_DIN0207_L6.3mm_D2.5mm_P7.62mm_Horizontal
R4: 3.9k_Green_LSB; R_Axial_DIN0207_L6.3mm_D2.5mm_P7.62mm_Horizontal
R5: 2.0k_Green_Mid; R_Axial_DIN0207_L6.3mm_D2.5mm_P7.62mm_Horizontal
R6: 1.0k_Green_MSB; R_Axial_DIN0207_L6.3mm_D2.5mm_P7.62mm_Horizontal
R7: 3.9k_Blue_LSB; R_Axial_DIN0207_L6.3mm_D2.5mm_P7.62mm_Horizontal
R8: 2.0k_Blue_Mid; R_Axial_DIN0207_L6.3mm_D2.5mm_P7.62mm_Horizontal
R9: 1.0k_Blue_MSB; R_Axial_DIN0207_L6.3mm_D2.5mm_P7.62mm_Horizontal
SW1: Game_Selector; SW_DIP_SPSTx08_Slide_9.78x22.5mm_W7.62mm_P2.54mm
SW2: Cabinet_Options; SW_DIP_SPSTx08_Slide_9.78x22.5mm_W7.62mm_P2.54mm
U1: Buck_Regulator; TO-220-3_Vertical
U2: Optocoupler_P1; DIP-16_W7.62mm
U3: Optocoupler_Sys; DIP-16_W7.62mm
U4: Sync_Buffer; DIP-20_W7.62mm
U5: Audio_Amplifier; DIP-8_W7.62mm

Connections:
5V_REGULATED: JP1.40, U1.3
12V_POWER: P_IN.1, U1.1
BTN_FIRE: JP1.3, U2.12
BTN_LEFT: JP1.1, U2.16
BTN_RIGHT: JP1.2, U2.14
BTN_SHIELD: JP1.4, U2.10
CAB_BLUE: J_VID.5, R7.2, R8.2, R9.2
CAB_BTN_FIRE: J2.5, U2.5
CAB_BTN_LEFT: J2.1, U2.1
CAB_BTN_RIGHT: J2.2, U2.3
CAB_BTN_SHIELD: J2.6, U2.7
CAB_GREEN: J_VID.3, R4.2, R5.2, R6.2
CAB_HSYNC: J_VID.8, U4.18
CAB_RED: J_VID.1, R1.2, R2.2, R3.2
CAB_VSYNC: J_VID.9, U4.16
FPGA_B0: JP1.15, R7.1
FPGA_B1: JP1.16, R8.1
FPGA_B2: JP1.17, R9.1
FPGA_G0: JP1.12, R4.1
FPGA_G1: JP1.13, R5.1
FPGA_G2: JP1.14, R6.1
FPGA_HSYNC: JP1.18, U4.2
FPGA_R0: JP1.9, R1.1
FPGA_R1: JP1.10, R2.1
FPGA_R2: JP1.11, R3.1
FPGA_VSYNC: JP1.19, U4.4
GAME_OPT0: JP1.31, SW2.1
GAME_OPT1: JP1.32, SW2.2
GAME_OPT2: JP1.33, SW2.3
GAME_OPT3: JP1.34, SW2.4
GAME_OPT4: JP1.35, SW2.5
GAME_OPT5: JP1.36, SW2.6
GAME_OPT6: JP1.37, SW2.7
GAME_OPT7: JP1.38, SW2.8
GAME_SEL0: JP1.23, SW1.1
GAME_SEL1: JP1.24, SW1.2
GAME_SEL2: JP1.25, SW1.3
GAME_SEL3: JP1.26, SW1.4
GAME_SEL4: JP1.27, SW1.5
GAME_SEL5: JP1.28, SW1.6
GAME_SEL6: JP1.29, SW1.7
GAME_SEL7: JP1.30, SW1.8
GND: J2.13, J4.10, J_VID.2, J_VID.4, J_VID.6, P_IN.2, U1.2, U2.2, U2.4, U2.6, U2.8, U2.9, U2.11, U2.13, U2.15, U4.10, U5.4

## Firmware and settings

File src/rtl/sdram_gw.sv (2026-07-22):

// sdram_gw.sv - Gowin adaptation of the MiSTer Arcade-MCR3 multi-port
// SDRAM controller (refs/Arcade-MCR3_MiSTer/rtl/sdram.sv), vendored 2026-07.
// Only change from upstream: module renamed and the Altera altddio_out
// SDRAM_CLK forwarder replaced with a Gowin ODDR (see below). This is the
// controller MCR-3 will use; the SDRAM memtest exercises it so the physical
// module + pins + clock phase are validated before a core rides on it.
// Runs at ~100 MHz (refresh RFRSH_CYCLES sized for that).
//
// sdram.v
//
// sdram controller implementation for the MiST board
// https://github.com/mist-devel/mist-board
// 
// Copyright (c) 2013 Till Harbaum <till@harbaum.org> 
// Copyright (c) 2019 Gyorgy Szombathelyi
//
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

module sdram_gw #(
	// Cycles between auto-refreshes. Default 842 suits the memtest's 100 MHz
	// clock; the MCR-3 build runs at 80 MHz and overrides to 600 (7.5us < the
	// 7.81us tREF row interval). Sized per SDRAM clock so data is retained.
	parameter [9:0] RFRSH_CYCLES = 10'd842
) (

	// interface to the MT48LC16M16 chip
	inout      [15:0] SDRAM_DQ,   // 16 bit bidirectional data bus (Gowin: driven via the tristate assign below)
	output reg [12:0] SDRAM_A,    // 13 bit multiplexed address bus
	output            SDRAM_DQML, // two byte masks (continuously assigned)
	output            SDRAM_DQMH, // two byte masks
	output reg [1:0]  SDRAM_BA,   // two banks
	output            SDRAM_nCS,  // a single chip select
	output            SDRAM_nWE,  // write enable
	output            SDRAM_nRAS, // row address select
	output            SDRAM_nCAS, // columns address select
	output            SDRAM_CKE,
	output            SDRAM_CLK, 
	
	// cpu/chipset interface
	input             init_n,     // init signal after FPGA config to initialize RAM
	input             clk,        // sdram clock

	input             port1_req,
	output reg        port1_ack,
	input             port1_we,
	input      [23:1] port1_a,
	input       [1:0] port1_ds,
	input      [15:0] port1_d,
	output reg [15:0] port1_q,

	input      [23:1] cpu1_addr,
	output reg [15:0] cpu1_q,
	input      [23:1] cpu2_addr,
	output reg [15:0] cpu2_q,
	input      [23:1] cpu3_addr,
	output reg [15:0] cpu3_q,

	input             port2_req,
	output reg        port2_ack,
	input             port2_we,
	input      [23:1] port2_a,
	input       [1:0] port2_ds,
	input      [15:0] port2_d,
	output reg [31:0] port2_q,
	
	input      [23:2] sp_addr,
	output reg [31:0] sp_q
);

assign SDRAM_CKE = 1;
assign SDRAM_nCS = 0;
assign { SDRAM_DQMH, SDRAM_DQML } = SDRAM_A[12:11];

// Gowin bidirectional DQ: MiSTer drove `inout reg SDRAM_DQ` procedurally,
// which Gowin rejects (EX3900). Model the tristate explicitly instead.
reg  [15:0] sd_dq_out;
reg         sd_dq_oe;
assign SDRAM_DQ = sd_dq_oe ? sd_dq_out : 16'bZ;

localparam RASCAS_DELAY   = 3'd2;   // tRCD=20ns -> 2 cycles@<100MHz
localparam BURST_LENGTH   = 3'b001; // 000=1, 001=2, 010=4, 011=8
localparam ACCESS_TYPE    = 1'b0;   // 0=sequential, 1=interleaved
localparam CAS_LATENCY    = 3'd2;   // 2/3 allowed
localparam OP_MODE        = 2'b00;  // only 00 (standard operation) allowed
localparam NO_WRITE_BURST = 1'b1;   // 0= write burst enabled, 1=only single access write

localparam MODE = { 3'b000, NO_WRITE_BURST, OP_MODE, CAS_LATENCY, ACCESS_TYPE, BURST_LENGTH}; 

// 64ms/8192 rows = 7.8us -> 842 cycles@108MHz
// RFRSH_CYCLES is now a module parameter (see the header) so the 80 MHz MCR-3
// build can shrink it; the memtest leaves it at the 842 default.

// ---------------------------------------------------------------------
// ------------------------ cycle state machine ------------------------
// ---------------------------------------------------------------------

/*
 SDRAM state machine for 2 bank interleaved access
 1 word burst, CL2
cmd issued  registered
 0 RAS0     
 1          ras0, data1 returned
 2 CAS0     data1 returned
 3 RAS1     cas0
 4          ras1
 5 CAS1     data0 returned
 6          cas1, data0 returned (discarded)
 
*/

localparam STATE_FIRST     = 3'd0;   // first state in cycle
localparam STATE_RAS0      = 3'd0;
localparam STATE_RAS1      = 3'd3;   // Second ACTIVE command after RAS0 + tRRD (15ns)
localparam STATE_CAS0      = STATE_RAS0 + RASCAS_DELAY; // CAS phase - 2
localparam STATE_CAS1      = STATE_RAS1 + RASCAS_DELAY; // CAS phase - 5
localparam STATE_READ1     = 3'd2;
localparam STATE_READ1b    = 3'd3;
localparam STATE_READ0     = 3'd6;
localparam STATE_LAST      = 3'd6;

reg [2:0] t;
always @(posedge clk) begin
	t <= t + 1'd1;
	if (t == STATE_LAST) t <= STATE_FIRST;
end

// ---------------------------------------------------------------------
// --------------------------- startup/reset ---------------------------
// ---------------------------------------------------------------------

// wait 1ms (32 8Mhz cycles) after FPGA config is done before going
// into normal operation. Initialize the ram in the last 16 reset cycles (cycles 15-0)
reg [4:0]  reset;
reg        init = 1'b1;
always @(posedge clk, negedge init_n) begin
	if(!init_n) begin
		reset <= 5'h1f;
		init <= 1'b1;
	end else begin
		if((t == STATE_LAST) && (reset != 0)) reset <= reset - 5'd1;
		init <= !(reset == 0);
	end
end

// ---------------------------------------------------------------------
// ------------------ generate ram control signals ---------------------
// ---------------------------------------------------------------------

// all possible commands
localparam CMD_NOP             = 3'b111;
localparam CMD_ACTIVE          = 3'b011;
localparam CMD_READ            = 3'b101;
localparam CMD_WRITE           = 3'b100;
localparam CMD_BURST_TERMINATE = 3'b110;
localparam CMD_PRECHARGE       = 3'b010;
localparam CMD_AUTO_REFRESH    = 3'b001;
localparam CMD_LOAD_MODE       = 3'b000;

reg [2:0]  sd_cmd;   // current command sent to sd ram
reg [15:0] sd_din;
// drive control signals according to current command
assign SDRAM_nRAS = sd_cmd[2];
assign SDRAM_nCAS = sd_cmd[1];
assign SDRAM_nWE  = sd_cmd[0];

reg [23:1] addr_latch[3];
reg [23:1] addr_latch_next[2];
reg [23:1] addr_last[4];
reg [23:2] addr_last2[2];
reg [15:0] din_latch[2];
reg  [1:0] oe_latch;
reg  [1:0] we_latch;
reg  [1:0] ds[2];

reg        port1_state;
reg        port2_state;

localparam PORT_NONE  = 3'd0;
localparam PORT_CPU1  = 3'd1;
localparam PORT_CPU2  = 3'd2;
localparam PORT_CPU3  = 3'd3;
localparam PORT_SP    = 3'd1;
localparam PORT_REQ   = 3'd4;

reg  [2:0] next_port[2];
reg  [2:0] port[2];

reg        refresh;
reg [10:0] refresh_cnt;
reg        need_refresh;
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

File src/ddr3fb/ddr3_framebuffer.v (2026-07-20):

// DDR3-backed framebuffer for Tang Mega 60K and Tang Console 60K
// nand2mario, March 2025
//
// - A framebuffer of any size smaller than 1280x720, backed by a single 16-bit 
//   DDR3 chip. The image is automatically upscaled to 1280x720 and displayed on HDMI.
// - Color depth supported: 12, 15, 18, and 24 bits.
// - Dynamic change of framebuffer size is supported. After change the upscaling
//   logic will adapt to the new size.
// - Image is updated by vsync (`fb_vsync`) and then streaming every pixel (`fb_data` 
//   and `fb_we`).
// - Resource usage: 16 BRAMs, ~3000 LUTs, ~3000 REGs, including DDR3 and HDMI IPs.
//
// Internals,
// - Gowin DDR3 controller IP is used to access DDR3. Accesses are done in 4 pixel 
//   chunks (8x 16-bit words). Each pixel is max 32 bits.
// - 720p timings: 
//      1650=1280 + 110(front porch) + 40(sync) + 220(back porch)
//      750 =720  +   5(front porch) +  5(sync)  + 20(back porch)
//   https://projectf.io/posts/video-timings-vga-720p-1080p/#hd-1280x720-60-hz
// - Pixels are read from DDR3 32 pixels in advance, as DDR3 controller's read latency 
//   is about 22 cycles.
//   x                                0  4  8   ...   WIDTH-36 ... WIDTH
//   prefetch  0  4  8 12 16 20 24 28 32 36 40        WIDTH-4
// - Writes are handled in 4 pixel chunks too. Whenever we have 4 pixels
//   accumulated, we write them to DDR3. Reading takes precedence over writing.
// LOCAL MODIFICATIONS (not upstream gbatang):
//   * DVI_MODE parameter - 1 strips HDMI audio/infoframe packets and sends
//     plain DVI, for displays that refuse our packet layer.
//   * hclk_dbg output - the HDMI pixel clock (pll_hdmi clkout1). This is the
//     clock that actually drives the TMDS pins; clk_out/clk_x1 comes from the
//     DDR3 controller instead, so watching clk_x1 does NOT prove the HDMI
//     clock chain is alive.
module ddr3_framebuffer #(
    parameter WIDTH = 640,           // multiples of 4
    parameter HEIGHT = 480, 
    parameter COLOR_BITS = 18,       // RGB666
    parameter PREFETCH_DELAY = 40,   // buffer is 16 pixels, so 40 accommodates any delay between 24-40 cycles
    parameter DVI_MODE = 0           // 1 = plain DVI (no audio / infoframes)
)(
    output              hclk_dbg,    // HDMI pixel clock (pll_hdmi ODIV1)
    output              hclk5_dbg,   // HDMI 5x serial clock (pll_hdmi ODIV0)
    input               clk_27,      // 27Mhz input clock
    input               clk_g,       // 50Mhz crystal
    input               pll_lock_27,
    input               rst_n,
    output              clk_out,     // 74.25Mhz pixel clock. could be used by user logic
    output              ddr_rst,     // output reset signal for clk_out
    output              init_calib_complete,

    // Framebuffer interface
    input               clk,         // any clock <= 74.25Mhz (or `clk_out`)
    input [10:0]        fb_width,    // actual width of the framebuffer
    input [9:0]         fb_height,   // actual height of the framebuffer
    input [10:0]        disp_width,  // display width to upscale to (e.g. 960 for 4:3 aspect ratio, 1080 for 3:2 aspect ratio)
    input               fb_vsync,    // vertical sync signal
    input               fb_we,       // update a pixel and move to next pixel
    input [COLOR_BITS-1:0] fb_data,  // pixel data
    input [5:0]         ddr_prefetch_delay,    // dynamic DDR3 prefetch delay (1-63, default PREFETCH_DELAY), larger if memory pressure is higher 

    input [15:0]        sound_left,
    input [15:0]        sound_right,

    // DDR3 interface
    output [14:0]       ddr_addr,   
    output [3-1:0]      ddr_bank,       
    output              ddr_cs,
    output              ddr_ras,
    output              ddr_cas,
    output              ddr_we,
    output              ddr_ck,
    output              ddr_ck_n,
    output              ddr_cke,
    output              ddr_odt,
    output              ddr_reset_n,
    output [2-1:0]      ddr_dm,
    inout  [16-1:0]     ddr_dq,
    inout  [2-1:0]      ddr_dqs,     
    inout  [2-1:0]      ddr_dqs_n, 

    // HDMI output
	output              tmds_clk_n,
	output              tmds_clk_p,
	output [2:0]        tmds_d_n,
	output [2:0]        tmds_d_p
);

/////////////////////////////////////////////////////////////////////
// Clocks
wire hclk, hclk5;
assign hclk_dbg = hclk;
assign hclk5_dbg = hclk5;
wire memory_clk;
wire clk_x1 /* synthesis syn_keep=1 */;
assign clk_out = clk_x1;
wire pll_lock;

// dynamic reconfiguration port from DDR controller to framebuffer PLL
reg wr;     // for mDRP
wire mdrp_inc;
wire [1:0] mdrp_op;
wire [7:0] mdrp_wdata;
wire [7:0] mdrp_rdata;
wire pll_stop;
reg pll_stop_r;

// 74.25   pixel clock
// 371.25  5x pixel clock
// 297     DDR3 clock
pll_ddr3 pll_ddr3_inst(
    .lock(pll_lock), 
    .clkout0(), 
//    .clkout1(), 
    .clkout2(memory_clk), 
    .clkin(clk_27), 
    .reset(~pll_lock_27),
    .mdclk(clk_g), 
    .mdopc(mdrp_op),        // 0: nop, 1: write, 2: read
    .mdainc(mdrp_inc),      // increment register address
    .mdwdi(mdrp_wdata),     // data to be written
    .mdrdo(mdrp_rdata)      // data read from register
);

// LOCAL MODIFICATION: HDMI clocks are now a single chain, NESTang-style:
// 27MHz -> gowin_pll_hdmi -> hclk5 (371.25) -> CLKDIV/5 -> hclk (74.25).
// The upstream arrangement (pixel clock = clk_x1 from the DDR3 controller,
// serial clock = a second PLL fed from clk_x1) leaves the OSER10 PCLK/FCLK
// phase relationship to routing luck; it produced no usable TMDS on our
// board even in a minimal design, while this chain displays (see
// diag/nes_video_selftest). The scanout still runs on clk_x1; pixels cross
// into hclk through a shadow-raster + async FIFO below - safe because both
// clocks descend from the same 27MHz reference and cannot drift.
gowin_pll_hdmi pll_hdmi27_inst(
    .clkin(clk_27),
    .clkout(hclk5),
    .lock()
);
CLKDIV #(.DIV_MODE(5)) hclk_div (
    .CLKOUT(hclk), .HCLKIN(hclk5), .RESETN(rst_n), .CALIB(1'b0)
);

reg mdrp_wr;
reg [7:0] pll_stop_count;
pll_mDRP_intf u_pll_mDRP_intf(
    .clk(clk_g),
    .rst_n(1'b1),
    .pll_lock(pll_lock),
    .wr(mdrp_wr),
    .mdrp_inc(mdrp_inc),
    .mdrp_op(mdrp_op),
    .mdrp_wdata(mdrp_wdata),
    .mdrp_rdata(mdrp_rdata)
);    

always@(posedge clk_g) begin
    pll_stop_r <= pll_stop;
    mdrp_wr <= pll_stop ^ pll_stop_r;
    if (pll_stop_r && !pll_stop && pll_stop_count != 8'hff) begin
        pll_stop_count <= pll_stop_count + 1;
    end
end

/////////////////////////////////////////////////////////////////////
// DDR3 controller

// A single 16-bit 4Gb DDR3 memory chip
wire           app_rdy;             // command and data
reg            app_en;
reg    [2:0]   app_cmd;
reg   [27:0]   app_addr;        

wire           app_wdf_rdy;         // write data
reg            app_wdf_wren;
wire  [15:0]   app_wdf_mask = 0;
wire           app_wdf_end = 1; 
reg  [127:0]   app_wdf_data;
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

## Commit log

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2026-07-05 Add game selection and game options DIP switches to 60k/138k pinout mapping table
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2026-07-05 Generate and check in mcr_shield.kicad_pcb file and layout generator script
    [mcr_shield.kicad_pcb]
2026-07-05 Add and route optocouplers, sync buffer, LM386 amp, and buck regulator to KiCad PCB file
    [mcr_shield.kicad_pcb]
2026-07-05 Expand board to 110x90, stack DIPs North/South, and plot thick outlines
    [mcr_shield.kicad_pcb]
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2026-07-05 Remove duplicate Python code from pcb_design.md in favor of standalone script tools/generate_pcb.py
2026-07-05 Fix stray markdown code fence in pcb_design.md
2026-07-11 Update Tang Primer 25K build paths and verify top PMOD DVI pin mapping
2026-07-11 Remove conflicting hardware DONE/READY LED constraints and use L6 user LED for PLL lock indicator
2026-07-18 Live capture-delay tuning (Select+D-pad) reported via UART beacon
    Video confirmed working on hardware after the clk_g fix: DDR3 framebuffer
    720p HDMI is up. Residual left-edge pixel overlap is the capture-window
    delay; make it runtime-tunable (Select held + D-pad Right/Left, D-pad
    masked from the game meanwhile) and report the current value in the
    beacon line as dXX so the sweet spot can be read out and hardcoded.
    Records the clk_g/PR1014 root cause in CLAUDE.md.
2026-07-18 IDE project config: mirror build.tcl's synthesis/PnR settings
    The Gowin IDE reads impl/<project>_process_config.json, not build.tcl, and
    rewrites it with GUI defaults on save - so IDE builds were missing the
    SystemVerilog standard (usb_hid_host.v parse errors) and the dual-purpose
    pin releases (vga_* on J10 land on the CPU-mode config DBUS -> "dedicated
    pin (CPU)" placement errors). Set both, plus TopModule, and document the
    build.tcl <-> JSON mapping in CLAUDE.md.
2026-07-19 Fix IDE Verilog standard token; align placement options with build.tcl
    The Verilog_Standard token I guessed ("Vlg_Std_2017") was invalid, so the
    IDE fell back to Verilog-2001 and uart_beacon.sv's ANSI port initializer
    failed to parse -> "Instantiating unknown module 'uart_beacon'". The IDE's
    own value is "Vlg_Std_Sysv2017". Also sync Place_Option/Ram_RW_Check/
    Multi_Boot to build.tcl so IDE and CLI builds place identically.
2026-07-19 Fix black-screen HDMI on IDE builds: Place_Option must be 2
    Confirmed on hardware. With the DDR3 framebuffer, the Gowin IDE's default
    Place_Option "0" produces a bitstream that builds with zero errors and
    meets timing, but whose DDR3 controller never trains - so no pixel clock
    is generated and HDMI stays black. build.tcl already passed -place_option 2
    (as nand2mario/gbatang does), which is why CLI-built bitstreams always
    worked while IDE- and Windows-built ones were black.
    Set Place_Option/Ram_RW_Check/Multi_Boot in the IDE project config to match
    build.tcl, and document that gw_sh rewrites this file without persisting
    those three - so it churns after every build and only affects IDE builds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
2026-07-19 Add TODO.md consolidating open issues; flag cocktail mode as unaddressed
    Open items were scattered across the shield spec, CLAUDE.md gotchas and the
    handoff docs. Collect them in one index at the repo root.
    Cocktail mode is the newly-noted gap and is bigger than a DIP bit: the
    cabinet DIP is hardcoded upright in every game, player-2 inputs are tied
    off (each game puts them in a different port), Wacko's trackball mux needs
    SSIO output port 4 exposed from mcr2.vhd, and screen flip is unverified
    against the DDR3 framebuffer capture. Two-player use would also want the
    second USB port.
2026-07-19 Clarify how the cocktail switch reaches the core, and per-game IP3 bits
    input_3/IP3 IS the original board's B3 DIP bank as read by the SSIO - an
    internal core signal, not pins. The shield switch runs SW2-3 -> 74HC165 ->
    FPGA -> the game's cabinet bit in input_3; the 165 and input_3 are different
    layers, not alternatives.
    Record the per-game bit positions (bit 1 for Tron/Satan's Hollow, bit 6 for
    Domino/Wacko/Kroozr, none for the Two Tigers conversion set) and flag the
    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
2026-07-19 Add docs/bench_wiring.md: what the current bitstream drives on J10
    The practical wiring info was split between CST comments and the shield
    spec, whose section 4b is the *future* cabinet plan and deliberately differs
    from today's desk-test assignments - an easy way to mis-wire. One page now
    lists the live J10 map, both analogue-video options (resistor DAC into a
    DE-15 breakout, or the PmodVGA with its mandatory 3.3V VCC), the 15/31kHz
    strap, and the debug pins.
2026-07-19 Add a minimal HDMI self-test bitstream (no DDR3, no core)
    640x480 colour bars through the original OSER10/ELVDS path, plus the beacon
    heartbeat. Splits "the board/cable/monitor cannot take HDMI from our
    gateware" from "something specific to the DDR3 framebuffer's HDMI stack",
    which the status beacon alone cannot distinguish: it reports the pixel clock
    running and DDR3 trained even when nothing reaches the connector.
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2026-07-20 HDMI diagnostics: expose hclk, add DVI mode, heartbeat it on the beacon
    HDMI still will not sync although the beacon reports DDR3 trained and the
    pixel clock running. That reassurance was misleading: clk_x1 comes from the
    DDR3 controller, while the TMDS pins are driven by hclk/hclk5 from a
    SEPARATE PLL (pll_hdmi) inside the framebuffer whose lock output is not
    wired anywhere. So we were watching the wrong clock.
    Local modifications to the vendored gbatang framebuffer (marked as such):
    - hclk_dbg output, heartbeated into the beacon's L field high nibble, so a
    dead HDMI PLL is now visible
    - DVI_MODE parameter; the diagnostic build sets it, stripping HDMI audio and
    infoframe packets. Our s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
    [ddr3_framebuffer.v]
2026-07-20 Probe hclk5, the one HDMI clock never verified
    Comparison with NESTang's source shows the HDMI stack is otherwise identical
    - same hdl-util hdmi module, same VIDEO_ID_CODE=4 (720p60), same ELVDS_OBUF
    pattern, equivalent pin constraints. The one difference is the HDMI PLL:
    NESTang runs it from 27MHz with ODIV0=4 (VCO 1485), gbatang from 74.25MHz
    with ODIV0=3 (VCO 1113.75).
    That matters because the beacon proved hclk (ODIV1) is exactly 74.25MHz, but
    hclk5 (ODIV0) - the 371.25MHz clock that actually shifts TMDS bits out - has
    never been measured. A PLL can lock and drive ODIV1 correctly while ODIV0 is
    wrong if that divider is unsupported, which would match every symptom: all
    clocks we checked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
    [ddr3_framebuffer.v]
2026-07-20 Remove the 371MHz probe (it broke DDR3), match NESTang's TMDS constraints
    hclk5 measured at 5x hclk, so the 371.25MHz serial clock is correct and
    ODIV0=3 is fine. Every clock in the HDMI chain is now verified: clk_x1,
    hclk and hclk5.
    The probe itself broke DDR3 calibration (beacon went c1 -> c0): a 25-bit
    counter on an SDC-unconstrained 371MHz clock, which the tool could not see
    the speed of, disturbed the DDR3 interface's placement. Removed, with a
    comment so it is not re-added.
    Also switched back to full HDMI (DVI made no difference) and rewrote the
    TMDS constraints the way nestang/gbatang do - each half of each pair with
    its own IO_LOC, no DRIVE or BANK_VCCIO override. Placement is iden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
2026-07-20 Add fb_selftest: gbatang framebuffer + HDMI, nothing else
    Counterpart to hdmi_selftest. That one proved our own dvi_tx encoder drives
    these pins fine at 640x480 (colour bars display), so the board, cable and
    monitor are all good and the fault is specific to the gbatang stack at 720p
    with its 371.25MHz serial clock.
    This build strips everything else - no MCR core, no USB host, no SD loader,
    no analog video - leaving pll_27 + ddr3_framebuffer fed with a generated
    512x480 pattern, plus the beacon. It partitions the last question:
    pattern displays -> the stack is fine and our full design's congestion
    breaks it (attackable)
    still black -> the stack does not work i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
2026-07-20 HDMI pixel-bridge diagnostics: border/magenta/grey paint per failure stage
    [ddr3_framebuffer.v]
2026-07-21 Spec: OSD replaces game-selection DIPs; SW1 becomes the game's real IP3 bank
    Two decisions from review:
    - The OSD must composite into the core's native RGB BEFORE the video split,
    so the cabinet CRT shows it as well as HDMI - an HDMI-side overlay is
    useless in a cabinet. This implies per-game ROT90 text rendering and
    15 kHz raster support.
    - Physical DIPs stay, but for what operators always used them for: SW1 is
    now wired verbatim as the core's IP3 byte, with per-game meanings straight
    from the 1982 manuals (printed card per game). Game selection - which has
    no authentic physical counterpart - moves to the OSD, opened by the
    cabinet's existing service button, persisted to a res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
2026-07-21 Docs: where MCR DIPs actually live, and the connector-numbering decoder
    Verified against MAME 0.265 across mcr.cpp and mcr3.cpp - all 20 SSIO-based
    games (MCR-1/2/3) use the identical scheme, so the recurring questions now
    have sourced answers:
    - the game DIPs never moved: one bank at SSIO board location B3, read as
    IP3, from Kick (1981) to Discs of Tron (1983); 10 positions, 8 wired
    - DIPs are on the board, not on any connector - buttons/spinners arrive on
    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
2026-07-21 OSD game-select menu + runtime game switching (60K)
    New src/rtl/osd.sv: menu FSM and 8x8 text renderer composited onto the
    core's RGB in the core raster domain, before the video path splits - so it
    appears identically on HDMI, 31 kHz VGA and native 15 kHz. Vertical games
    (Tron, Satan's Hollow - MAME ROT90) get the text drawn rotated for a
    cabinet monitor; direction is a documented guess pending hardware check.
    Font ROM is our own 5x7-in-8x8 artwork (tools/make_osd_font.py ->
    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
2026-07-21 Rebuild all six 60K bitstreams with the OSD menu
    console60k_{shollow,tron,wacko,kroozr,twotiger,domino}.fs regenerated:
    every one BSRAM 94/118, zero PnR errors, worst setup +1.561 ns / hold
    +0.001 ns on the tron reference build. Tree restored to the tron default
    (game_config.vh + committed impl outputs are the tron build).
    The baked game now only decides what boots with no SD card - any of the
    six is reachable at runtime from the OSD with a pack card inserted.
2026-07-21 OSD: frame-sampled buttons with debounce and hold-to-repeat
    Menu navigation edge-detected pad buttons at 40 MHz, but usb_hid_host
    updates its outputs byte-by-byte while each 8 ms HID report streams in, so
    a held button shows transient edges - invisible to the games (they poll
    levels at frame rate) but counted by the menu, making the cursor skip
    (confirmed on hardware). Buttons are now sampled once per vblank: a
    settled snapshot debounces the transients structurally, one event per
    press, auto-repeat after ~0.5 s at ~8 steps/s while held.
    All six bitstreams rebuilt: BSRAM 94/118, worst setup +1.544 ns, clean
    checks; tree restored to the tron default.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
2026-07-21 Add MCR family porting roadmap; document flash-boot command
    docs/mcr_core_roadmap.md: phased plan for MCR-1 (cheap win, BSRAM fit),
    SDRAM bring-up on J9, 91490+SSIO (Tapper class), Squawk & Talk, and the
    scroll/mono boards with their 6809/68000 sound CPUs - grounded in the
    94/118-block budget arithmetic and the MiSTer-devel MCR1/MCR3/MCR3Mono
    sources. TODO.md cores section now points there. CLAUDE.md records the
    openFPGALoader -f flash-boot command (board verified: writes external
    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
2026-07-21 Input stage: 74AHC165 at 3.3 V takes the 5 V harness directly - optos dropped
    AHC inputs are rated to 5.5 V independent of VCC (TI SN74AHC165 /
    Nexperia 74AHC165 - verify the datasheet line at order time), so the
    3.3 V-powered shift register IS the level shifter: 5 V harness levels in,
    3.3 V logic out. Thresholds at 3.3 V (VIH ~2.3 V, VIL ~1.0 V) have wide
    margin against a 5 V idle line and a closed switch. Plain 74HC165 is
    explicitly called out as NOT a substitute (inputs limited to VCC+0.5V).
    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
2026-07-22 Phase A: MCR-1 core (Kick, Kickman, Solar Fox) builds for the 60K
    New board mcr1_console60k/ runs the MCR-1 (90009) video board on the same
    60K platform as MCR-2 - DDR3/HDMI, analog video, USB, SD loader, OSD,
    beacon all shared and unchanged.
    src/rtl/mcr1.vhd: vendored from Arcade-MCR1_MiSTer, patched exactly like
    our mcr2.vhd - exposes hcnt_out/vcnt_out (its video scanner is bit-
    identical to MCR-2, so cap_delay and the whole capture pipeline transfer),
    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
2026-07-22 Docs: current-state handoff (v4) for the 60K multi-core platform
    handoff_v4_60k_multicore.md replaces v3 as the live handoff: what works on
    hardware today (6 MCR-2 games + OSD + SD prefs + HDMI/analog/USB), the MCR
    family runway with a per-phase status table, a hardware-verified-vs-pending
    matrix, the shield summary, and the immediate next steps (flash the SDRAM
    memtest -> unblock MCR-3). v3 gets a "historical" banner pointing forward;
    CLAUDE.md's doc map and README now point at v4 as the entry point.
2026-07-22 Shield pinout: fix stale 'optos' reference in the ground rules (AHC-direct)
2026-07-22 Shield: settle the interface style — cabinet harness plugs into the shield
    Records the decision (spec §0, pinout ground rules, handoff): the shield
    presents the original MCR mating connectors and the cabinet harness plugs
    straight in; the operator picks the game in the OSD and the FPGA maps every
    pin to its in-game function, so nothing is rewired. Explicitly NOT a
    mechanical board-swap (no replicating each game board's PCB-edge socket).
    PCB consequences captured: route the real MCR mating connectors in the
    right positions; rev A targets the SSIO-family connectors (MCR-1/2 + SSIO
    MCR-3 = the majority, and the set in the master pinout matrix); MCR3Mono is
    a later variant (absent from the m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
2026-07-22 shield_wiring: clarify MCR connector pitches (.156 harness vs .100 interboard)
    Corrects an over-generalization (".156 for everything"). MCR used both:
    - .100"/ribbon was the board-to-board interconnect between the stacked
    CPU/video/SSIO boards (MCR FAQ: early SIPP sockets + ribbon "interconnect
    the boards") - the shield replaces the whole boardset, so those don't
    exist for us.
    - .156" is the cabinet harness (controls/coins/video/power) - what the
    shield presents.
    Flags the video connector pitch as the one to verify per game, and records
    the FAQ finding that the dial games' 8-bit Opt-X bus is parallel digital
    (the cabinet's Angle Encoder Board converts the knob quadrature before
    J4/J6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
2026-07-22 docs: propagate the connector-pitch/numbering correction + drop stale optos
    Sweep the remaining shield docs for consistency with the authoritative
    MCR Series Pinouts.html findings (.100" MTA signal connectors, real board
    J-numbering) and the AHC-direct (no-opto) input stage:
    - universal_mcr_shield_spec.md: design principle 1 now points at
    shield_wiring.md / MCR Series Pinouts.html for real connectors + pitch;
    principle 3 rewritten from the abandoned "parallel, opto-isolated" plan
    to the actual serial 74AHC165 chain (no optos, 5.5V-tolerant inputs); a
    stale "cabinet inputs arrive via J10 optos" line fixed to the '165 chain.
    (§4b stays as-is - it is explicitly marked superseded/his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
2026-07-22 sdram_gw: flip SDRAM_CLK to 0 deg - confirmed correct reads on hardware
    The initial 180-deg ODDR phase failed the memtest on the real Tang SDRAM
    module (beacon c0 = fail, module responding but returning wrong data - the
    textbook wrong-phase symptom). Swapping the ODDR to 0 deg (D0=1/D1=0) fixed
    it: the memtest beacon then reported c1 = PASS, so the SDRAM returns correct
    data. This is the one bring-up knob the memtest existed to resolve.
    Note: remote serial reads during bring-up were flaky (Gowin Programmer +
    USB-serial churn), so a clean stable run to done should be confirmed with a
    single terminal / the PASS LED - but the c1 capture confirms the phase.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
    [sdram_gw.sv]
2026-07-22 MCR-3 Tapper - Increment 0: core builds on the platform (sprites blank)
    First MCR-3 board (mcr3_console60k/), now that the SDRAM is verified. This
    increment proves the mcr3.vhd core + CPU + background + video pipeline on
    our platform; the 128 KB sprite ROM is NOT yet wired (sp_graphx32_do tied
    to 0 -> blank sprites). Built like the MCR-1 board: MCR-2 top with the core
    swapped, shared platform (framebuffer/HDMI, analog, USB, OSD, beacon) kept.
    CPU (56 KB)/sound (16 KB)/bg (32 KB) baked in BSRAM; mcr3's extra I/O tied
    off (hflip/vflip=0, mcr2p5=0, output_4 open, hcntout->capture). merge_roms
    gains an mcr3 family + Tapper spec. Tapper input mux (P1 4-way + pour;
    P2/DIP placeholders to verify vs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
2026-07-22 MCR-3 sprites: write via port2 (sp's bank group), fix port2_we typo
    White-boxes bug: the sprite write went to sdram_gw port1 (bank 0,1) but the
    core's sprite read uses the sp port (bank 2,3), so reads never saw the written
    data and returned all-ones -> every sprite rendered as a solid white box.
    Fixes:
    - top: move the SD->SDRAM sprite write from port1 to port2, which shares the
    sp read's bank 2,3 group (this is why MiSTer Arcade-MCR3 uses port2). port1
    now tied off.
    - sdram_gw: the port2 (bank 2,3) PORT_REQ path gated its write-enable on
    port1_we instead of port2_we (a copy-paste from the bank 0,1 block). Never
    exercised before - the memtest only drove port1 - it silently turned eve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
    [sdram_gw.sv]
2026-07-22 MCR-3 sprites: TEMPORARY beacon instrumentation (spw_count / spq_nonff)
    Debugging the still-white-boxes fault. Beacon now reports:
    x = spw_count[23:8] (sprite writes issued; expect ~0x0200 after 128 KB)
    q = spw_count[7:0]
    L bit7 = spq_nonff (1 = sp_q ever read non-all-ones, 0 = stuck FF)
    This is the build currently in SPI flash. Revert this commit once the fault is
    localized. Not yet read: the BL616 UART bridge is wedged (needs a USB-C
    replug / full reboot) so the beacon is silent.
2026-07-22 Add handoff v5: MCR-3 Tapper SDRAM sprite bring-up (active white-boxes debug)
    Captures Phase 1 state: sprites render as solid white boxes (sp_q reads
    constant all-ones). Two bugs fixed (port1->port2 bank group, port2_we typo);
    a third remains. Diagnostic build (beacon spw_count / spq_nonff) is in SPI
    flash. Documents how to read the beacon after the reboot, how to interpret the
    two counters to localize write-vs-read, the full Phase 1 wiring, hardware
    state (sprite pack dd'd to SD, in FPGA), and the Phase 2/3 plan.

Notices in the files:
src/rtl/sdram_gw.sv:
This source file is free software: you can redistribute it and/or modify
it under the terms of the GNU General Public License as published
